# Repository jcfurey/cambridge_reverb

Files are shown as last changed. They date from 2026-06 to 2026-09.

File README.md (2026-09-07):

# Vox Cambridge Reverb (V1031/V1032) — Electronics Rebuild

Complete electronics rebuild of a Vox Cambridge Reverb solid-state guitar amplifier:
the original electronics are gutted and replaced with modern parts while preserving
the original functionality, the front/rear panel layout (no new holes), and the
chassis. Guitar-frequency and 10″ alnico-speaker optimized throughout.

> **Honesty up front:** the Part 1–10 design docs were **reconstructed** from a prior
> conversation (see `docs/PROVENANCE.md`); some values were gap-filled. The KiCad
> project, BOM, and ngspice sims are **generated and tool-verified** (ERC/DRC/SPICE
> all pass), but the board is **placed, not routed**, and a few stages are designed
> substitutes. Treat the signal chain and power section as *validated design intent*,
> and re-verify part numbers/values before ordering or building.

## Core design decisions

| Block | Replacement |
|---|---|
| Power amp | LM1875T (replaces germanium push-pull; eliminates driver transformer T2) |
| Preamp JFETs | MMBF5457 (SOT-23: direct on the SMD variant, on an adapter for THT) or J113 (2N5457 discontinued) — **availability watch**; pins 1 D / 2 S / 3 G (errata #18) |
| Reverb / tremolo | TL072 ×2 (no transformer T3): IC1 = tank driver + **active wet/dry summer**; IC2 = tremolo LFO + **output buffer** |
| Reverb pan | Accutronics 4FB2A1C (~1475 Ω input) — 8 Ω 4AB3C1B is **incompatible** |
| Tremolo modulation | Xvive VTL5C1 or DIY LED/LDR optocoupler, driven by a TL072 Wien LFO — **symmetric, dual-gang 250 k speed pot, 0.6–10.6 Hz** (errata #19: the recovered single-arm pot could not oscillate at tremolo rates); LED-limited LFO + **2N3904 emitter-follower LED driver, 15 dB depth** (errata #22: as drawn the vactrol LED ran at 7 mA DC — a fixed −20 dB pad with 1.7 dB of wobble) |
| Power | LM317T-regulated +17 V rail with **`C_adj`** and an RC-decoupled **`+17V_PRE`** rail for the JFET stages (errata #21: the regulator's noise sat 23 dB above the JFET floor); split `VBIAS_R`/`VBIAS_T`/`VBIAS_3` mid-rails; KBP410G bridge; `VREG_IN` RC pre-filter; **bypassed LM1875 bias divider** (errata #21: as drawn it fed rail ripple ×23 to the speaker — 0.4 Vrms of hum) |
| Tone | **Bass + Treble** (the panel's pots) on a passive James / Thomas-Vox network with a TL074 buffer + make-up (IC3), 470 pF chime cap as a bright cap, and a **MID CUT toggle** (−9.6 dB @ ~800 Hz, broad) in the line-reverse switch hole — errata #20 (the recovered 470 pF-only coupling passed no bass at all) |

## What's verified (all via real tools, in CI-able commands)
- **Schematic:** generated by `kicad/gen/gen_kicad.py` → 8 hierarchical sheets, **ERC 0 violations** (KiCad 8.0.9). 146 components + 28 test points.
- **PCB:** `kicad/gen/gen_pcb.py` places every footprint into the **Part 5 floor-plan zones** (datasheet-derived LM1875 / KBP bridge footprints, real can sizes, Part 4 wire pads, mounting holes; **0 DRC errors, 0 warnings before routing**), plus a **labelled bench test-point strip per zone** (28 `TP_*`: rails, JFET drains, mid-rail refs, every inter-stage node, PA output, a GND pin per zone), then `kicad/gen/route_board.py` **autoroutes headlessly** with Freerouting. **215 of 222 connections routed (incl. the 28 test points), 1 DRC error** (a starved thermal spoke), **0 hits on the two crosstalk clearance rules**, 86 vias, bottom layer kept as a near-solid GND pour (0.9 m of jumpers vs 5.6 m on top); the seven open links are listed in the notes. The board packs tighter since the Bass/Treble stack (errata #20) — the previous placement reached 167/168. See `kicad/PCB-NOTES.md`.
- **Mixed SMD/THT variant** (`kicad/smd/`, **155×90 mm** for the Part 7 safe-bet chassis): same schematic through a second footprint profile — 90 small parts on 0805/1206/1210/SMA/SOD-123/SOT-23, power parts / electrolytics / socketed op-amps / trim resistors / connectors stay THT. **210 of 223 connections routed, 4 DRC errors** (starved thermal spokes), rules clean, on the 155×90 board; the thirteen open links (four of them pour stitching — the price of the crosstalk rules on a 56 %-full board) are listed in the notes. JLCPCB-assembly BOM + position file in `production/smd/`.
- **BOM:** generated from the schematic by `kicad/gen/gen_bom.py` (1:1 with the netlist, no drift) → `bom/bom.csv` + `bom/bom-grouped.csv` (THT) and `bom/bom-smd*.csv` (variant).
- **Noise / hum / crosstalk / thermal** (`docs/06c-…`): `.noise` of the whole front end with the regulator's own noise (EIN 37 → 2.7 µV, SNR at 12 W 34 → 57 dB after errata #21), rail-ripple paths (hum 408 mV → 0.3 mV at the speaker), a vactrol-level tremolo model (depth 1.7 → 15 dB, errata #22), a geometric **crosstalk audit** of both routed boards feeding two routing clearance rules, and an electro-thermal LM1875 model (2.5 K/W sink: Tj 97 °C at 40 °C ambient, worst-case sine).
- **JLCPCB:** both projects carry JLC's 2-layer limits as DRC constraints (two footprints were under the annular-ring minimum and are fixed), the SMD board has fiducials, every SMD capacitor is a basic-library 1206, optional parts are DNP — 7 → 2 extended part types, assembly ≈ $17 for five boards (`kicad/gen/jlc_cost.py`).
- **SPICE:** `spice/run_all.sh` runs 12 ngspice block checks (preamp bias, reverb driver, MRB, tremolo LFO, power amp, **rail-aware** reverb summer, **rail-aware** tone stack, Class-A stage, front-end noise, hum paths, tremolo depth, LM1875 thermal) **plus 6 parameter sweeps** (JFET bias vs R_s across the datasheet Idss spread, Bass / Treble pots + mid-cut switch, LFO speed pot — recovered and fixed networks, Class-A bias, power-amp headroom vs mains ±10 %) and saves every result table to **`spice/results/`** (committed evidence).

## Honest engineering notes (from the audit/roast passes — see `docs/roast-2026-06-16.md`)
- 🔴 **Output power ≈ 12 W, not 18 W.** A single 33.5 V rail can't swing the 17 V peak that 18 W into 8 Ω needs; the LM1875 ceilings at ~12 W clean (~1.8 dB down). Fine for a 10″ combo.
- 🔴 **Fit a MAINS (primary) fuse** — the design's other fuse is only on the secondary. Required for safety.
- ⚠️ **Chassis fit:** the board is **190×115 mm** (matches the original 25-5274-2). Real (text-less) packing is **~40 %** there (THT parts) and **~54 %** for the SMD-profile parts on the Part 7 155×90 "safe-bet" (the THT parts would need 68 % of it) — the earlier 53 % / 90 % figures counted hidden text. Measure the real chassis before committing to a size (errata #9); the placer rebalances to any outline.

## Key constraints
- No new holes in original panels; all improvements internal only.
- MRB hardwired to 600 Hz (original spec); tremolo rate LED is PCB-mounted (diagnostic).
- Original 6-pin DIN footswitch connector and pedal retained.

## Repository layout

```
docs/         Parts 1–10, errata, PROVENANCE, audits (component-availability, roast)
kicad/        Generated KiCad project + gen/ scripts; symbols/ footprints/ gerbers/;
              SCHEMATIC-BUILD / PCB-NOTES / PCB-AUDIT
spice/        ngspice block sims + run_all.sh + models/ (LTspice power-amp kept for provenance)
bom/          bom.csv (generated), bom-grouped.csv, cross-check
datasheets/   sourcing pointers (SOURCES.md)   photos/  capture checklist
production/   fab-package checklist
```

## Tools
- **EDA / verification:** KiCad 8 (`kicad-cli` ERC/DRC). `kicad/gen/check.sh tht|smd` regenerates a profile and writes ERC/DRC reports to `kicad/reports/` (add `--no-regen` to verify a routed board); route with `python3 kicad/gen/route_board.py` (Freerouting 1.9.0 jar + Java + xvfb, see the script)
- **Datasheets:** `datasheets/` holds the manufacturer PDFs the footprints and pinouts were taken from, with a manifest (`SOURCES.md`: file, revision, checksum, which decision it backs)
- **Simulation:** ngspice (`spice/run_all.sh`); LTspice netlist kept for the power amp
- **PCB fab / sourcing:** JLCPCB · Mouser / Digikey

## Status
Reconstructed Parts 1–10 + errata, then multiple verify/audit/roast passes:
generated ERC-clean schematic, floor-plan-placed and **autorouted** PCB, generated
BOM, runnable ngspice suite, and circuit fixes (mains fuse, power-ceiling
correction, active effects-chain redesign, split bias, Bass/Treble tone stack + mid cut).
**Remaining:** hand-review of the autorouted copper (audio-sensitive nets, star
ground, the fat power loop), chassis measurement → final outline, Gerbers, and
bench-tuning the tremolo/MRB. See `CHANGELOG.md`.

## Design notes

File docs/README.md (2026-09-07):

# docs/

Reconstructed design documentation. **Read `PROVENANCE.md` first** — these were
rebuilt from recovered conversation fragments, not the original files.

- `PROVENANCE.md` — how these were reconstructed and what to re-verify
- `01-modernization-guide.md`
- `02-bom-schematics.md`
- `03-wiring-harness.md`
- `04-jlcpcb-fabrication.md`
- `05-thermal-placement.md`
- `06b-spice-simulations.md`
- `06c-noise-hum-crosstalk-thermal.md` — noise, hum, tremolo depth, crosstalk audit, LM1875 thermal model (2026-09-07)
- `07-chassis-measurement.md`
- `08-verified-bom.md`
- `09-transformers-magnetics.md`
- `10-kicad-project.md`
- `errata.md`

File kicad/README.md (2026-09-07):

# kicad/

KiCad project files.

## Present now
- `cambridge_reverb.kicad_pro` — project with reconciled design rules and **three
  net classes** from the consistency pass: Default 0.5 mm / Power 1.5 mm /
  HighCurrent 2.5 mm (errata #11–13). `+33V5`/`SPK_P`/`SPK_N`/`PA_OUT` are pre-assigned
  to HighCurrent by net-name pattern.
- `symbols/cambridge_reverb.kicad_sym` — custom symbols: `VTL5C1`,
  `Reverb_Tank_4FB2A1C`, `Footswitch_DIN6`.
- `footprints/cambridge_reverb.pretty/` — `VTL5C1`, `Inductor_MRB_1H_Toroid`
  (2-pad, 25 mm), **`TO-220-5_Vertical_P1.70mm_LM1875`** (TI NDH inline TO-220-5
  with 1.45 mm pads — fixes the annular-ring DRC error of the stock footprint,
  PCB-AUDIT §1), **`Bridge_KBP_P3.81mm`** (Diodes KBP410G, DS39310, pins
  + ~ ~ −), **`TestPoint_THT_D2.0mm_Label`** (bench test point, value printed on
  silk) and the **`WirePad_*`** wiring pads. `Wiring_Edge_Array_35` (35-pad edge connector) is also in the
  library but **currently unused** — `gen_pcb.py` places per-connector
  **`WirePad_1x0N_P2.54mm_D1.2mm` / `WirePad_1x0N_P5.08mm_D1.5mm`** pads (the Part 4
  signal / power wire-pad sizes) along the wiring edge instead; the 35-pad array
  is kept as a reference (roast R4).
- `sym-lib-table` / `fp-lib-table` — register the project libraries (`${KIPRJMOD}`).
- `netlist-notes.txt` — recovered per-sheet connections (power amp, reverb,
  tremolo, MRB).
- `SCHEMATIC-BUILD.md` — step-by-step to build the 8 hierarchical sheets.

## Generated schematic (now present)
- `cambridge_reverb.kicad_sch` (root) + 8 hierarchical sheets — `power_supply`,
  `preamp`, `tone_stack`, `reverb`, `tremolo`, `mrb`, `power_amp`, `switching`.
  They open in KiCad 7/8, **pass ERC with 0 violations** (KiCad 8.0.9), and
  netlist cleanly (138 components + 28 test points, 0 unconnected pins).
- `symbols/cr_primitives.kicad_sym` — self-contained primitive symbols used by
  the generated sheets.
- `gen/gen_kicad.py` — the generator (regenerate: `python3 kicad/gen/gen_kicad.py`).
- `SCHEMATIC-BUILD.md` — how the sheets are wired, what's verified, and the
  known simplifications to finish before a build.

## PCB (generated: zoned placement + headless autoroute)
- `cambridge_reverb.kicad_pcb` — generated by `gen/gen_pcb.py`: 113 footprints
  placed into the **Part 5 floor-plan zones** (Input/Preamp | Tone | Reverb/Trem |
  Power Amp | PSU, left→right), off-board connectors on the bottom wiring edge,
  LM1875/LM317 on the top edge with the 10 mm keep-out, 4× M3 mounting holes,
  190×115 mm outline, bottom GND pour — **0 DRC errors, 0 warnings before routing**.
- `gen/route_board.py` — **headless autoroute** via Freerouting (DSN → SES →
  import, GND pour refilled). Needs Java + the Freerouting jar (git-ignored; see
  the script docstring). It also injects the per-class *routing* clearances
  (HighCurrent 0.6 mm, TankDrive 1.2 mm) that `cambridge_reverb.kicad_dru` checks
  afterwards for tracks/vias. Routing status and numbers: `PCB-NOTES.md`.
- `gen/crosstalk_audit.py` — geometric **crosstalk screen** of a routed board:
  mutual capacitance of parallel runs between power/AC/tank-drive nets and the
  sensitive nodes, coupled level vs signal, loop gain (Part 6c §4).
- `gen/jlc_cost.py` — JLCPCB assembly **cost model** from the generated BOM (joints,
  basic vs extended part types) — Part 4.
- `gen/check.sh tht|smd [--no-regen]` — regenerate + ERC/DRC with the **JLCPCB
  fab limits** stored in both `.kicad_pro` files (hole-to-hole 0.5, hole-to-copper
  0.3, annular 0.18, mask dam 0.1 mm …) and the custom `.kicad_dru` rules.

## `smd/` — the mixed SMD/THT variant (same schematic, second footprint profile)
- `smd/cambridge_reverb_smd.kicad_pro/.kicad_sch` + the 8 sheets, `smd/cambridge_reverb_smd.kicad_pcb`
  (**155 × 90 mm**, the Part 7 safe-bet size): generated with `--profile smd` by the
  same three scripts. Small passives and semis are SMD (0805 R, 1206/1210 C,
  SMA/SOD-123 D, SOT-23 JFETs); power parts, all electrolytics, the socketed
  TL072s / TL074, the bench-trimmed JFET source resistors, connectors and test points stay
  THT. Lib tables point at the shared `../symbols` / `../footprints`.
  Details and routing status: `PCB-NOTES.md` (SMD variant section).

## Still to do in the KiCad GUI
- Review the autorouted result (it is an autorouter: expect to tidy the audio
  paths, star-ground, and the HighCurrent loop by hand), show reference
  designators on the silkscreen, and confirm the board size against the measured
  chassis (errata #9).
- Gerbers per Part 4 / `production/CHECKLIST.md`.
- `gerbers/` — exported Gerbers (git-ignored; regenerate per Part 4).

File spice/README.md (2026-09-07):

# spice/

ngspice simulations for the design blocks: **8 fixed-point block checks** and
**6 parameter sweeps**. `./run_all.sh` runs everything and writes each result
table to **`results/<name>.txt`** — those files are committed as the evidence for
the numbers below (re-run and diff after any value change). The original set was
LTspice (only the power-amp netlist was recovered verbatim; kept as
`power_amp_lm1875.cir` for provenance, it does not run under ngspice).

Requires ngspice (`apt install ngspice`; verified with ngspice-42).

## Files
| File | Block | What it checks |
|---|---|---|
| `dc_preamp_jfet.cir` | Preamp | JFET bias point + midband gain (recovered R_s = 2.2 k) |
| `ac_reverb_driver.cir` | Reverb driver | Non-inverting gain (11×) |
| `ac_mrb.cir` | MRB | Resonant-peak frequency |
| `tran_tremolo_lfo.cir` | Tremolo LFO | Oscillation + rate at the fast end of the **errata #19** network |
| `ac_power_amp_lm1875.cir` | Power amp | Gain + LF/HF −3 dB with `C_fb_hf` + a 10″ speaker model |
| `tran_reverb_mixer.cir` | Reverb summer | **Rail-aware**: mid-rail bias, unity sum, headroom / clipping |
| `ac_tonestack.cir` | Tone | **Rail-aware**: IC3 bias, noon response, MID CUT on/off (errata #20) |
| `tran_classa_output.cir` | Class-A stage | AB vs A: idle current and crossover THD |
| **`noise_frontend.cir`** | whole front end | `.noise` 20 Hz–20 kHz incl. the LM317's rail noise; EIN, SNR at 12 W, per supply fix (Part 6c) |
| **`ac_hum_psrr.cir`** | PSU → PA / preamp | Rail-ripple paths to the speaker (bias divider, LM317 → JFETs), before / after errata #21 |
| **`tran_tremolo_depth.cir`** | Tremolo | LFO → LED driver → behavioural VTL5C1 → audio: depth in dB, as drawn vs errata #22 |
| **`tran_thermal_lm1875.cir`** | Power amp | Electro-thermal RC ladder: Tj vs heatsink / ambient, heatsink saturation time |
| `models/opamp_noise.sub` | shared | Op-amp macromodel with an en source and noiseless internals, for `.noise` |
| **`sweep_preamp_bias.cir`** | Preamp | **Vd vs R_s for LO / TYP / HI JFET corners** (datasheet Idss 1–5 mA) |
| **`sweep_tonestack.cir`** | Tone | Bass / Treble pot travel + the mid-cut switch |
| **`sweep_lfo_speed.cir`** | Tremolo LFO | Rate and amplitude vs the speed pot (built network) |
| **`sweep_lfo_speed_recovered.cir`** | Tremolo LFO | The recovered single-arm network — evidence for errata #19 |
| **`sweep_classa_bias.cir`** | Class-A stage | Standing current, heat and THD vs the bias spreader |
| **`sweep_pa_headroom.cir`** | Power amp | Clean output ceiling vs the rail (mains −10 % … +10 %) |
| `models/opamp1p.sub` | shared | One-pole op-amp macromodel (small-signal, **no rails**) |
| `models/opamp_rail.sub` | shared | **Rail-aware** one-pole op-amp (output clamped to the supplies) |
| `models/jfet_2n5457.lib` | shared | 2N5457/MMBF5457 nominal model (Idss ≈ 3 mA, Vp = −1.8 V) |
| `run_all.sh` | — | Runs everything, saves `results/`, exit ≠ 0 if ngspice fails |

## Fixed-point results (`results/*.txt`, ngspice-42)
| Block | Measured | Documented | Verdict |
|---|---|---|---|
| Power amp midband gain | **27.21 dB** (23.0×) | 23× / 27.2 dB | ✅ |
| Power amp HF −3 dB | **6.83 kHz** | ~7.2 kHz (`C_fb_hf`) | ✅ |
| Power amp LF −3 dB | **17.2 Hz** | "7.2 Hz" (C_gain only) | ⚠️ input pole adds a second LF corner — fine for guitar |
| Reverb driver gain | **20.83 dB** (11.0×) | 11× | ✅ |
| MRB resonant peak | **577 Hz** | ~610 Hz (1 H ‖ 68 nF) | ✅ (pulled low by the output network) |
| Tremolo LFO, pot at min | **10.59 Hz**, 0.48 V amplitude | 10.6 Hz = 1/(2π·15 k·1 µF) | ✅ (errata #19 network) |
| Preamp drain Vd (R_s = 2.2 k, nominal JFET) | **12.1 V** | 8–9 V target | ⚠️ see the sweep below |
| Reverb summer bias / gain / clip | **8.50 V**, **0.0 dB**, clips 15.5 / 1.5 V | mid-rail, unity, ±7 V | ✅ |
| Tone stack, pots at noon / MID CUT on | **−0.21 dB** flat 100 Hz–10 kHz / **−9.6 dB @ 796 Hz**; all IC3 nodes 8.50 V | flat / ~−10 dB @ ~800 Hz, mid-rail | ✅ (errata #20) |
| Class-A stage AB → A | THD 1.05 % → 0.0025 %, idle 0.11 → 0.49 A | crossover removed | ✅ |
| Front-end noise, as drawn → errata #21 | EIN **37 µV → 2.7 µV** rms; SNR at 12 W **34 → 57 dB** | LM317 noise was 23 dB above the JFET floor | ✅ fixed |
| Hum at the speaker (0.25 Vrms rail ripple), as drawn → #21 | **408 mV → 0.3 mV** rms (−28 → −90 dB re 12 W) | unbypassed PA bias divider | ✅ fixed |
| Tremolo depth, as drawn → errata #22 | **1.7 dB → 15 dB**; insertion loss −19.5 → −0.8 dB | vactrol LED was 7 mA DC | ✅ fixed |
| LM1875 Tj, 2.5 K/W sink, worst sine, Ta 40 °C | **97 °C** (4 K/W: 111; 8 K/W: 149) | < 150 °C | ✅ Part 5 spec confirmed |

## Sweeps
### JFET bias vs R_s across the device spread (`sweep_preamp_bias`, errata #15)
Drain voltage (V) on the +17 V rail with R_d = 10 k. Corners: LO = Idss 1 mA / Vp −0.8 V,
TYP = 3 mA / −1.8 V, HI = 5 mA / −3.0 V (2N5457 & MMBF5457 limits, datasheets committed).

| R_s (Ω) | Vd LO | Vd TYP | Vd HI |
|---:|---:|---:|---:|
| 470 | 11.9 | 3.9 | 1.5 |
| 680 | 12.8 | 6.3 | 1.9 |
| **1000** | 13.6 | **8.5** | 2.9 |
| 1200 | 14.0 | 9.5 | 4.5 |
| 1800 | 14.7 | 11.3 | 7.5 |
| **2200** | 15.0 | 12.1 | **8.8** |
| 2700 | 15.3 | 12.8 | 10.0 |

Reading: the recovered **2.2 k is right for a high-Idss part**; a typical part wants
**~1.0 k**; a low-Idss part (1 mA) cannot reach 8–9 V with any R_s — it needs a
larger R_d or should be rejected. Hence "trim per device": measure Idss once
(drain to +17 V via 10 k, gate/source grounded) and pick R_s from the row above.
This is why `R_s1`, `R_s2`, `R_rec2` stay through-hole even on the SMD variant.

### Bass / Treble pots and the MID CUT (`sweep_tonestack`, errata #20)
Passive James network (250 k lin pots) + TL074 buffer / ×2 make-up, volume at max,
gain in dB re the Q2 drain signal. 0 = fully counter-clockwise (cut), 1 = clockwise (boost).

| Bass pot | 60 Hz | 100 Hz | 200 Hz | 400 Hz | 1 kHz |
|---:|---:|---:|---:|---:|---:|
| 0 (cut) | −11.3 | −7.5 | −3.2 | −1.0 | −0.3 |
| 0.5 | −0.3 | −0.3 | −0.2 | −0.2 | −0.2 |
| 1 (boost) | +5.2 | +4.9 | +3.6 | +1.6 | +0.1 |

| Treble pot | 1 kHz | 2 kHz | 3 kHz | 5 kHz | 10 kHz |
|---:|---:|---:|---:|---:|---:|
| 0 (cut) | +0.2 | −1.1 | −6.8 | −10.7 | −16.5 |
| 0.5 | −0.2 | −0.2 | −0.2 | −0.2 | −0.2 |
| 1 (boost) | −0.2 | +2.4 | +5.0 | +5.5 | +5.6 |

| MID CUT | 200 Hz | 400 Hz | 600 Hz | 800 Hz | 1 kHz | 1.5 kHz | 2 kHz | 4 kHz |
|---:|---:|---:|---:|---:|---:|---:|---:|---:|
| off | −0.2 | −0.2 | −0.2 | −0.2 | −0.2 | −0.2 | −0.2 | −0.2 |
| **on** | −0.9 | −3.2 | −7.1 | **−9.7** | −7.7 | −3.6 | −2.2 | −1.0 |

Noon is flat (the ×2 make-up cancels the network's centre loss); the controls
are asymmetric — more cut than boost — as the passive Vox networks were, and
the mid cut is a broad (Q ≈ 0.6) notch at the "honk" band, not a surgical one.

### Tremolo LFO vs the speed pot (`sweep_lfo_speed` — the built network)
Symmetric Wien, 15 k + one gang of a dual 250 k pot per arm, 1 µF, gain 3.13 + diode limiter.

| Pot (Ω) | f theory | f measured | Vpp |
|---:|---:|---:|----:|
| 0 | 10.61 Hz | **10.58 Hz** | 0.96 |
| 50 k | 2.45 Hz | 2.44 Hz | 0.96 |
| 100 k | 1.38 Hz | 1.38 Hz | 0.96 |
| 250 k | 0.60 Hz | **0.60 Hz** | 0.96 |

### …and the recovered network (`sweep_lfo_speed_recovered` — why it was changed)
Single-arm pot: series 10 k + 0–500 k, shunt 33 k, 100 nF.

| Pot (Ω) | Series R | f theory | Result |
|---:|---:|---:|---|
| 0 | 10 k | 87.6 Hz | oscillates, **79.6 Hz**, 1.6 Vpp |
| 20 k | 30 k | 50.6 Hz | oscillates, 50.2 Hz, 1.1 Vpp |
| 27 k | 37 k | 45.5 Hz | marginal, 0.4 Vpp |
| 35 k … 500 k | 45 k … 510 k | 41 … 12 Hz | **no oscillation** |

The Wien start condition is gain > 2 + R1/R2; with a fixed gain of 3.13 the series
arm must stay under ~37 k, so the recovered LFO ran only over ~5 % of the pot and
never below 45 Hz. Errata #19.

### Class-A bias (`sweep_classa_bias`) — the heat/distortion trade
Single +33.5 V rail, ~0.7 W into 8 Ω (0.38 A peak load).

| Bias per base (V) | Standing current | Standing heat | THD |
|--:|--:|--:|--:|
| 0.60 | 0.111 A | 3.7 W | 1.41 % |
| 0.66 | 0.119 A | 4.0 W | 0.40 % |
| 0.70 | 0.173 A | 5.8 W | 0.049 % |
| 0.72 | 0.276 A | 9.2 W | 0.0084 % |
| **0.74** | **0.488 A** | **16.3 W** | **0.0025 %** |
| 0.76 | 0.845 A | 28.3 W | 0.0022 % |

Crossover distortion is gone once the idle current exceeds the peak load current
(≈ 0.4 A); beyond that only the heat grows. 0.74 V ≙ the 0.5 A CCS in the Class-A
variant (`docs/classA-power-amp.md`).

### Power-amp headroom vs mains (`sweep_pa_headroom`, roast R2)
Rail-aware LM1875 model (vsat 3 V), gain 23, 8 Ω, driven into clipping.

| Rail | Output DC | Clean peak swing | Sine power into 8 Ω |
|--:|--:|--:|--:|
| 30.0 V (mains −10 %) | 15.0 V | 11.9 V | **8.9 W** |
| 33.5 V (nominal) | 16.75 V | 13.7 V | **11.7 W** |
| 37.0 V (mains +10 %) | 18.5 V | 15.4 V | **14.8 W** |

Confirms the ~12 W ceiling (not 18 W) and shows it is a mains-voltage lottery of
±3 W. The output DC tracks V+/2 exactly, which is what `TP_PA_OUT` should read.

## Scope caveat (roast R7)
`opamp1p.sub` is rail-less: gain/bandwidth of isolated blocks only. Large-signal
behaviour is covered only where `opamp_rail.sub` is used (reverb summer, headroom
sweep) and in the transistor-level Class-A stage. The LM1875 is a behavioural
model (Aol, GBW, saturation), not TI's — the headroom numbers are a model of the
ceiling, not a measurement. Component tolerances are covered only where swept.

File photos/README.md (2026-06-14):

# photos/
Chassis measurements, panel layout, and build-progress photos.

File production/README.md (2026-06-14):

# production/
JLCPCB fabrication packages (zipped Gerbers), assembly drawings, pick-and-place.

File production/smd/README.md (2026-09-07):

# JLCPCB assembly inputs — mixed SMD/THT variant (`kicad/smd/`)

Generated; do not hand-edit. Regenerate after any schematic/placement change:

```
python3 kicad/gen/gen_bom.py --profile smd --jlc
kicad-cli pcb export pos --side front --format csv --units mm --smd-only --exclude-dnp \
    -o production/smd/cambridge_reverb_smd-top-pos.csv kicad/smd/cambridge_reverb_smd.kicad_pcb
```

| File | What |
|---|---|
| `bom-jlcpcb.csv` | JLCPCB BOM format (Comment, Designator, Footprint, LCSC Part #) for the **91 placed SMD parts** (29 lines; the two "(opt)" MRB caps are DNP and excluded). The LCSC column is empty on purpose: pick "basic" parts in the JLC parts picker (0805 1 % resistors, 1206 X7R/C0G, S1M, MMBT3904) — only the MMBF5457 and the 3.09 k E96 resistor are unavoidably "extended" ($3/type). `kicad/gen/jlc_cost.py` prints the cost model. |
| `cambridge_reverb_smd-top-pos.csv` | kicad-cli position (CPL) file, top side, SMD only, mm, DNP excluded; includes the three fiducials `FID1–3` (1 mm copper / 2 mm mask) for the placement camera. JLC expects the header names `Designator,Mid X,Mid Y,Layer,Rotation`; rename the columns (Ref→Designator, PosX→Mid X, PosY→Mid Y, Side→Layer, Rot→Rotation) when uploading, or use the "KiCad" template in their uploader. Check SOT-23 / diode rotations in their preview — KiCad's 0° and JLC's 0° differ for some packages. |

The ~76 through-hole parts (power devices, electrolytics, socketed op-amps, the
trimmed JFET source resistors, connectors, test points, vactrol, toroid, fuse
clip) are hand-soldered afterwards; see `bom/bom-smd.csv` for the full list.

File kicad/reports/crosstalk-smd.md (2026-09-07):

### Crosstalk screen — `cambridge_reverb_smd.kicad_pcb`

| Aggressor | Victim | C_m (pF) | longest run (mm) | f | on victim (µV) | vs signal (dB) | loop gain (dB) |
|---|---|---:|---:|---:|---:|---:|---:|
| `TANK_IN` | `TANK_OUT` (tank return (recovery gate)) | 0.18 | 4.6 | 5000 Hz | 166.1 | -42 |  |
| `TANK_IN` | `WET` (reverb level wiper) | 0.21 | 6.5 | 5000 Hz | 966.5 | -50 |  |
| `TANK_IN` | `SUMJ` (summer virtual ground: coupled charge x R_fb -> BLEND (1 V)) | 0.06 | 4.0 | 5000 Hz | 555.2 | -65 |  |
| `PA_OUT` | `PA_INV` (PA -in (1k||22k)) | 0.43 | 7.7 | 5000 Hz | 131.8 | -70 | -97 |
| `PA_OUT` | `PA_BIAS` (PA +in) | 0.05 | 2.6 | 5000 Hz | 165.0 | -76 | -68 |
| `AC1` | `PA_IN` (PA input (22k||22k)) | 0.46 | 26.1 | 150 Hz | 115.5 | -79 |  |
| `TANK_IN` | `QRD` (recovery drain) | 0.02 | 1.7 | 5000 Hz | 20.7 | -83 |  |

Worst feedback loop: `PA_OUT` → `PA_BIAS`: loop gain **-68 dB** (forward 27 dB + coupling -95 dB); stable with margin if well below 0 dB.

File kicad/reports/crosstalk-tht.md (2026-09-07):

### Crosstalk screen — `cambridge_reverb.kicad_pcb`

| Aggressor | Victim | C_m (pF) | longest run (mm) | f | on victim (µV) | vs signal (dB) | loop gain (dB) |
|---|---|---:|---:|---:|---:|---:|---:|
| `TANK_IN` | `TANK_OUT` (tank return (recovery gate)) | 0.07 | 1.9 | 5000 Hz | 62.6 | -50 |  |
| `TANK_IN` | `SUMJ` (summer virtual ground: coupled charge x R_fb -> BLEND (1 V)) | 0.19 | 13.8 | 5000 Hz | 1800.3 | -55 |  |
| `TANK_IN` | `JB` (bass ladder) | 0.51 | 29.2 | 5000 Hz | 2409.9 | -62 |  |
| `TANK_IN` | `DRVP` (tank driver +in) | 0.07 | 5.5 | 5000 Hz | 615.5 | -64 |  |
| `PA_OUT` | `PA_BIAS` (PA +in) | 0.15 | 3.6 | 5000 Hz | 495.1 | -66 | -59 |
| `TANK_IN` | `JTA` (treble ladder) | 0.23 | 29.2 | 5000 Hz | 1079.0 | -69 |  |
| `PA_OUT` | `PA_INV` (PA -in (1k||22k)) | 0.24 | 7.3 | 5000 Hz | 74.6 | -75 | -102 |
| `TANK_IN` | `TONE_OUT` (volume wiper) | 0.03 | 1.3 | 5000 Hz | 147.4 | -77 |  |
| `TANK_IN` | `MID` (mid-cut node) | 0.04 | 1.3 | 5000 Hz | 37.0 | -92 |  |
| `+33V5` | `PA_BIAS` (PA +in) | 0.03 | 2.0 | 150 Hz | 0.1 | -142 |  |

Worst feedback loop: `PA_OUT` → `PA_BIAS`: loop gain **-59 dB** (forward 27 dB + coupling -86 dB); stable with margin if well below 0 dB.

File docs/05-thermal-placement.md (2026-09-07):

# Vox Cambridge Reverb — Part 5: Thermal, Placement & Assembly

> Reconstructed document — see `PROVENANCE.md`. Thermal conclusions, the floor
> plan, and the build timeline are recovered substantially verbatim; some
> numeric derivations are `[RECONSTRUCTED]`.

## Thermal — bottom line (recovered verbatim)

**LM1875 needs a heatsink rated ≤ 2.5 °C/W.** The original V1031 heatsink
bracket should work — it was designed for germanium transistors dissipating
comparable heat. Mount the LM1875 with a mica insulator, shoulder bushing, and
thermal grease.

**LM317 needs no heatsink** — it dissipates ~0.25 W powering the preamp. Bolt it
to the chassis if convenient, but thermally it's a non-issue.

`[RECONSTRUCTED]` **Corrected (roast R2):** the earlier "18 W into 8 Ω" premise is
unreachable on the 33.5 V single rail — the real output ceiling is **~12 W**. At
~12 W the LM1875's worst-case dissipation is *lower* than the old 15–20 W figure,
so with a ≤2.5 °C/W sink + mica the junction stays comfortably within limits (the
sink is over-spec'd, which is safe). Thermal shutdown backstops sustained drive.
Still verify against the LM1875 datasheet SOA/thermal curves for your duty cycle.

`[MODELLED 2026-09-07]` **Part 6c §5** puts numbers on it (`spice/tran_thermal_lm1875.cir`,
2 K/W junction-case + 1.6 K/W greased mica): worst-case continuous sine is **9.4 W** of
dissipation (at 7 W out, not at full power). Junction temperature with a **2.5 K/W** sink:
82 / 97 / 112 °C at 25 / 40 / 55 °C ambient — the spec above holds with margin. **4 K/W**
is still fine to 55 °C (126 °C); **6 K/W** passes a sine test only in a cool room (145 °C
at 55 °C); **8–10 K/W** clip-on sinks reach thermal shutdown on sustained notes. A 40 g
sink saturates in ~5 minutes (τ ≈ 145 s), so a set of loud songs equals the steady-state
sine column. Bolting the tab directly to a grounded sink (single supply: tab = GND) saves
~6 K. The LM317 now carries ~25 mA (IC3 + the tremolo LED driver): 0.4–0.5 W, +25 K bare
— still no heatsink, but chassis-mount it in a hot cabinet.

## Component placement floor plan (recovered verbatim)
```
+-------------------------------------------------------------+
|  190 mm                                                     |
|  +---------+----------+----------+----------+----------+     |
|  | INPUT / |  TONE    | REVERB / |  POWER   |  POWER   |  ^  |
|  | PREAMP  |  STACK   | TREMOLO  |  AMP     | SUPPLY   | 115 |
|  | Q1,Q2   | passives | TL072s   | (LM1875) | BR1,U1   | mm  |
|  |         |          | VTL1     |          | C_main   |  v  |
|  +---------+----------+----------+----------+----------+     |
|  o o o o o o o o o WIRING EDGE (all pads) o o o o o ...      |
+-------------------------------------------------------------+
```
Signal flows left → right. All off-board wiring exits one edge so the board can
flip up for service.

## Keep-out zones (recovered verbatim)
- 10 mm clearance around LM1875 and LM317 mounting area
- No signal traces within 15 mm of transformer wiring pads
- No traces under LFO timing components (noise sensitive)

## Suggested build timeline (recovered verbatim)

| Week | Task |
|---|---|
| 1 | Photograph and document original amp. Test transformer. Remove original PCB. |
| 2 | Create KiCad schematic (Part 2 reference). Run ERC. |
| 3 | PCB layout in KiCad (Parts 4 & 5). Run DRC. |
| 4 | Order PCBs from JLCPCB. Order components from Mouser. |
| 5 | (Wait for delivery — 7–14 days.) |
| 6 | Populate power supply first. Test DC rails. |
| 7 | Populate preamp and tone stack. Test with signal generator. |
| 8 | Populate reverb, tremolo, MRB. Test each effect. |
| 9 | Populate power amp. Test at low volume with series light bulb. |
| 10 | Install PCB in chassis. Wire control and rear panels. |
| 11 | Final testing, biasing, burn-in at full volume. |
| 12 | Button it up, play it, enjoy it. |

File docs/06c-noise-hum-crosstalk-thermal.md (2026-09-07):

# Vox Cambridge Reverb — Part 6c: Noise, Hum, Crosstalk and Thermal Models

> Added 2026-09-07. Everything here is reproducible: the netlists live in `../spice/`
> (`spice/run_all.sh` writes the tables to `spice/results/`), the board audit is
> `kicad/gen/crosstalk_audit.py`. Part 6b covers the functional block checks; this part
> asks the questions a bench would ask *after* the amp works: how quiet, how much hum,
> what talks to what on the board, and how hot.

## 1. Noise — `spice/noise_frontend.cir`

Full front end in one `.noise` run: single-coil pickup (6 kΩ + 2.5 H, 470 pF cable) →
JFET preamp → passive James tone stack + TL074 make-up → summer → output buffer →
LM1875 (×23). Op-amps are 18 nV/√Hz voltage-noise sources (`models/opamp_noise.sub`,
every internal resistor declared noiseless), JFETs carry channel + flicker noise, and the
**+17 V rail carries the LM317's own noise** — TI specifies 0.003 % of V_out rms over
10 Hz–10 kHz, i.e. **~510 µV rms**, ~5 µV/√Hz. That matters because a resistor-loaded
common-source JFET stage has essentially **0 dB PSRR**: v_drain/v_rail = r_ds/(r_ds+R_d) ≈ 0.98.

| Supply configuration | Q2 drain noise (rms, 20 Hz–20 kHz) | Input-referred (EIN) | Hiss at the speaker | SNR at 12 W |
|---|---:|---:|---:|---:|
| **As drawn** (no ADJ cap, JFET loads on the raw +17 V) | **10.3 mV** | **37 µV** | 193 mV rms | **34 dB** |
| + `C_adj` 10 µF on the LM317 ADJ pin (~10× less regulator noise) | 1.26 mV | 4.5 µV | 24 mV | 52 dB |
| + `R_pre` 100 Ω / `C_pre` 220 µF decoupled `+17V_PRE` rail for Q1/Q2/Q_rec | 0.75 mV | **2.7 µV** | 14 mV | **57 dB** |
| (reference: rail noise switched off) | 0.75 mV | 2.7 µV | 14 mV | 57 dB |

The regulator was the dominant noise source by **23 dB**; the last row shows the two
cheap parts bring the preamp to its own floor (2.7 µV rms ≈ 19 nV/√Hz input-referred —
the pickup's 6 kΩ alone is 10 nV/√Hz). Both fixes are in the schematic (errata #21).
Remaining floor by contributor at 1 kHz: JFET channel noise + R_d, then the tone stack's
68 k / 10 k network and the ×2 make-up (~4 dB of the total), then the 100 k summer.

## 2. Hum — `spice/ac_hum_psrr.cir`

1 V of 100/120 Hz ripple on +33V5 (real: ~0.25 Vrms at full drive across 4700 µF),
two paths to the speaker:

| Path | As drawn | Fixed |
|---|---:|---:|
| **(A)** LM1875 input bias divider `R_bias1/R_bias2` 22k/22k from +33V5 — no bypass, the divider feeds the + input directly | **+4.3 dB** (ripple → speaker, i.e. ×1.6) → **408 mV rms of hum, −28 dB re 12 W** | divider node bypassed (`C_bref` 100 µF) and fed to the + input through `R_bias3` 22 k: **−58 dB**, 0.3 mV |
| **(B)** +33V5 → 100 Ω/2000 µF → LM317 (65 dB) → +17 V → JFET drains (0 dB PSRR) → ×13 → ×23 | −57 dB, 0.36 mV | with `C_adj` (80 dB): −72 dB; with the `+17V_PRE` RC too: −95 dB |

Path A was the design's loudest defect: an idle amp humming at −28 dB below full power.
The textbook single-supply input network (bypassed divider + series resistor) is now on
the power-amp sheet; the LM1875's own 52 dB PSRR handles the supply pin. Total hum after
the fixes: **0.3 mV rms at the speaker, −90 dB re 12 W**.

## 3. Tremolo depth — `spice/tran_tremolo_depth.cir`

Errata #19 fixed the LFO; this model follows the modulation to the audio, with a
behavioural VTL5C1 (datasheet LDR-vs-LED-current curve: 20 k @ 1 mA, 600 Ω @ 10 mA,
200 Ω @ 40 mA, 50 MΩ dark; ~5 ms response) shunting the 10 k series resistor.

| | LFO swing | Vactrol LED current | LDR | Insertion loss | **Depth** |
|---|---:|---:|---:|---:|---:|
| As drawn (LED from the depth-pot wiper via 1 k to GND) | 0.50 V pk | 6.4–7.4 mA **DC** | 960–1200 Ω | **−19.5 dB** | **1.7 dB** |
| Redesign | 2.1 V pk | 0–4.7 mA | 1.9 k–50 MΩ | −0.8 dB | **15 dB** |

The LFO sits at the 8.5 V mid-rail, so wiring its LED to ground gave 7 mA of DC with a
±0.5 mA wiggle: the vactrol was a fixed −20 dB pad, not a tremolo. Redesign (errata #22):
the 1N4148 limiter pair becomes two antiparallel **red LEDs** across `R_lfo_fb1` (knee
~1.6 V → 2 V swing; one of them *is* the rate indicator, so `LED_rate`/`R_led_diag` go
away), and an NPN emitter follower (`Q_trem`, 2N3904/MMBT3904), AC-coupled from the depth
pot (`C_drv` 100 µF, base biased at ~0.9 V by 180 k/10 k, `R_e` 470 Ω) drives the vactrol
LED from +17 V through `R_c` 100 Ω: 0…6 mA at the LFO rate, 15 dB of depth at maximum,
0.8 dB insertion loss. The half-wave drive plus the LDR's 35 ms decay give a smooth,
slightly asymmetric pulse — the classic optical-tremolo feel.

## 4. Crosstalk on the routed boards — `kicad/gen/crosstalk_audit.py`

A geometric screen, not a field solver: every pair of parallel track runs (within 20°,
< 4 mm apart, ≥ 0.5 mm overlap) between an *aggressor* net (PA_OUT / SPK / ZOB 9.8 Vrms,
AC1/AC2 24 Vrms, VRAW, +33V5 ripple, TANK_IN 3 Vrms) and a *sensitive* net gets a mutual
capacitance (Howard-Johnson coupled-microstrip estimate over the 1.5 mm ground pour), and
the coupled voltage is `V_aggr · |Z_victim| · 2πf · C_m` against an assumed signal level.
Loop gain = forward gain (node → PA_OUT) + coupling.

Worst pairs on the routing *before* the clearance rules:

| Board | Aggressor → victim | C_m | Coupled vs signal | Loop gain |
|---|---|---:|---:|---:|
| THT | `TANK_IN` → `TANK_OUT` (11 mm parallel run) | 0.30 pF | **−37 dB** | — |
| THT | `TANK_IN` → `QRG` / `WET` | 0.13 / 0.32 pF | −44 / −46 dB | — |
| THT | `PA_OUT` → `PA_INV` | 0.42 pF | −70 dB | −97 dB |
| SMD | `PA_OUT` → `TANK_OUT` (0.25 mm apart!) | 0.09 pF | **−37 dB** | **−44 dB** |
| SMD | `TANK_IN` → `TONE_OUT` (14 mm) | 0.46 pF | −53 dB | — |
| both | AC1 / AC2 / +33V5 → anything | — | < −100 dB | — |

Nothing oscillates (worst loop −44 dB), but the reverb *drive* running beside the reverb
*return* at −37 dB adds an un-reverbed leak to the wet signal, and the power-amp output
0.25 mm from the recovery-JFET gate is not how a hand layout would look. Two rules now
carry this into every routing (`kicad/cambridge_reverb.kicad_dru`, and the same numbers
as per-class clearances in the DSN the router sees): **HighCurrent tracks/vias ≥ 0.6 mm
from signal copper**, **tank-drive tracks ≥ 1.2 mm from the return path** (1.0 / 2.0 mm
were tried first: the router then left 14–27 links open, because a class clearance also
binds the traces entering pads that sit 0.8 mm from a neighbour; the 155 × 90 SMD board
takes 0.4 / 0.8 mm). After re-routing: THT worst pair `TANK_IN` → `TANK_OUT` **−50 dB**
(was −37), `PA_OUT` → `PA_BIAS` −66 dB with loop gain −59 dB; SMD `TANK_IN` → `TANK_OUT`
−42 dB (the two nets share adjacent pads on the tank connector), `PA_OUT` → `TANK_OUT` no
longer in the table, worst loop −68 dB. Full tables: `kicad/reports/crosstalk-{tht,smd}.md`,
routing consequences in `kicad/PCB-NOTES.md`.

## 5. Thermal — `spice/tran_thermal_lm1875.cir`

Electro-thermal RC ladder: junction —2 K/W— case —1.6 K/W (greased mica) or 1.0 (bolted
to a grounded sink; the tab is at V− = GND on a single supply)— heatsink (m·0.9 J/K) —
Rth_SA— ambient. Dissipation on the 33.5 V rail into 8 Ω (class B + 2.3 W quiescent):
idle 2.3 W, **worst-case sine 9.4 W** (at 7 W out, V_pk = V_cc/π), 12 W clip point 8.8 W,
loud music ~4 W average.

Steady-state junction temperature, greased mica (Tj limit 150 °C, shutdown ~170 °C):

| Rth_SA (K/W) | idle, Ta 25/40/55 | **worst-case sine**, Ta 25/40/55 | music, Ta 25/40/55 |
|---:|---|---|---|
| 1.5 | 37 / 52 / 67 | 73 / 88 / 103 | 45 / 60 / 75 |
| **2.5** (Part 5 spec) | 39 / 54 / 69 | **82 / 97 / 112** | 49 / 64 / 79 |
| 4 | 42 / 57 / 72 | 96 / 111 / 126 | 55 / 70 / 85 |
| 6 | 47 / 62 / 77 | 115 / 130 / **145** | 63 / 78 / 93 |
| 8 | 52 / 67 / 82 | 134 / **149** / 164 | 71 / 86 / 101 |
| 10 | 56 / 71 / 86 | **153** / 168 / 183 | 79 / 94 / 109 |

So: the **≤ 2.5 K/W** sink Part 5 asks for keeps the junction under 115 °C even in a
55 °C combo cabinet with a continuous sine — comfortable. A 4 K/W sink is fine to 55 °C
ambient; 6 K/W survives a sine test only in a cool room; 8–10 K/W (a small clip-on) is a
music-only sink that *will* hit thermal shutdown on a long sustained note at high volume.
Bolting the tab straight to a grounded sink saves ~6 K at full dissipation. Time to
saturate: a 40 g sink at 4 K/W has τ ≈ 145 s — the heatsink reaches steady state in
about five minutes, and the transient run (60 s worst-case sine / 60 s music, from cold)
peaks at 113 °C, so a set of loud songs is equivalent to the steady-state sine column for
sizing purposes. The junction itself follows in under a second (τ_jc ≈ 0.7 s).

Other dissipators: **LM317** (32 V → 17 V) with the new IC3 and the redesigned LED driver
carries ~25 mA average, ≤ 32 mA at the tremolo peak → 0.4–0.5 W → +25 K on a bare TO-220
(Rth_JA ~50 K/W free-standing): no heatsink needed, as Part 5 says, but bolt it to the
chassis if the amp lives in a hot cabinet. **KBP410G bridge** at 12 W out: I_dc ≈ 0.64 A,
2 × 0.94 V → 1.2 W, +20–30 K on its leads: fine (rated 4 A). **Transformer**: 33.5 V ×
0.64 A ≈ 21 W DC into the amp at full sine drive → ~35 VA continuous for a capacitor-input
bridge; a **25 VA** unit (AnTek AS-0524) is adequate for music (average draw ≈ ¼ of peak)
and will sag a few volts on a sustained full-power sine — acceptable for a 12 W combo,
but do not size smaller. **MRB toroid** (1 H, 600 Hz at ~0.5 V): 0.13 mA of signal current
— core saturation is not a concern.

## 6. What changed in the design because of this part
- errata #21: `C_adj` 10 µF, `R_pre` 100 Ω + `C_pre` 220 µF (`+17V_PRE`), `C_bref` 100 µF +
  `R_bias3` 22 k.
- errata #22: tremolo LED limiter + `Q_trem` driver; `LED_rate` becomes one limiter LED.
- Routing: `.kicad_dru` clearance rules + DSN class clearances (crosstalk).
- Fab: JLCPCB design-rule limits in both projects, fiducials on the SMD board, wide
  TO-92 and 1.5 mm LM1875 pads for the annular-ring minimum, 1206-only SMD capacitors and
  E24 gyrator values for the basic-parts library (Part 4 update).

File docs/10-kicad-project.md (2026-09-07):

# Vox Cambridge Reverb — Part 10: KiCad Project Files

> Reconstructed document — see `PROVENANCE.md`. The original `.kicad_pro`,
> `.kicad_sch`, and custom libraries were generated as a downloadable zip that
> was not retained. This document records their documented structure so the
> project can be rebuilt; the netlist notes in `../kicad/` carry the recovered
> per-sheet connection detail.
>
> **Update (2026-06-14):** the project file, custom libraries, **and the eight
> hierarchical `.kicad_sch` sheets + root now exist** in `../kicad/`.
> `cambridge_reverb.kicad_pro` carries the corrected three net classes;
> `symbols/cambridge_reverb.kicad_sym` + `symbols/cr_primitives.kicad_sym` hold
> the symbols; `footprints/cambridge_reverb.pretty/` the footprints; and
> `gen/gen_kicad.py` generates the wired schematic. Verified with kicad-cli:
> the hierarchy netlists with **146 components + 28 test points and 0 unconnected
> pins** (94 at first generation; 102 after the VBIAS mid-rail + footswitch-pulldown
> additions; 138 with the errata #19 tremolo and #20 Bass/Treble/mid-cut tone stack; 146 after errata #21-#22). See
> `../kicad/SCHEMATIC-BUILD.md` for connectivity method, the verified results,
> and the known simplifications (op-amp single-supply biasing, TBD tone stack).

## Project structure (as documented)
- `.kicad_pro` — JLCPCB-compatible design rules; **three** net classes (Default
  signals, Power 1.5 mm rails, HighCurrent 2.5 mm speaker/PA — the third added in
  the consistency pass, errata #11); hierarchical sheet structure for 8 blocks.
- `.kicad_sch` — 8 hierarchical sheets following signal flow:
  Power Supply → Preamp → Tone Stack → Reverb → Tremolo → MRB → Power Amp → Switching.
- Custom symbol library: VTL5C1 optocoupler (4-pin), Accutronics reverb tank
  (4-pin), 6-pin DIN footswitch connector.
- Custom footprint library: VTL5C1 (4-pin inline), TO-220-5 wide-pad for the
  LM1875 (`TO-220-5_Vertical_P1.70mm_LM1875`), KBP bridge (`Bridge_KBP_P3.81mm`),
  labelled test point (`TestPoint_THT_D2.0mm_Label`), wire pads (`WirePad_*`),
  plus, for the mixed-SMD variant in `kicad/smd/`, stock 0805/1206/1210/SMA/SOD-123/SOT-23,
  MRB 1H toroid (2-pad, 25 mm
  spacing), 35-pad wiring edge array (3 mm pads, 1.5 mm drill, silkscreen-labeled).

## Rebuilding
Recreate the project in KiCad using Part 2 (schematic values), Part 4 (design
rules/Gerber export), and the netlist notes in `../kicad/netlist-notes.txt`
(recovered per-sheet connections for the power amp, reverb, tremolo, and MRB).

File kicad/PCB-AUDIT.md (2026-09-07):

# PCB layout audit

Audit of `cambridge_reverb.kicad_pcb` (and the `power_section_demo`), done with
KiCad 8.0.9 (`kicad-cli pcb drc`, `pcbnew` geometry queries). First pass
2026-06-15 on the auto-grid starter board; **re-audited 2026-09-06** after the
footprint fixes, the floor-plan placement and the Freerouting pass. Status and
DRC numbers live in `PCB-NOTES.md`; this file is the category-by-category
layout review.

## Verdict (2026-09-06)
Electrically faithful (netlist matches the ERC-clean schematic) and now
**structurally clean before routing: 0 DRC errors, 0 warnings** on the placed
board (was 9 real errors + ~155 silk warnings on the grid-placed board). The two
real footprint defects from the first audit are fixed with datasheet-derived
project footprints, the bulk parts carry their real can/body sizes, and
placement follows the Part 5 floor plan. What remains is engineering judgement
on the *autorouted* copper (see `PCB-NOTES.md`), not layout hygiene.

## 1. Footprints
All components carry a hand-solderable footprint; pad numbers match the symbol
pins — **re-verified against the datasheets 2026-09-06 after finding the JFET
symbol had Gate/Source on the wrong pin numbers (errata #18; both boards fixed)**.
The table is the THT profile; the mixed-SMD variant (`smd/`) swaps the small R /
C / D / JFET rows for 0805 / 1206 / 1210 / SMA / SOD-123 / SOT-23 and keeps the rest.

| Class | Footprint | Verdict |
|---|---|---|
| R (¼ W) | `R_Axial_DIN0207…P5.08mm_Vertical` | ✅ compact vertical |
| JFETs, Q_trem (TO-92) | `TO-92_Inline_Wide` (2.54 mm pitch, 1.5 mm pads / 0.8 mm holes) | ✅ 0.35 mm annular ring; the stock `TO-92_Inline` (1.05 mm pads) had 0.15 mm — under JLCPCB's 0.18 mm minimum (errata #23); the wide pitch also matches the SOT-23→TO-92 adapters |
| LM1875 (TO-220-5, 1.7 mm pitch) | project footprint, pads **1.5 × 2.6 mm** on 1.1 mm holes | ⚠️ 0.20 mm ring: meets JLC's 0.18 absolute minimum, not the 0.25 recommendation (impossible at this pitch without a 1.0 mm drill the 0.97 mm lead diagonal would not survive) |
| R (1 W: `R_27V`) | `R_Axial_DIN0414_L11.9mm…P15.24mm` | ✅ **sized by value** (`gen_kicad.footprint_for`) |
| R (5 W: `R_bleed`) | `R_Axial_Power_L20.0mm_W6.4mm_P25.40mm` | ✅ sized by value |
| `R_spk_rtn` 0 Ω | `R_Axial_DIN0414…` (1 W-size link) | ✅ carries the full speaker current — fat pads, not a ¼ W jumper |
| C (film/disc) | `C_Disc_D7.5…P5.00mm` | ✅ generic |
| CP ≤ 22 µF / 47 µF | `CP_Radial_D5.0mm_P2.00mm` / `D6.3mm_P2.50mm` | ✅ sized by value; tantalums `C_reg_in`/`C_reg_out1` on 2.5 mm spacing |
| CP 1000 µF / 2200 µF / 4700 µF | `CP_Radial_D12.5_P5.00` / `D16.0_P7.50` / `D18.0_P7.50` | ✅ **real can sizes** (Panasonic FC per BOM) — the old board had every can as D8 |
| D / LED | `D_DO-41…` / `LED_D3.0mm` | ✅ |
| JFET | `TO-92_Inline` (THT) / `SOT-23` (smd) | ✅ pads 1 D / 2 S / 3 G per onsemi 2N5457 + MMBF5457 (errata #18) |
| TL072 | `DIP-8_W7.62mm` | ✅ (socket in the real build) |
| LM317 | `TO-220-3_Vertical` | ✅ |
| **LM1875** | **`cambridge_reverb:TO-220-5_Vertical_P1.70mm_LM1875`** | ✅ **FIXED.** TI NDH0005D inline TO-220-5 (1.70 mm pitch, 0.89 × 0.38 mm leads). 1.1 mm drill (as stock) with **1.45 mm pads → 0.175 mm annular** (rule 0.15, JLCPCB 0.13); pad-local clearance 0.2 mm so the 0.25 mm pad gap passes next to the 0.3 mm HighCurrent clearance. Stock footprint gave 0.0875 mm → 5 DRC errors. |
| Fuse | `Fuseholder_Clip-5x20mm…` | ✅ |
| **Bridge** | **`cambridge_reverb:Bridge_KBP_P3.81mm`** | ✅ **FIXED.** Real KBP outline from Diodes DS39310 (KBP404G–KBP410G): 3.81 mm pitch, 1.2 mm drill / 2.0 mm pads, body 14.5 × 3.5 mm, pins **+ ~ ~ −**. Schematic bridge symbol renumbered to match. Was a `PinHeader_1x04` placeholder. |
| Pots ×5 / jacks / DIN / tank | **`WirePad_1x0N_P2.54mm_D1.2mm`** | ✅ Part 4 signal wire pads (2.0 mm / 1.2 mm drill) on the wiring edge; were 2.54 mm pin headers |
| Speaker / transformer | **`WirePad_1x0N_P5.08mm_D1.5mm`** | ✅ Part 4 power wire pads (3.0 mm / 1.5 mm drill) |
| Mounting | 4 × `MountingHole_3.2mm_M3` (NPTH, unique refs H1–H4) | ✅ new; 0.5 mm pour clearance |
| Test points ×26 | **`cambridge_reverb:TestPoint_THT_D2.0mm_Label`** | ✅ 2.0 mm pad / 1.0 mm drill; silk label = the footprint value (net alias) |

## 2. Placement — Part 5 floor plan, generated
`gen_pcb.py` now places into the five documented **zones, left → right**:

```
INPUT/PREAMP | TONE | REVERB/TREMOLO (+MRB) | POWER AMP | POWER SUPPLY
o o o  wiring edge: jacks · pots · tank/pots/DIN · speaker · transformer  o o o
```
- Zone widths are balanced automatically so every column packs to about the
  same height; inside a zone the parts keep their **sheet (signal-chain) order**,
  sorted tallest-first within a sheet so the rows ("shelves") pack tightly with a
  1.3 mm courtyard gap and 4 mm channels between zones.
- **Heat-sinking devices on the top edge**, tab outward, with the Part 5 **10 mm
  keep-out** below them: `IC_PA` (LM1875) above the power-amp zone, `U1` (LM317)
  above the PSU zone — both reachable by a chassis bracket.
- **All off-board wiring on the bottom edge** under its own zone (Part 5: board
  flips up for service); `T1` (transformer) pinned to the far right, so the
  nearest signal zone is a full PSU-zone width away (Part 5: "no signal traces
  within 15 mm of transformer pads").
- **Test-point strip** across the top of each zone: 26 labelled `TP_*` pads
  (footprint `TestPoint_THT_D2.0mm_Label`, value = net alias on silk), one GND
  per zone — the bring-up nodes of Parts 3/5. Table in `PCB-NOTES.md`.
- Reference/value text is hidden (silk clutter); showing refs is a GUI pass.
- Not encoded: "no traces under LFO timing components" — an autorouter cannot
  honour it; check the tremolo area by eye.

## 2b. The SMD variant's placement
Same generator, `--profile smd`: 155 × 90 mm, 6 mm margin, 0.4 mm part gap (0.6
before the errata #20 tone parts), 3 mm channels, pad row kept clear of the corner
holes; the three input-jack pad groups run down the left edge because the bottom
edge is ~9 mm short for 13 connector groups (PCB-NOTES). All four columns fit under
the wiring-edge limit; pre-route DRC 0 errors / 0 warnings beyond the stub warnings.

## 3. Board outline & chassis fit — figure corrected ⚠️
- Outline: **190 × 115 mm**, matching the original 25-5274-2 (errata #9).
- **The earlier density numbers were inflated.** The old `gen_pcb.py` summed
  `GetBoundingBox()` *including the hidden reference/value text boxes*, which
  roughly doubles a resistor's footprint. Text-less bounding boxes give:

| Board | Usable area | Parts area | Packing |
|---|---:|---:|---:|
| 190 × 115 mm (original) | 16 150 mm² | ~5 290 mm² | **~33 %** (was reported 48–53 %) |
| 155 × 90 mm (Part 7 "safe-bet") | 9 450 mm² | ~5 290 mm² | **~56 %** (was reported 82–90 %) |

  So the 155 × 90 board is **no longer "not buildable"** — 60 % (with the test
  points) is dense for THT, and the **mixed-SMD variant actually fits it** at 48 %
  (`smd/cambridge_reverb_smd.kicad_pcb`). Errata #9 still stands: **measure the
  chassis first**, then pick the profile / set `BW, BH` in `gen_pcb.py` and
  regenerate (the placer rebalances the columns).

## 4. Net classes & design rules
- Three classes: **Default 0.5 mm / Power 1.5 mm / HighCurrent 2.5 mm**, with
  0.2 / 0.3 / 0.3 mm clearances; patterns target `+33V5`, `SPK_P`, `SPK_N`,
  `PA_OUT` (HighCurrent) and `VREG_IN`, `+17V`, `GND` (Power). Verified to match
  real nets, and **verified to survive the DSN export** (`route_board.py`), so
  the autorouter uses these widths.
- Rules (from Part 4) are conservative and JLCPCB-safe; the one exception (the
  LM1875 annular ring, §1) is resolved.

## 5. Copper, GND pour, layers
- 2-layer. **Bottom = GND pour** connecting all GND pads; refilled after routing.
- Mounting holes keep 0.5 mm of pour clearance; no isolated-copper items.
- Star-ground / stitching (Part 3/4) remain hand decisions on top of the pour.

## 6. Routing
- Done headlessly with **Freerouting** (`gen/route_board.py`), both in a two-layer
  mode and a **top-only** mode (bottom declared a plane so signals stay on F.Cu,
  the Part 4 intent). Results, unrouted counts and the DRC after import are in
  **`PCB-NOTES.md`**.
- An autorouter does not know audio: expect to tidy by hand the input/JFET-gate
  runs, the LFO area, the speaker/`+33V5` loop and the ground return before fab.

## Prioritized actions for a fab-ready board
1. **Measure the chassis** and lock the outline (errata #9) — regenerate.
2. Review the routed copper (§6) and hand-fix what an autorouter gets wrong.
3. Show reference designators on silk; DRC to zero again.
4. Gerbers per `docs/04-jlcpcb-fabrication.md` + `production/CHECKLIST.md`.

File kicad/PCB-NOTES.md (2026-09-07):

# PCB — generated placement + headless autoroute

`cambridge_reverb.kicad_pcb` is built by two scripts (KiCad 8 `pcbnew` API):

1. **`gen/gen_pcb.py` — placement.** Every footprint from the schematic
   (`gen_kicad.py`'s component list) is placed into the **Part 5 floor plan**:
   columns left → right `INPUT/PREAMP (+TONE below it) | TREMOLO/MRB (+REVERB
   below it, next to its tank pads) | POWER AMP | POWER SUPPLY`, signal-chain
   order inside each zone (ICs and cans tallest-first, small parts in schematic
   order, short parts **stacked** beside tall ones so a can or DIP does not waste
   the row height under every resistor), column widths auto-balanced to equal
   height and repaired until no column overflows, a **labelled test-point strip**
   at the top of every zone (see *Test points*). `IC_PA` (LM1875) and `U1` (LM317)
   sit on the **top edge**, tab outward, with the Part 5 **10 mm keep-out**; all
   off-board wiring lands on **Part 4 wire pads along the bottom edge** (2.0 mm
   signal pads, 3.0 mm speaker/transformer pads), `T1` at the far right. 4 × M3
   mounting holes, 190 × 115 mm `Edge.Cuts`, bottom **GND pour**, **keepout rule
   areas** (2 mm edge frame + squares round the holes, tracks/vias only) so the
   router respects the fab's edge clearance, and two **locked escape stubs** off the
   LM1875's pins 4/5 (see below). Design rules in the `.kicad_pro` are **JLCPCB's
   2-layer limits** (Part 4) and `cambridge_reverb.kicad_dru` adds two crosstalk
   rules (below). **DRC before routing: 0 errors, 0 warnings** apart from the two
   dangling stubs.
2. **`gen/route_board.py` — routing.** Exports a Specctra DSN (the project's three
   net classes come through: 0.5 / 1.5 / 2.5 mm), injects Freerouting's
   `autoroute_settings` (bottom layer 6× trace cost so it is used only for short
   jumpers and the GND pour stays whole; via cost 80), runs **Freerouting 1.9.0**
   under `xvfb-run`, imports the SES and refills the pour.

Regenerate: `python3 kicad/gen/gen_pcb.py && python3 kicad/gen/route_board.py`
(needs Java + `kicad/gen/freerouting.jar` = freerouting-1.9.0.jar, git-ignored;
`apt install xvfb`). **Verify:** `kicad/gen/check.sh tht --no-regen` (or `smd`)
runs ERC + DRC and writes the reports to **`kicad/reports/`** — the committed
`*-erc.rpt` / `*-drc.json` files there are the evidence for every number in this
file. Without `--no-regen` the script regenerates first (which discards routing).

## Routing result — THT board (`kicad-cli 8.0.9 pcb drc`, this commit; `kicad/reports/tht-drc.json`)
| Item | Result |
|---|---:|
| Connections (ratsnest, incl. 28 test points, the dual-gang speed pot, the errata #20 tone stack and the #21/#22 parts) | 222 |
| **Routed** | **215 / 222** (`unconnected_items`: 7) |
| DRC violations (`--severity-all`, JLCPCB limits + `.kicad_dru` crosstalk rules) | **1 error** — `starved_thermal` on the GND pad of `C_rec_byp`; 0 warnings; **0 rule hits** |
| Track segments | 1 421 — **F.Cu 5 645 mm**, B.Cu 902 mm (short jumpers) |
| Vias | 86 |
| Router settings | Freerouting 1.9.0, `-mp 150`, B.Cu trace cost ×7, via cost 60, class clearances HighCurrent 0.6 mm / TankDrive 1.2 mm (`route_board.py --bottom-cost 7 --via-cost 60`) |

The seven open connections: two pieces of **`+33V5`** at the power amp (`C_byp2` ↔ a
bottom jumper at ≈ (113, 62), and a 40 mm top run ending at ≈ (137, 68) — the 2.5 mm
Power trace could not thread the 0.6 mm rule past the PA parts; join at full width),
`JWT` (`R_j4` → the treble-pot pad on the wiring edge), `LFO_OUT` (two trace ends in the
tremolo zone), `R_DRVO` and `TKDRV` (the tank-drive path `C_rev1` / `R_drv3`, held apart
by the 1.2 mm TankDrive rule; 3–10 mm links) and `TREM_S` (`VTL1` LDR → `C_dc_blk`).
Eight GUI touches; listed so nobody trusts the copper blindly.

Honest note: the previous placement (before errata #21/#22) routed to 208/212, DRC clean,
without the crosstalk rules. This placement carries eight more parts and the two
clearance rules; fourteen settings were tried (6–16 open): ×8 / 60 → 6 open but 3 starved
thermals, **×7 / 60 → 7 open + 1 thermal (committed)**, ×6 / 80 → 13, ×7 / 80 → 12,
×8 / 80 → 10, ×9 / 60 → 10; with a 1.0 / 2.0 mm rule set every run left 14; with only
the HighCurrent rule 10–13; with TankDrive at 0.8 mm 8–16. **Evaluate candidates in
place** (next to the `.kicad_pro` / `.kicad_dru`): `kicad-cli pcb drc` on a copy in
another directory silently runs without the net classes and the rules and under-counts
(that cost an hour here). Freerouting is deterministic for identical input but
sensitive to small placement changes — always re-check `kicad/reports/` after
regenerating.

## Mixed SMD / THT variant — `smd/cambridge_reverb_smd.kicad_pcb` (155 × 90 mm)
Same schematic, second footprint profile (`--profile smd` on all three scripts),
sized for the **Part 7 155 × 90 "safe-bet" chassis**. What moves to SMD and what
deliberately does not:

| SMD (90 parts) | Stays THT (and why) |
|---|---|
| 53 × R → **0805** (thin-film for the 1 M gate/input resistors); `R_reg2` → 1206 (85 mW) | LM1875, LM317, KBP bridge, 5 W / 1 W resistors, `R_zobel`, the 0 Ω speaker link — power |
| ≤ 100 nF → **1206** (C0G/NP0 in the signal path, 100 V X7R snubbers) | **all electrolytics** — a radial can standing up uses *less* board than an SMD can |
| 120 nF MRB, 1 µF coupling, `C_zobel` → **1210** (X7R 50/100 V; PPS film on a 2220 pad if you prefer) | TL072 × 2 in **DIP-8 sockets**, the tone TL074 in a **DIP-14 socket** (availability audit: swappable) |
| 1N4007 → **SMA** (S1M); 1N4148 → **SOD-123** (1N4148W) | `R_s1`, `R_s2`, `R_rec2` — bench-trimmed per JFET (errata #15), swap an axial not an 0805 |
| MMBF5457 → **SOT-23** fitted directly (1 D / 2 S / 3 G, errata #18) — no TO-92 adapter | LED, vactrol, toroid, fuse clip, wire pads, test points |

Placement rules for this profile: 6 mm margin (corner M3 holes stay), 0.4 mm part
gap (0.9 mm body-to-body once the courtyards are counted), 3 mm channels;
otherwise the same floor plan, test-point strips and escape stubs. The wiring edge
differs in one point: with the Bass/Treble pots and the MID CUT toggle (errata #20)
the 13 connector groups need ~146 mm and the 155 mm board has 137 mm between the
corner holes, so the **three input-jack pad groups run down the left edge**
(rotated, in the margin next to the preamp — the shortest input wiring); everything
else stays on the bottom edge, `T1` far right. Two more deliberate differences:
- **GND pour on both layers.** SMD ground pads have no through-hole to the bottom
  pour, so the top gets a pour too — connected *solid* to the SMD ground pads only
  (THT pads ground through the bottom pour, no top thermal spokes). The router is
  shown only the bottom plane (`route_board.py` drops the F.Cu plane from the DSN),
  so it drops a via from every SMD ground pad: real copper connectivity, and the
  top pour is extra ground copper on refill. (With both planes visible the router
  treated every SMD ground pad as "done" and 20 of them ended on pour islands.)
- **Net-class widths 2.0 / 1.0 mm** (HighCurrent / Power, 0.25 mm clearance) in
  `smd/cambridge_reverb_smd.kicad_pro`, vs 2.5 / 1.5 on the THT board. Part 4's
  widths were sized for the 190×115 board; at ~1.7 A peak and under 1 A RMS, 1 oz
  copper needs well under 1 mm, and 2.5 mm traces cannot pass between 0805/1206
  pads on a 155×90 board (errata #11 addendum). Parts area **~5 090 mm² → 54 % of the 155 × 90 usable area**
(the THT-profile parts would be 68 %). **Pre-route DRC: 0 errors, 0 warnings** beyond the two stub warnings.

**Routing result (this commit; `kicad/reports/smd-drc.json`)** — `route_board.py --in kicad/smd/cambridge_reverb_smd.kicad_pcb --bottom-cost 6 --via-cost 80` (class clearances HighCurrent 0.4 mm / TankDrive 0.8 mm, the board's `.kicad_dru` numbers):

| Item | Result |
|---|---:|
| Connections (incl. 28 test points, the dual-gang speed pot, tone stack, #21/#22 parts; SMD ground pads count via the top pour) | 223 |
| **Routed** | **210 / 223** |
| DRC (`--severity-all`, JLC limits + rules) | **4 errors** — `starved_thermal` on the GND pads of `IC3` pin 11, `C_s2`, `R_spk_rtn`, `C_rec_byp`; 0 warnings; **0 rule hits** |
| Track segments | 1 154 — F.Cu 3 740 mm, B.Cu 1 124 mm |
| Vias | 120 (most are SMD-ground-pad drops to the bottom pour) |

The thirteen open items: four GND pour fragments (`C_s1`, `C_bref`, `IC1` pin 4 and a
top-pour island — stitching vias), `+33V5` ×2 and `+17V` ×1 (short rail links at the power
amp / tremolo bias, 3–6 mm), `AC1` / `AC2` (the snubber caps `C102` / `C103` to the
transformer pads, 10 mm), `LFO_OUT` (IC2 pin 1 to its trace, 27 mm along the top),
`Q2D` and `Q2G` (two 2 mm gaps in the preamp) and `TKDRV` (tank drive, 14 mm). All are
GUI touches; with the four thermals that is seventeen — the price of the crosstalk rules
on a 56 %-full board.

Sweep on this placement (150 passes; every candidate DRC'd *in place* with the rules):
plain routing (no class clearances) ×7 / 100 → **9 open but 47 rule violations** (32
HighCurrent, 15 TankDrive); 0.4 / 0.8 mm: ×7 / 100 → 13 open + 3 clearance + 3 mask
errors, **×6 / 80 → 13 open, 4 thermals, rules clean (committed)**; 0.35 / 0.6 mm →
12–14 open with 12–14 rule hits; HighCurrent-only 0.4 → 13 open, 8–11 TankDrive hits;
0.6 / 1.2 mm → 13–27 open. The placement before errata #21/#22 routed to 7 open without
rules; the SMD board sits at the router's limit at 155 × 90 (56 % parts by area), so
expect to finish a dozen links by hand after any regeneration — or drop the two rules
in `smd/cambridge_reverb_smd.kicad_dru` and take the 9-open plain routing knowingly.

**Assembly path:** JLCPCB places the SMD side (all are basic-class part sizes),
you hand-solder the ~76 THT parts. `production/smd/bom-jlcpcb.csv` (Comment /
Designator / Footprint / LCSC — LCSC left for the parts picker, nothing invented)
and `production/smd/cambridge_reverb_smd-top-pos.csv` (kicad-cli position file)
are the two inputs. Regenerate:
`python3 kicad/gen/gen_kicad.py --profile smd && python3 kicad/gen/gen_pcb.py --profile smd && python3 kicad/gen/gen_bom.py --profile smd --jlc && python3 kicad/gen/route_board.py --in kicad/smd/cambridge_reverb_smd.kicad_pcb`.

## Test points (bench bring-up, Part 5 order)
26 labelled test points (`TP_*` in the schematic/BOM; footprint
`TestPoint_THT_D2.0mm_Label`: 2.0 mm pad / 1.0 mm drill — fit a header pin or a
bare 0.6 mm wire loop so a scope hook grabs it). They sit in a **strip across the
top of each zone**, the silkscreen prints the alias, and every zone has a **GND**
pin for the probe clip. Expected values are from Part 3's troubleshooting table,
Part 2's set-up notes and the ngspice suite (`spice/README.md`).

| Silk | Ref | Net | Zone | Expect (DC unless noted) | Source |
|---|-----|-----|---|---|---|
| `VRAW` | TP_VRAW | VRAW | PSU | ~33–35 V unloaded, bridge output *before* F1 (fuse check: VRAW ≠ +33V5 → F1 open) | Part 2 |
| `+33V5` | TP_33V5 | +33V5 | PSU | ~33.5 V | Part 3 |
| `VREG` | TP_VREG_IN | VREG_IN | PSU | ~31–33 V (LM317 input after the 100 Ω/1000 µF pre-filter) | Part 3 |
| `+17V` | TP_17V | +17V | PSU | 17.0–17.5 V (R_reg2 = 3.09 k; 16.9 V with 3.0 k) | Part 3, errata #10 |
| `GND` | TP_GND_PSU | GND | PSU | probe ground | — |
| `Q1D` | TP_Q1D | Q1D | Preamp | **8–9 V** target; ~12 V with the recovered Rs = 2.2 k → trim R_s1 (≈1–1.2 k) per device | errata #15, spice |
| `Q2D` | TP_Q2D | Q2D | Preamp | 8–9 V target (same trim, R_s2) | errata #15 |
| `PRE` | TP_PRE_OUT | PREAMP_OUT | Preamp | AC: amplified guitar signal (preamp gain ≈ 22 dB/stage in sim) | spice |
| `GND` | TP_GND_PRE | GND | Preamp | probe ground | — |
| `VB_3` | TP_VBIAS_3 | VBIAS_3 | Tone | ~8.5 V (mid-rail reference for IC3; every IC3 output sits here too) | spice (ac_tonestack) |
| `TMK` | TP_MK_OUT | MK_OUT | Tone | ~8.5 V DC + AC: the Bass/Treble network after the ×2 make-up, before the MID CUT — flat with the pots at noon; toggle SW_MID and 800 Hz drops ~10 dB at `TONE` but not here | spice (sweep_tonestack) |
| `TONE` | TP_TONE_OUT | TONE_OUT | Tone | 0 V DC (after C_tout); AC: volume-pot wiper, the internal FX-send tap (via R_fx_pad) | Part 1 §7, errata #20 |
| `VB_R` | TP_VBIAS_R | VBIAS_R | Reverb | ~8.5 V (mid-rail reference for IC1) | spice |
| `TK_IN` | TP_TANK_IN | TANK_IN | Reverb | AC: tank drive, ≈ 11× the driver input; no DC (after C_rev1) | spice |
| `TK_OUT` | TP_TANK_OUT | TANK_OUT | Reverb | AC: tank return, a few mV–tens of mV; silence → tank/cable | Part 9 |
| `QRD` | TP_QRD | QRD | Reverb | 8–9 V target (recovery JFET drain; trim R_rec2 like R_s1) | errata #15 |
| `BLEND` | TP_BLEND | BLEND | Reverb | ~8.5 V DC (summer output about VBIAS_R) + dry/wet mix AC, unity | spice (tran_reverb_mixer) |
| `GND` | TP_GND_REV | GND | Reverb | probe ground | — |
| `VB_T` | TP_VBIAS_T | VBIAS_T | Tremolo | ~8.5 V (mid-rail reference for IC2) | spice |
| `LFO` | TP_LFO | LFO_OUT | Tremolo | AC: the LFO — **10.6 Hz** with the speed pot at min, **0.60 Hz** at max, ~0.48 V amplitude (0.96 Vpp), sine-ish | spice (tran_tremolo_lfo, sweep_lfo_speed) |
| `TREM` | TP_TREM_OUT | TREM_OUT | Tremolo | AC: post-LDR signal, amplitude pumping at the LFO rate when tremolo is on | Part 1 §5 |
| `PA_IN` | TP_PA_IN | PA_IN | Tremolo | ~8.5 V DC (IC2-B buffer about VBIAS_T) + the full effects-chain signal | roast R3 |
| `GND` | TP_GND_TREM | GND | Tremolo | probe ground | — |
| `MRB` | TP_MRB_OUT | MRB_OUT | MRB | AC: mid-boosted signal, peak ~580–600 Hz | spice (ac_mrb) |
| `PA_B` | TP_PA_BIAS | PA_BIAS | Power amp | ~16.75 V (V+/2 from the 22 k/22 k divider) | Part 2 |
| `PA_OUT` | TP_PA_OUT | PA_OUT | Power amp | **~16–17 V** (LM1875 pin 4, V+/2) — wrong → IC bad or oscillating | Part 3 |
| `SPK` | TP_SPK | SPK_P | Power amp | ~0 V DC after C_out (any DC here → C_out); AC = speaker signal | errata #7 |
| `GND` | TP_GND_PA | GND | Power amp | probe ground | — |

Bring-up order (Part 5): rails (`VRAW`/`+33V5`/`VREG`/`+17V`) with the series
light bulb → `PA_B`/`PA_OUT`/`SPK` DC with no signal → JFET drains (`Q1D`,
`Q2D`, `QRD`) and trim → `VB_R`/`VB_T` → signal generator into IN1, follow
`PRE` → `TMK` → `TONE` → `BLEND` → `TREM` → `MRB` → `PA_IN` → `SPK`.

## Crosstalk screen and the two routing rules it produced (Part 6c §4)
`kicad/gen/crosstalk_audit.py` estimates the mutual capacitance of every parallel run
between an aggressor net (PA_OUT / SPK / ZOB at 9.8 Vrms, the 24 Vrms AC1/AC2, VRAW,
+33V5 ripple, TANK_IN at 3 Vrms) and a sensitive node, and turns it into "coupled level
vs signal" and a loop gain. On the first routing of the errata #20 boards the worst pairs
were `TANK_IN` → `TANK_OUT` (11 mm side by side, **−37 dB**, THT) and `PA_OUT` →
`TANK_OUT` (0.25 mm apart, −37 dB, loop gain −44 dB, SMD); nothing near oscillation,
but not a layout anyone would sign. So:

| Rule (`.kicad_dru`, tracks/vias only) | Clearance | Also given to the router as | Why |
|---|---:|---|---|
| `HighCurrent` (PA_OUT, SPK, +33V5, VRAW, AC1, AC2) ↔ `Default` copper | **0.6 mm** | class HighCurrent clearance 600 µm in the DSN | 9.8 Vrms / 24 Vrms aggressors beside 20 mV–1 V nodes; 1.0 mm was tried first and left 14 (THT) / 27 (SMD) links unroutable |
| `TankDrive` (R_DRVO, TKDRV, TANK_IN) ↔ TANK_OUT / QRG / WET / DRVP | **1.2 mm** | class TankDrive clearance 1200 µm | reverb drive leaking into the reverb return |

Pad geometry is exempt (the LM1875's 1.7 mm pin row, 0805 feedback parts, snubber
caps), which is why the numbers are carried as *rules* rather than net-class clearances.
On the SMD board the rules are 0.4 / 0.8 mm (`smd/cambridge_reverb_smd.kicad_dru`) —
more left the router short of links (see the SMD sweep above).

After re-routing (`kicad/reports/crosstalk-{tht,smd}.md`): THT worst pair `TANK_IN` →
`TANK_OUT` **−50 dB** (was −37), then `PA_OUT` → `PA_BIAS` −66 dB (loop −59 dB); SMD
`TANK_IN` → `TANK_OUT` −42 dB (was −37; the two nets share adjacent pads on the tank
connector, so a few mm of side-by-side copper is unavoidable), `PA_OUT` → `TANK_OUT`
gone from the table, worst loop −68 dB. A hand pass should still move the tank return
away from the drive at the connector — the audit will show whether it helped.

## What the autorouter does NOT know — review by hand before fab
- **Audio layout.** It routes by cost, not by ear: the JFET gate inputs
  (`GUITAR_IN`, `Q1G`/`Q2G`), the reverb recovery input (`TANK_OUT`) and the LFO
  timing nodes may run next to `+33V5`/`PA_OUT`. Move or reroute them; keep the
  tremolo `LFO_*` nets short (Part 5 keep-out: no traces under the LFO timing parts).
- **Grounding.** The bottom pour is one net; the Part 3 **star ground** (power-amp
  return, speaker return, preamp ground) is a hand decision — at minimum keep the
  `C_main`/`R_spk_rtn`/`C_out` returns together and away from the input jacks.
- **HighCurrent loop.** The 2.5 mm `+33V5` / `PA_OUT` / `SPK_P` traces are correct
  in width but the router may loop them around the power-amp column; tighten them.
- **Bottom-layer jumpers** cut the pour locally. Check every GND pad still has ≥ 2
  thermal spokes (the DRC `starved_thermal` check) after any edit.
- **Silkscreen:** reference designators are hidden (regenerate with
  `hide_text=False` in `gen_pcb.py` and tidy in the GUI).

## Why the LM1875 has pre-routed stubs
The TO-220-5 pins are on a **1.70 mm pitch**. With the 0.3 mm HighCurrent/Power
clearance, no trace wider than ~1.35 mm can enter pins 3, 4 or 5 past their
neighbours, so the 2.5 mm `PA_OUT` / `+33V5` traces are physically unroutable to
the pin — every autorouter run left exactly those two connections open. A hand
layout necks the trace down at the pin; `gen_pcb.py` does the same with two
**locked 0.9 mm stubs** (pin 4 straight down 3.5 mm, pin 5 fanned 4 mm right).
Locked tracks export as `(type fix)`, so the router keeps them and attaches the
full-width trace at their ends. 0.9 mm × 3.5 mm of 1 oz copper at ~1.7 A peak is
a non-issue thermally. Pin 3 (GND/V−) needs nothing: it is a through-hole pad in
the bottom pour.

## Freerouting notes (what actually worked)
- **v1.9.0** honours `-mp` (max passes) and always writes the `.ses` — unrouted
  connections stay as ratsnest. Needs an X display even in CLI mode → `xvfb-run`.
- **v2.1.0** in CLI mode ignores `-mp`, `router.max_passes` *and*
  `router.job_timeout`, and only writes output when nothing is unrouted; with one
  hard connection it rips up forever (>400 passes observed). Its multi-threaded
  router also crashed on this board. Not usable for a bounded run.
- **Route the board in place.** `pcbnew.LoadBoard` picks the net classes up from
  the `.kicad_pro` next to the board; a copy routed from another directory came
  back with every track at the 0.2 mm default (199 `track_width` + 201 `clearance`
  errors). `route_board.py` now refuses a board without its project file.
- The router only knows the board *outline*: KiCad's 0.5 mm copper-to-edge rule
  and the mounting holes' local clearance do not reach it, and on the SMD board it
  ran a trace 45 mm along the left edge and under H3. `gen_pcb.py` therefore adds
  **keepout rule areas** (tracks + vias, pours allowed): a 2 mm frame inside the
  edge and a 7.2 mm square round each M3 hole — they export as `(keepout …)`.
- The SES import can leave a few zero-length track segments (`track_dangling`
  warnings); `route_board.py` prunes them.
- The Specctra export refuses duplicate references (the mounting holes are H1–H4
  for that reason). KiCad exports the GND zone as a `(plane)`, so GND pads need no
  traces — but bottom-layer traces slice the pour, which is why the bottom layer
  is made expensive rather than free: a free two-layer run put 2.3–2.5 m of copper
  on the bottom and left 10–11 GND pads on islands.

## Chassis-fit reality check ⚠️ (corrected 2026-09-06)
The earlier 48–53 % / 82–90 % densities counted hidden text in the bounding
boxes. Text-less footprint areas:

| Board | Usable area | Parts area | Packing |
|---|---:|---:|---:|
| 190 × 115 mm (original 25-5274-2) | 16 150 mm² | ~6 450 mm² (THT parts) | **~40 %** |
| 155 × 90 mm (Part 7 "safe-bet") | 9 450 mm² | ~6 450 mm² (THT parts) / ~5 090 mm² (SMD profile) | **~68 %** / **~54 %** |

With the errata #19/#20 parts the THT board's columns use ~97 % of their height
at a 1.2 mm part gap (3.5 mm channels; the placer moves width between columns
until none overflows) — 190 × 115 is now the right size for the THT build, and
the 155 × 90 board only fits with the SMD profile. Errata #9 still applies —
**measure the chassis**, set `BW, BH` in `gen_pcb.py`, regenerate, re-route.

## Power-section routing demo — DRC clean
`power_section_demo.kicad_pcb` (also from `gen_pcb.py`) routes the +33V5 (2.5 mm)
and +17V (1.5 mm) rails by hand over a GND pour as a net-class width reference:
`kicad-cli pcb drc` → 0 violations, 2 ratsnest lines left on purpose (`VRAW`,
`VREG_IN` — the latter needs a via to cross the +17V trunk).

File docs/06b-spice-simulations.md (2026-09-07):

# Vox Cambridge Reverb — Part 6B: Guitar-Optimized SPICE Simulations

> Reconstructed document — see `PROVENANCE.md`. The LM1875 power-amp netlist is
> recovered substantially verbatim. The actual `.cir`/`.asc` source files live
> in `../spice/`. This supersedes the original Part 6.

## Guitar-optimization parameters (recovered verbatim from project)
- 100 pF presence rolloff cap at Q2 drain
- 1 nF feedback cap across LM1875 R_fb → 7.2 kHz bandwidth limit
- 470 pF treble cap for Vox chime character
- Guitar pickup model: 3 H / 6 kΩ / 100 pF, with 300 pF cable capacitance
- 10" speaker model: 105 Hz mechanical resonance + voice-coil inductance

## LM1875 power-amp simulation note
TI provides no official LTspice model for the LM1875, so it is modeled with
`UniversalOpamp2` with parameters matched to LM1875 specs (Aol ≈ 100k, GBW ≈
2.5 MHz, slew ≈ 18 V/µs, Rout ≈ 0.1 Ω), output clipped by the supply rails.
Supply: +33.5 V single rail, 8 Ω load. Closed-loop gain 23× (27 dB).

The full netlist is in `../spice/power_amp_lm1875.cir`. See that folder's README
for the list of the six circuit-block simulations.

## ngspice companion set + verified results (2026-06-14)
The original `.cir` is LTspice-flavored (`UniversalOpamp2`, `opamp.sub`). An
**ngspice-runnable** set was added so the design can be re-verified with an
open-source tool — `apt install ngspice`, then `cd ../spice && ./run_all.sh`.
Measured vs. documented:

| Block | Measured (ngspice-42) | Documented |
|---|---|---|
| Power-amp gain | 27.21 dB (23.0×) | 23× / 27.2 dB ✅ |
| Power-amp HF −3 dB | 6.83 kHz (with `C_fb_hf`) | ~7.2 kHz ✅ |
| Power-amp LF −3 dB | 17.2 Hz | "7.2 Hz" — see below ⚠️ |
| Reverb-driver gain | 20.83 dB (11.0×) | 11× ✅ |
| MRB peak | 577 Hz | ~610 Hz ✅ |
| Tremolo LFO | 10.6 Hz (pot 0) … 0.60 Hz (pot max), 1/(2πRC) with the errata #19 network | RC-set ✅ (swept) |
| Preamp drain | 12.1 V (Rs 2.2 k) | 8–9 V — see below ⚠️ |
| Tone stack (errata #20) | noon flat −0.2 dB; bass −7.5…+4.9 dB @ 100 Hz; treble −16.5…+5.6 dB @ 10 kHz; MID CUT −9.6 dB @ 796 Hz | James network + gyrator notch ✅ (swept) |

Two corrections fell out of running it: the power-amp LF corner is ~17 Hz (the
input pole adds to `C_gain`; fine for guitar), and the preamp wants Rs ≈ 1–1.2 kΩ
(not 2.2 kΩ) to hit the 8–9 V drain target. Both are in `errata.md` and
`../spice/README.md`.

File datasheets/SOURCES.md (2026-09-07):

# Datasheet sources — committed PDFs and what each one backs

The PDFs in this folder are the manufacturer documents the footprints, pinouts and
design numbers were taken from. They are **committed on purpose** (the previous
policy of not committing them was reversed 2026-09-07): a footprint or a pin
number is only as good as the drawing it came from, and errata #18 (JFET pins)
showed why the exact revision matters. Re-download from the source URL when
re-verifying before an order; the SHA-256 prefix identifies the revision used here.

| File | Part | Source | Revision | Used for | SHA-256 (16) |
|---|---|---|---|---|---|
| `LM1875_TI_SNAS524A.pdf` | LM1875T power amp | ti.com/lit/ds/symlink/lm1875.pdf | SNAS524A, May 2004 | TO-220-5 NDH0005D package drawing (1.70 mm pitch, 0.89×0.38 mm leads) → footprint `TO-220-5_Vertical_P1.70mm_LM1875`; pinout 1 IN+ 2 IN− 3 V− 4 OUT 5 V+ | `049a5385f4720ade` |
| `LM317_TI.pdf` | LM317T regulator | ti.com/lit/ds/symlink/lm317.pdf | SLVS044Z, rev. April 2025 | Vout = 1.25 (1 + R2/R1) (errata #10); TO-220 pinout ADJ/OUT/IN | `323ec64a58515090` |
| `TL072_TI.pdf` | TL072 dual op-amp | ti.com/lit/ds/symlink/tl072.pdf | SLOS080W, rev. July 2025 | DIP-8 pinout; supply range for the single-supply +17 V design; slew/GBW behind `opamp*.sub` | `40b14981bad45917` |
| `MMBF5457_onsemi_2023-01_Rev1.pdf` | MMBF5457 JFET (SOT-23) | onsemi.com/pdf/datasheet/mmbf5457-d.pdf | Rev. 1, January 2023 | **SOT-23 pinout 1 D / 2 S / 3 G** — the symbol renumbering of errata #18; SMD-variant footprint | `94751083a9322c4c` |
| `2N5457_onsemi_2010-02_Rev6.pdf` | 2N5457 JFET (TO-92, discontinued) | onsemi.com/pdf/datasheet/2n5457-d.pdf | Rev. 6, February 2010 | **TO-92 lead order 1 Drain / 2 Source / 3 Gate** (errata #18); Idss/Vp spread behind the errata #15 bias trim | `d547280c34509502` |
| `J111-J113_onsemi_2006-03_Rev2.pdf` | J111/J112/J113 JFET (TO-92 alternative) | onsemi.com/pdf/datasheet/j111-d.pdf | Rev. 2, March 2006 | The THT-alternative JFET (BOM): same D-S-G lead order; check Vgs(off) vs the 2N5457 when substituting | `8ceafd60592e75de` |
| `KBP404G-KBP410G_Diodes_DS39310.pdf` | KBP410G bridge rectifier | diodes.com/datasheet/download/KBP404G-KBP410G.pdf | DS39310 Rev. 3-2, February 2026 | **KBP outline** (3.81 mm pitch, 0.86×0.55 mm leads, 14.5×3.5 mm body) and the **+ ~ ~ −** pin order → `Bridge_KBP_P3.81mm`, bridge symbol renumbered | `c13e1a92de6bc9d3` |
| `KBP005G-KBP10G_Diodes_DS21203.pdf` | KBP005G–KBP10G (same KBP package, 1.5 A) | diodes.com/assets/Datasheets/ds21203.pdf | DS21203 Rev. 13-2, August 2025 | Cross-check that the KBP outline is identical across the family | `a714169960729a36` |
| `1N4001-1N4007_Vishay.pdf` | 1N4007 (D1, D2 output clamps) | vishay.com/docs/88503/1n4001.pdf | 29-Apr-2020 | DO-41 dimensions (THT board) | `56a77c6615c90c11` |
| `1N4148_Vishay.pdf` | 1N4148 (D_lfo1/2 LFO clamp) | vishay.com/docs/81857/1n4148.pdf | Rev. 1.6, 07-Nov-2024 | DO-35 dimensions (THT board) | `aefe85400a427ed8` |
| `1N4148W_BAV16W_Diodes_DS30086.pdf` | 1N4148W (SOD-123, SMD variant) | diodes.com/assets/Datasheets/ds30086.pdf | DS30086 Rev. 31-2, September 2024 | SOD-123 replacement for 1N4148 on the SMD board | `39c16a6888bdab22` |
| `VTL5C1_VTL5C2_PerkinElmer_Vactec.pdf` | VTL5C1 vactrol (Xvive remake) | logosfoundation.org/instrum_gwr/playerpiano/Optor_VTL5C1_87223.pdf (hosted copy of the PerkinElmer/Vactec catalog page) | catalog p. 43 (undated) | Package dimensions behind the `VTL5C1` footprint; on/off resistance, response time for the tremolo depth. Xvive publishes no PDF — their part is a drop-in remake | `e6cdace0ba7d05bb` |
| `AS-0524_AnTek.pdf` | AnTek AS-0524 toroid (optional T1) | antekinc.com/content/AS-0524.pdf | AnTek test sheet (undated) | Secondary voltage / VA and the open- and short-circuit test data (Part 9) | `76013dad454a445f` |

## Not committed (no PDF obtainable, or not a single document)

| Part | Why | Where the numbers came from |
|---|---|---|
| **S1M** (SMA rectifier, SMD variant) | Diodes' S1A–S1M sheet was not reachable from this session (404). Any S1M / SMA 1 kV 1 A part is a drop-in; the footprint is KiCad's stock `D_SMA`. | KiCad library footprint; generic JEDEC DO-214AC |
| **KBU4M** (alternative bridge, errata #3) | onsemi's KBU4A–KBU4M sheet was not reachable. KBU is a 5.08 mm-pitch package and needs a footprint swap. | not used on either board |
| **Accutronics / Belton 4FB2A1C** reverb pan | No manufacturer PDF; the distributor spec table is the reference. Input 1475 Ω (200 Ω DC), output 2250 Ω (200 Ω DC), decay 1.75–3.0 s, 2×2 springs, 42.5 × 11 × 3.3 cm, in/out grounded. | amplifiedparts.com/tech-articles/accutronics-products-and-specifications |
| TL072 SPICE model | not a datasheet; the ngspice macromodels are in `spice/models/` | — |

## Reverb-pan code reminder
The Accutronics/Belton 4-digit-plus code encodes the tank: confirm the part is
**4FB2A1C** (high-impedance input ~1475 Ω) and **not** 4AB3C1B (8 Ω input,
incompatible with the direct TL072 driver — see Part 9 / errata Issue 14).

## Verification reminder
Stock and part status drift (see Part 8). Re-check live availability at
Digikey/Mouser and confirm the JFET and bridge selections before ordering — and
if a datasheet revision changes, re-check the package drawing against the
footprint in `kicad/footprints/cambridge_reverb.pretty/`.

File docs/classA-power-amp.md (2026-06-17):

# Class-A power amp — "what it wanted to be" (exploration)

Running the power amp in **Class A** for an AC15-style voice. This note has the
real numbers (simulated) and the honest trade. **Status: explored, not yet built
into the main design** — it's a real architectural change with thermal
consequences (see the question at the end).

## Why it's worth it (the tone)
`spice/tran_classa_output.cir` (transistor-level, single +33.5 V rail, ~0.7 W into
8 Ω) compares the output stage at AB vs Class-A bias:

| Mode | Idle current | THD @ ~0.7 W | What you hear |
|---|---:|---:|---|
| Class **AB** (small idle) | ~0.11 A | **1.05 %** | crossover notch — the SS "stiffness" |
| Class **A** (idle ≥ peak load I) | ~0.49 A | **0.0025 %** | no crossover — smooth, even-harmonic compression |

That ~400× drop in distortion (the crossover region simply vanishes) is exactly
the smooth, compressed, "chimey" character people chase in an AC15. For a guitar
amp the magic is at **low-to-mid volume**, which is precisely where Class A lives.

## The catch (the heat) — Class A is a furnace
Class A draws its full idle current **continuously, signal or not**. On a single
33.5 V rail an idle of ~0.5 A is:

- **~16 W of continuous heat** at idle…
- …for a **Class-A output ceiling of only ~1 W** into 8 Ω (`P = I_A²·R/2`).
  Above ~1 W it slides into Class AB — so you get **pure Class A up to ~1 W,
  then AB up to the ~12 W ceiling** (roast R2). That sliding behaviour is actually
  *ideal* for guitar: Class-A sparkle where you play, full power on tap for loud.

**True 15 W of Class A is not happening in this chassis** — it would be 60 W+ of
continuous heat and need a much bigger rail, transformer, and heatsink. The
buildable, authentic move is **"Class A for the first watt, AB beyond."**

## Recommended implementation: Class-A-biased LM1875 (keep the chipamp)
Add a **constant-current sink** (~0.5 A) from the LM1875 output to ground. The
LM1875's upper (sourcing) transistor then conducts continuously (it always feeds
the CCS), so the stage runs **single-ended Class A up to ±I_A load current**, then
reverts to push-pull AB. Minimal change; keeps the existing supply, gain network,
and output cap.

- **CCS as an LM317 current source** (recognizable, robust): `I_A = 1.25 / R_set`,
  so `R_set ≈ 2.5 Ω (2 W)` for 0.5 A. The LM317 sinks 0.5 A at ~15 V ≈ **7.5 W**;
  the LM1875 idle adds ~**8.4 W** → heat **splits across two devices** (each on its
  own sink → far easier than 16 W in one package). A transistor/MOSFET CCS works
  too.
- **Heatsink:** the existing ≤2.5 °C/W bracket is *marginal* at this dissipation
  (Tj ≈ 130 °C worst-case in a warm room). Recommend **≤1.5 °C/W** per device, or
  accept it runs hot and lower `I_A` (less Class A, less heat). The original
  germanium amp ran warm too — this is in that spirit but warmer.
- **Supply/transformer:** the ~50 VA / ~1 A transformer can feed ~0.5 A of standing
  current plus program; more Class A (higher `I_A`) needs a beefier transformer.

## Knobs / variants
- **`I_A` sets the Class-A window vs heat:** 0.3 A ≈ 0.4 W Class A / ~10 W heat;
  0.5 A ≈ 1 W / ~16 W; 0.75 A ≈ 2.3 W / ~25 W (needs real cooling).
- **Discrete purist option:** a JLH-1969-style discrete Class-A amp is the classic
  "proper" route, but it's ~1.5 A standing (40 W+ heat) for ~10 W and needs a
  bigger supply — a different build, noted for completeness.
- **Switchable:** a panel/internal switch could disable the CCS (back to AB/cool)
  vs enable Class A — but "no new holes," so it'd be an internal jumper.

## Verification
`spice/tran_classa_output.cir` (in `run_all.sh`): AB THD ~1.05 % with ~0.11 A
idle; Class A THD ~0.0025 % with ~0.49 A idle. Heat budget computed above from the
0.49 A standing current.

## Built — variant alongside the AB amp ✅
`kicad/power_amp_classa.kicad_sch` (generated by `kicad/gen/gen_classa.py`) is a
**standalone, ERC-clean** Class-A version of the power-amp sheet: the identical
LM1875 stage **plus** `U_ccs` (LM317 as a constant-current sink, `R_set` = 2.5 Ω
2 W → `I = 1.25/2.5 = 0.5 A` from `PA_OUT` to GND). It's a **drop-in alternative**
to the main `power_amp` sheet — the main board stays Class AB; swap this in to go
Class A.

**Parts the Class-A variant ADDS** over the AB power amp:
| Ref | Part | Note |
|-----|---|---|
| `U_ccs` | **LM317T** (2nd) | wired as a current source; **needs a heatsink** (~7.5 W) |
| `R_set` | **2.5 Ω 2 W** | sets `I_A` = 1.25/R_set = 0.5 A (use 2.4 Ω E24 ≈ 0.52 A) |
| heatsink | **≤1.5 °C/W** on both the LM1875 and the LM317 | the ~16 W standing heat splits across the two devices (~8 W each) |

Regenerate: `python3 kicad/gen/gen_classa.py` (writes the `.kicad_sch` + a minimal
`.kicad_pro`). `kicad-cli sch erc` → **0 violations**.

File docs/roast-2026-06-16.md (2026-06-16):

# Roast pass — 2026-06-16

An adversarial review. Assume nothing the prior passes claimed is right until the
math or the file says so. Each finding below is **verified** (calculation or file
reference), with severity and a fix. Includes errors the *previous audit (mine)
introduced* — those get the harshest light.

Legend: 🔴 must-fix (safety / spec-breaking) · 🟠 real design defect · 🟡 hygiene/clarity.

---
## 🔴 R1 — No mains (primary) fuse. Safety gap.
The only fuse in the whole design is **F1, 1 A slow-blow, on the secondary DC rail**
(`VRAW → +33V5`, i.e. *after* the bridge). There is **no primary/mains fuse**.
A mains-powered amplifier must fuse the primary for fire protection (IEC 60065 /
UL); a secondary-rail fuse does not protect against a shorted transformer primary,
a failed bridge, or a mains fault.
- **Fix (done):** add a **mains primary fuse** in the IEC inlet / before the
  transformer primary. For the ~50 VA transformer: **T630 mA–T1 A, 250 V (5×20 mm)
  slow-blow at 120 V** (≈ T400 mA at 230 V). Added to the BOM and the Part 1
  safety + Part 3 wiring docs. It is panel/inlet-mounted (off-board), like the
  transformer.

## 🔴 R2 — "18 W into 8 Ω" is physically unreachable on a 33.5 V single supply.
Verified: 18 W into 8 Ω needs `Vpeak = √(2·18·8) = 17.0 V`, but a single 33.5 V
rail only offers **16.75 V** peak swing to the rail *at zero saturation*. With the
LM1875's real ~2–4 V saturation the ceiling is:

| Vsat | Vpeak | Pmax (8 Ω) |
|----:|----:|----:|
| 0 V | 16.75 V | 17.5 W (absolute) |
| 2 V | 14.75 V | 13.6 W |
| 3 V | 13.75 V | 11.8 W |
| 4 V | 12.75 V | 10.2 W |

So the rebuild makes **~12 W clean (1 % THD), ~14 W at clipping — never 18 W.**
Perceptually that's only ~1.8 dB down, but the number is propagated as fact into
the engineering:
- **Part 5 thermal** computes LM1875 dissipation "at 18 W into 8 Ω" — an operating
  point that can't occur (conservative, so the heatsink is over-spec'd = safe, but
  the premise is wrong).
- **`component-availability-audit.md` §3 (my error, last pass):** stated "at 18 W,
  peak output current 2.1 A" and "~18 W out ⇒ ~50 VA transformer." Both built on the
  unreachable 18 W. Real numbers: ~12 W out ⇒ peak ~1.7 A, ~0.5 A average ⇒ ~20 W
  draw ⇒ **~30 VA minimum** (the 50 VA AnTek is then comfortable headroom, not a
  tight match). LM1875 worst-case dissipation is *lower* than computed, so the
  ≤2.5 °C/W heatsink is over-spec'd (fine).
- **Fix (done):** corrected Part 5, Part 1 §3, and the availability audit; the
  original-amp spec table keeps 18 W as the *germanium amp's* (10 %-THD) figure
  with a note that the LM1875 rebuild ceilings at ~12 W. If the full 18 W is a
  hard requirement, it needs a different topology (bridged LM1875, or LM3886 /
  TDA7293 on a higher rail) — out of scope, flagged.

## 🟠 R3 — The reverb dry/wet mixer is broken as drawn.
Reverb blend (reverb sheet): `DRY = TONE_OUT —R_dry_tap(1M)→ —R_blend1(220k)→ BLEND`
and `WET —R_blend2(220k)→ BLEND`. The **1 MΩ series resistor in the dry path**
attenuates dry ~5× harder than wet (220 k) → the mix is effectively **all-wet**.
Worse, `BLEND` is an unbuffered high-Z node (~110 kΩ) driving straight into the
tremolo `R_trem1 (10 k)` + LDR → massive signal loss and a hum-prone node. This is
the concrete face of "**ERC-clean ≠ designed**": the inter-effect chain was wired
for connectivity, not for levels/impedance.
- **✅ RESOLVED (2026-06-16):** rebuilt as a real **active inverting summer** on the
  spare **IC1-B** half — dry always on, wet level via `POT_REV`, unity each
  (R_drymix = R_wetmix = R_mixfb = 100 k), output low-Z about `VBIAS_R`. The old
  passive `R_dry_tap`/`R_blend1`/`R_blend2` are gone. A second spare half, **IC2-B**,
  now buffers the post-MRB output into the power amp (was the unbuffered `R_painput`
  1 M). **Verified with a rail-aware model** (`spice/tran_reverb_mixer.cir`,
  `models/opamp_rail.sub`): output biases at **8.50 V** (mid-rail), **0.0 dB** unity
  sum, and clips cleanly at **15.5 V / 1.5 V** → **±7 V headroom** (~24 dB over a
  0.42 V program peak). ERC 0.

## 🟠 R4 — `Wiring_Edge_Array_35` footprint is orphaned.
Defined in `footprints/cambridge_reverb.pretty/`, advertised in `kicad/README.md`
and Part 10 as a deliverable — but **never placed on any board** (`gen_pcb.py`
uses individual pin-header connectors for the off-board wiring). Dead artifact /
overstated deliverable.
- **Fix (done):** README now marks it **unused/reference** (kept for a future
  single-edge wiring layout); it is no longer listed as if it's on the board.

## 🟡 R5 — F1 sits in the C_main inrush path.
F1 (1 A SB) is between the bridge and `C_main` (4700 µF), so it eats the full
turn-on charging surge of 4700 µF on every power-up → nuisance-blow risk and slow
degradation. **Recommend** moving the secondary fuse to the **AC secondary**
(before the bridge), and sizing for inrush. Documented; not auto-changed (it's a
topology choice). Note this is the *secondary* fuse — it does not substitute for
the mains fuse (R1).

## 🟡 R6 — Shared `VBIAS` can bleed tremolo into reverb.
One `R_vb1/R_vb2` (100 k/100 k) divider, bypassed by `C_vb` 10 µF, feeds **both**
IC1 (reverb) and IC2 (tremolo LFO) non-inverting refs. C_vb + 50 kΩ source = a
**0.3 Hz** corner, but the LFO band (1–16 Hz) is *above* it, so LFO current draw
modulates `VBIAS` → the reverb stage rides on a wobbling reference → audible
tremolo bleed into reverb when the LFO runs.
- **✅ RESOLVED (2026-06-16):** split into **two independent dividers** — `VBIAS_R`
  (reverb IC1) and `VBIAS_T` (tremolo IC2), each 100 k/100 k + **47 µF** bypass. The
  LFO now draws from `VBIAS_T` only; it cannot reach the reverb reference at all
  (different nets). ERC 0.

## 🟡 R7 — "Tool-verified" oversells the SPICE.
`models/opamp1p.sub` is a **rail-less** one-pole macromodel. So every single-supply
behaviour that actually matters — output headroom, clipping onset, whether the
reverb driver can swing enough, the real power-amp ceiling (R2!) — is **not
simulated**. "Verified with SPICE" means: small-signal gain/bandwidth of *isolated*
blocks with idealized models. The integrated chain and all large-signal behaviour
are unverified. The SPICE README now says this plainly.

## 🟡 R8 — CHANGELOG is incoherent.
A floating `## Audit pass (2026-06-14)` section sits above `## Unreleased`, which
itself holds dated `### …` subsections — **all stamped 2026-06-14** though the work
spans 06-14 → 06-16. Confusing order, wrong dates. **Fix (done):** consolidated
under `## Unreleased` in chronological order with correct dates.

---
## Scorecard
The project remains an excellent *documentation + tooling* artifact and an
ERC-clean schematic / placed board. But this pass shows the **electrical design is
not build-ready**: a safety-critical fuse is missing (R1), the headline power spec
is unachievable (R2), and the effect-chain mix is non-functional as drawn (R3).
"Reconstructed, verify before building" (PROVENANCE.md) is doing a lot of load-
bearing work — treat the signal chain and power section as *design intent*, not a
validated circuit.

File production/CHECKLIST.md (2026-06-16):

# Production / fab package checklist

What goes in a JLCPCB order package, and the gate checks before you click "order."
Order settings and the full pre-order DRC checklist live in
`../docs/04-jlcpcb-fabrication.md`; this is the packaging/handoff view.

## Fab package contents (per board revision)

```
production/
  vox_cambridge_revA/
    gerbers_revA.zip        # F.Cu B.Cu F.SilkS B.SilkS F.Mask B.Mask Edge.Cuts + .drl
    bom_revA.csv            # snapshot of ../bom/bom.csv at tape-out
    cpl_revA.csv            # pick-and-place (only if using JLCPCB assembly)
    assembly_revA.pdf       # placement / orientation drawing
    NOTES.md                # what changed vs previous rev, known issues
```

Gerbers/zip are regenerated artifacts — `.gitignore` leaves `production/` and
`kicad/gerbers/` untracked by default. Commit a tagged zip only when you want a
frozen, orderable revision in history (uncomment the lines in `.gitignore`).

## JLCPCB order recap (from Part 4)

- 2 layers, **1.6 mm**, **2 oz copper**, HASL(lead), green mask, white silk, tented vias
- Board outline = your measured size (190×115 or 155×90 — errata #9)
- Qty 5 (minimum); ~$2–7 + shipping, under ~$25 total
- "Confirm production file" = Yes; review the Gerber preview every layer

## Pre-order gate (must all pass)

- [ ] DRC clean (zero errors) with the three net classes from
      `../kicad/cambridge_reverb.kicad_pro` (Default / Power / HighCurrent)
- [ ] All zones filled; bottom-layer ground pour continuous, no islands
- [ ] Edge.Cuts is a single closed outline at the measured size
- [ ] Power path: +33V5 / SPK_P / SPK_N / PA_OUT on **HighCurrent (2.5 mm)** class
      (errata #11); VREG_IN / +17V / GND on Power (1.5 mm)
- [ ] LM1875 + LM317 oriented toward the heatsink-side board edge
- [ ] Polarity markers on electrolytics; pin-1 dots on ICs
- [ ] Wiring-edge pads all silkscreen-labeled; one edge only
- [ ] Gerber preview on JLCPCB matches the design on every layer

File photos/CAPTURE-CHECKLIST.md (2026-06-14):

# Photo & measurement capture checklist

Part 7 is emphatic: **measure first, design second.** Fill in the table below from
your specific chassis before finalizing the `Edge.Cuts` outline — every surviving
1960s stamped-steel chassis differs.

## Chassis / PCB measurement table

| Measurement | Value | Notes |
|---|---|---|
| Chassis internal length (mm) | | along the long axis |
| Chassis internal width (mm) | | |
| Usable PCB length = length − 15 mm (mm) | | per Part 7 clearance rule |
| Usable PCB width = width − 15 mm (mm) | | |
| Chosen Edge.Cuts size (mm) | | 190×115 if it fits; else 155×90 (errata #9) |
| Vertical clearance PCB→control panel (mm) | | gates main-cap mounting (Part 7) |
| Tallest component height (main filter cap) (mm) | | split to 2×2200µF if tight |
| Original mounting-hole positions | | match 25-5274-2; measure x/y of each |
| Heatsink-bracket location | | LM1875 mounts where germaniums were |

## Photos to take (before / during / after)

**Before teardown**
- [ ] Full chassis, top and bottom
- [ ] Front control panel (all knob positions/labels)
- [ ] Rear panel (jacks, fuse, power entry)
- [ ] Under-chassis overview before removing anything
- [ ] Close-up of original PCB 25-5274-2 (both sides)
- [ ] Transformer T1 wiring + any markings
- [ ] Heatsink bracket + original output devices
- [ ] Footswitch DIN wiring at the chassis

**During**
- [ ] Wire colors/routing as you remove the loom (label both ends)
- [ ] Pot and jack lug wiring before desoldering
- [ ] Reverb pan part-number sticker (confirm 4FB2A1C vs 4AB3C1B)
- [ ] MRB inductor + its DCR reading

**After / build progress**
- [ ] New PCB populated by stage (PSU → preamp → effects → power amp)
- [ ] DC-rail readings at each test point
- [ ] Final install in chassis

Keep filenames descriptive (`01-chassis-bottom.jpg`, `08-T1-secondary.jpg`).

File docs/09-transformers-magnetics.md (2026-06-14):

# Vox Cambridge Reverb — Part 9: Transformers & Magnetic Components

> Reconstructed document — see `PROVENANCE.md`. Summarized from the project
> design record; verify specifics before purchasing magnetics.

## Power transformer T1
Test the original first (see Part 8 reuse table): secondary should read ~48 VAC.
If healthy, reuse it — it saves the biggest headache. If dead, the **AnTek
AS-0524** toroidal is a candidate replacement (verify secondary voltage/current
against the 33.5 V main rail requirement before buying).

## Eliminated audio transformers
- **Driver transformer T2** — eliminated; the LM1875 needs no phase-splitter.
- **Reverb transformer T3** — eliminated; the TL072 drives the high-impedance
  pan directly.

## Reverb pan impedance matching
Use the **Accutronics 4FB2A1C** (~1475 Ω input impedance). The 8 Ω-input
**4AB3C1B is incompatible** with the direct TL072 driver — do not substitute it.

## MRB inductor
Reuse the original ~1H inductor if its DCR reads ~50–100 Ω and it's not open.
Substitution option: Fasel wah inductors (e.g. 2× ~0.5H in series to approximate 1H).
Default MRB tuning is 600 Hz (68 nF with 1 H).

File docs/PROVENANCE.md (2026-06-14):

# Provenance & reconstruction note

The original Part 1–10 deliverables and errata were generated as downloadable
files in a prior conversation ("Rebuilding Vox Cambridge Reverb solid state amp").
Those original files were not retained.

The documents in this folder were **reconstructed** from:
- Verbatim fragments recovered from that conversation's history (BOM tables,
  schematics, netlist notes, errata issues, SPICE netlist, JLCPCB settings, etc.),
- The project summary of design decisions and constraints.

**What this means for you, the builder:**
- Content recovered verbatim is reliable and matches what was originally produced.
- Where a section was only partially recovered, gaps were filled to keep the
  document coherent. These spots are flagged with `[RECONSTRUCTED]`.
- **Before committing to a board run or parts order, re-verify:** all part
  numbers and live stock status (Part 8), exact component values against the
  errata corrections, and any value you do not see corroborated in the SPICE
  netlist or KiCad netlist notes.
- The errata's three HIGH-severity items are folded into the relevant docs:
  (1) JFET is MMBF5457/J113, not through-hole 2N5457; (2) the 2200µF output
  coupling cap IS required for the LM1875 single-supply design; (3) MRB is
  hardwired 600Hz by default with no new panel holes.

Source conversation: https://claude.ai/chat/0fadd454-0a08-4d0d-b038-77c152ef5d69

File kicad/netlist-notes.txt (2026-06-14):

# Vox Cambridge Reverb — KiCad netlist notes
# Recovered substantially verbatim from the source conversation.
# Per-sheet component lists and connections. Verify against Part 2 / SPICE.

# ====================
# SHEET 7: POWER AMPLIFIER (LM1875 single supply)
# ====================
#   IC_PA    LM1875T/NOPB  Power amplifier
#   R_bias1  22K           Input bias divider (V+ to input)
#   R_bias2  22K           Input bias divider (input to GND)
#   R_fb     22K           Feedback resistor (output to inv input)
#   C_fb_hf  1nF           Feedback HF rolloff (across R_fb)
#   R_gain   1K            Gain-setting resistor
#   C_gain   22uF/25V      Gain LF rolloff cap
#   C_in     1uF/50V       Input coupling cap (film)
#   C_out    2200uF/35V    Output coupling cap
#   R_zobel  10R/1W        Zobel network resistor
#   C_zobel  100nF/100V    Zobel network cap (film)
#   C_byp1   100nF/50V     V+ bypass (MLCC, close to IC)
#   C_byp2   10uF/50V      V+ bypass (electrolytic)
#   D1       1N4007        Output clamp to V+
#   D2       1N4007        Output clamp to GND
#
# Connections:
#   PA_INPUT -> C_in(1uF) -> PA_BIAS
#   +33V5 -> R_bias1(22K) -> PA_BIAS
#   PA_BIAS -> R_bias2(22K) -> GND
#   PA_BIAS -> IC_PA pin1 (non-inv +)
#   IC_PA pin2 (inv -) = PA_INV
#   PA_INV -> R_fb(22K) -> PA_OUT
#   PA_INV -> C_fb_hf(1nF) -> PA_OUT  [parallel with R_fb, HF rolloff]
#   PA_INV -> R_gain(1K) -> C_gain(22uF) -> GND
#   IC_PA pin3 (V-) -> GND
#   IC_PA pin5 (V+) -> +33V5
#   C_byp1(100nF), C_byp2(10uF): IC_PA pin5 to GND [close to IC]
#   IC_PA pin4 (out) = PA_OUT
#   PA_OUT -> C_out(2200uF) -> SPK_POS
#   PA_OUT -> R_zobel(10R) -> C_zobel(100nF) -> GND
#   D1: PA_OUT(cathode) -> +33V5(anode)
#   D2: GND(cathode) -> PA_OUT(anode)
#   SPK_POS -> Speaker(+), Speaker(-) -> GND
#   Gain = 1 + R_fb/R_gain = 1 + 22K/1K = 23x (27.2 dB)

# ====================
# SHEET 4: REVERB (TL072 driver + JFET recovery)
# ====================
#   DRY_SIGNAL_TAP -> IC_REV pin3 (non-inv +)
#   IC_REV pin2 (inv -) -> R_drv2(10K) -> GND
#   IC_REV pin2 (inv -) -> R_drv1(100K) -> IC_REV pin1 (output)
#   IC_REV pin1 -> C_rev1(1uF) -> R_drv3(10R) -> TANK_INPUT
#   TANK_OUTPUT -> C_rev2(10nF) -> Q_rec(gate)
#   Q_rec(gate) -> R_rec_bias(1M) -> GND
#   Q_rec(drain) -> R_rec1(10K) -> +17V_REG
#   Q_rec(source) -> R_rec2(2K2) -> GND
#   C_rec_byp(10uF): across R_rec2
#   Q_rec(drain) -> C_rev4(100nF) -> POT_REV(CW)
#   POT_REV(CCW) -> GND
#   POT_REV(wiper) = WET -> BLEND_JUNCTION
#   DRY_SIGNAL (from volume pot wiper) -> BLEND_JUNCTION
#   BLEND_JUNCTION -> POWER_AMP_INPUT
#   Driver gain = 1 + 100K/10K = 11x

# ====================
# SHEET 5: TREMOLO (Wien bridge LFO + LED/LDR)
# ====================
#   IC2      TL072CP      LFO oscillator (half A) + spare half B
#   VTL1     Xvive VTL5C1 Optocoupler
#   R_lfo1   33K          Wien bridge fixed R
#   R_lfo_ser 100K        Wien bridge series R (limits max freq)
#   R_lfo_fb1 10K / R_lfo_fb2 4K7   Negative feedback divider
#   R_led    1K / R_led_diag 2K2    LED current limiters
#   R_trem1  10K          Signal series resistor
#   C_lfo1   100nF/50V / C_lfo2 100nF/50V   Wien timing (film)
#   C_dc_blk 10uF/25V     LFO DC blocking
#   C_trem_out 100nF/50V  Tremolo output coupling
#   D_lfo1, D_lfo2  1N4148  Amplitude clamp (back-to-back)
#   LED_diag 3mm red      On-board diagnostic LED
#   POT_SPD  500K lin / POT_DPT 100K lin
#   IC2 pin3 (non-inv +) = LFO_POS
#   IC2 pin2 (inv -) = LFO_NEG

# ====================
# SHEET 6: MRB (Mid Resonance Boost)
# ====================
#   MRB_IN -> C_mrb_in(100nF) -> L1(1H) -> C_mrb(68nF) -> C_mrb_out(100nF) -> MRB_OUT
#   Resonant peak at f = 1/(2*pi*sqrt(L*C))
#     L=1H, C=120nF -> ~460 Hz
#     L=1H, C=68nF  -> ~610 Hz  (default 600 Hz position)
#     L=1H, C=47nF  -> ~734 Hz

# ====================
# PCB LAYOUT GUIDELINES (recovered verbatim)
# ====================
# Board outline: 190mm x 115mm (or 155x90mm conservative per Part 7)
# Mounting holes: match original 25-5274-2 positions (measure your board)
# Placement zones L->R: [INPUT/PREAMP][TONE STACK][REVERB/TREM][POWER AMP][PSU]
# Wiring edge: one edge, all off-board connections
# Ground plane: continuous copper pour on bottom layer; star ground near C_main
# Keep-outs: 10mm around LM1875/LM317; 15mm from transformer pads; none under LFO timing
# Trace widths: power rails 2.5mm; 27V/17V rails 1.5mm; signal 0.5mm
# Vias: power 1.0mm drill; signal 0.5mm; ground stitching 0.8mm every 15mm

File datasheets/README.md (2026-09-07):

# datasheets/
Manufacturer datasheet PDFs for the parts whose footprints, pinouts or design
numbers were taken from them (LM1875, LM317, TL072, MMBF5457, 2N5457, J111–J113,
KBP410G + KBP family, 1N4007, 1N4148, 1N4148W, VTL5C1, AnTek AS-0524) — ~15 MB.
`SOURCES.md` is the manifest: source URL, revision, what each sheet backs, and a
SHA-256 prefix so the exact revision used here can be told apart from a newer one.

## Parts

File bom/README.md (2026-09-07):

# bom/

- `bom.csv` — **generated from the schematic** by `kicad/gen/gen_bom.py`
  (regenerate after any schematic change). Electrical rows are 1:1 with the KiCad
  netlist; off-board/mechanical items (sockets, heatsink, mica, standoffs, fuses)
  follow. Do not hand-edit — edit `gen_bom.py` (curated P/Ns + notes) or the
  generator (values/refs).
- `bom-grouped.csv` — consolidated by value+footprint, for ordering.
- `cross-check.md` — the original BOM-vs-docs cross-check notes.

**Re-verify live stock and pricing before ordering** (Part 8 carries the sourcing
notes and discontinued-part alternatives; see also
`../docs/component-availability-audit.md`).

## Build profiles
- `bom.csv` / `bom-grouped.csv` — the **THT** board (`kicad/cambridge_reverb.kicad_pcb`).
- `bom-smd.csv` / `bom-smd-grouped.csv` — the **mixed SMD/THT variant**
  (`kicad/smd/cambridge_reverb_smd.kicad_pcb`): same schematic, 90 small parts on
  0805/1206/1210/SMA/SOD-123/SOT-23 footprints (spec notes instead of the THT part
  numbers — pick JLCPCB "basic" parts or equivalents), everything else identical.
  `production/smd/bom-jlcpcb.csv` + the position file are the JLCPCB assembly
  inputs for the SMD side (LCSC column left for the parts picker).
  Regenerate: `python3 kicad/gen/gen_bom.py --profile smd --jlc`.

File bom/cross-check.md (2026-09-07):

# BOM cross-check (2026-06-14)

Cross-checked `bom.csv` against the recovered component values in
`../docs/02-bom-schematics.md` (Part 2), `../kicad/netlist-notes.txt`, and
`../spice/power_amp_lm1875.cir`. Summary of what was found and what changed.

## 1. Power-amp chain agrees across all four sources — confirmed
The LM1875 values are identical in Part 2, the SPICE netlist, the netlist notes,
and the BOM:

| Value | Part 2 | SPICE `.cir` | netlist-notes | bom.csv |
|---|:---:|:---:|:---:|:---:|
| R_bias1/2 22K | ✓ | ✓ | ✓ | ✓ |
| R_fb 22K | ✓ | ✓ | ✓ | ✓ |
| R_gain 1K | ✓ | ✓ | ✓ | ✓ |
| C_in 1µF | ✓ | ✓ | ✓ | ✓ |
| C_gain 22µF | ✓ | ✓ | ✓ | ✓ |
| C_out 2200µF | ✓ | ✓ | ✓ | ✓ |
| R_zobel 10R / C_zobel 100nF | ✓ | ✓ | ✓ | ✓ |
| Gain = 23× (27 dB) | ✓ | ✓ | ✓ | ✓ |

No action needed on the power amp.

## 2. BOM was missing most preamp / reverb / tremolo / MRB / panel parts — fixed
The previous `bom.csv` was effectively a **power-supply + power-amp + partial-
effects** list. Components that appear in Part 2 and/or `netlist-notes.txt` but
were absent from the BOM have now been **added** (each tagged with its source in
the `notes` column):

- **Preamp (×2 JFET stages):** `R_g1/2` 1M, `R_d1/2` 10K, `R_s1/2` 2K2,
  `C_s1/2` 10µF, `C_in_pre` 47nF.
- **Reverb:** `R_drv1` 100K, `R_drv2` 10K, `R_drv3` 10R, `C_rev1` 1µF,
  `C_rev2` 10nF, `C_rev4` 100nF, `R_rec_bias` 1M, `R_rec1` 10K, `R_rec2` 2K2,
  `C_rec_byp` 10µF, `POT_REV`.
- **Tremolo** *(recovered values — superseded 2026-09-07 by errata #19: the single-arm Wien LFO could not oscillate at tremolo rates; built design = dual-gang 250k speed pot, 15k floors in both arms, 1 µF timing caps; and by errata #22: LED limiter + `Q_trem` vactrol driver, 15 dB depth instead of a fixed −20 dB pad)*: `R_lfo1` 33K, `R_lfo_ser` 100K, `R_lfo_fb1` 10K, `R_lfo_fb2` 4K7,
  `R_led_diag` 2K2, `C_dc_blk` 10µF, `C_trem_out` 100nF, `POT_SPD` 500K,
  `POT_DPT` 100K.
- **Effects loop / panel:** `R_fx_pad` 10K, `POT_VOL`, `POT_TONE` *(superseded
  2026-09-07 by errata #20: the panel's Bass + Treble pots, `POT_BASS`/`POT_TREB`,
  plus the `SW_MID` toggle)*, `J_IN` (×3), `FS_DIN`.
- **Mechanical / safety:** `R_bleed` 10K/5W (filter-cap discharge, from the
  Part 1 safety note), `HS_LM1875`, `INS_MICA`, `SOCKET_IC` (×2), `STANDOFF`.

## 3. SPICE `.cir` was simplified vs the documented model — now addressed
The original (LTspice) power-amp netlist omitted things the docs describe. Rather
than only flag them, an **ngspice-runnable** companion set now exists and was
**executed to verify** the design (`../spice/`, run `./run_all.sh`). The recovered
LTspice `power_amp_lm1875.cir` is left verbatim for provenance; the new
`ac_power_amp_lm1875.cir` adds the missing pieces:

- **`C_fb_hf` (1 nF across R_fb)** — added; the sim now shows the HF −3 dB at
  **6.83 kHz** (≈ the documented 7.2 kHz), confirming the bandwidth limit. The
  original `.cir` had no HF element.
- **10″ speaker model** (Re + Le + 105 Hz mechanical resonance) replaces the plain
  8 Ω resistor.
- **Guitar pickup/cable model** (3 H / 6 kΩ / 100 pF + 300 pF) — still a documented
  rebuild item for a full source-to-speaker chain (noted in `../spice/README.md`).

The sims also surfaced two real findings (both folded into errata):
- **Power-amp LF −3 dB is ~17 Hz, not 7.2 Hz** — the input coupling/bias network
  adds a second LF pole the docs didn't count. Beneficial for guitar.
- **Preamp bias is cold with Rs = 2.2 kΩ** (Vd ≈ 12 V vs the 8–9 V target);
  **Rs ≈ 1–1.2 kΩ** lands it. See errata Issue 15. (BOM note added on R_s1/R_s2.)

## 4. Tone stack — designed (Bass / Treble + MID CUT; errata #20)
The original 25-5274-2 tone-network values were **not recovered**, but the panel
is known: **Bass and Treble** pots. The tone sheet now implements a **passive
James (Thomas-Vox) network** — the topology of the originals, asymmetric, more
cut than boost — driven by a TL074 buffer and followed by a ×2 make-up stage, with
both pots **250 k lin** in the original holes, plus a **switchable MID CUT**
(gyrator-resonated shunt, −9.6 dB @ ~800 Hz, Q ≈ 0.6) on an SPST toggle in the
line-reverse switch hole. Swept in `spice/sweep_tonestack.cir` (results in
`spice/results/`): bass −7.5 … +4.9 dB @ 100 Hz, treble −16.5 … +5.6 dB @
10 kHz, noon flat. The "chime" lives in the preamp (`C_pres` 100 pF) and in
`C_treble` 470 pF, now a bright cap across the volume pot; the earlier 470 pF-only
coupling (a 1.3 kHz high-pass — no bass at all) is replaced by `C_cpl_out` 1 µF.
**If you recover the original 25-5274-2 values**, drop them into the same James
ladder — the buffer / make-up / mid-cut stages do not care.

## 5. Value change applied from the consistency pass
`R_reg2` changed **3.0 kΩ → 3.09 kΩ (E96)** so the LM317 lands inside the stated
17.0–17.5 V window (16.88 V → 17.34 V). See errata Issue 10.

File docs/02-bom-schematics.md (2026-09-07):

# Vox Cambridge Reverb V1031/V1032 — Part 2: BOM & Circuit Schematics

> Reconstructed document — see `PROVENANCE.md`. The power-supply BOM table, the
> tremolo/effects-loop/power-amp ASCII schematics, the gain/bandwidth math, and
> the biasing procedure are recovered substantially verbatim. The preamp,
> tone-stack, and reverb BOM rows marked `[RECONSTRUCTED]` were not fully
> recovered — verify their values against the SPICE netlist and Part 8 before ordering.
>
> **For orderable, availability-checked part numbers, Part 8 is authoritative.**
> Where this part and Part 8 differ, Part 8 wins (e.g. JFET, bridge rectifier).

## Bill of materials

### Power supply

| Ref | Description | Value | Package | Mouser P/N | ~Price |
|-----|---|---|---|---|---|
| BR1 | Bridge rectifier | 4A 1000V | Through-hole | 821-KBU4M (see Part 8: KBP410G preferred) | $0.65 |
| C101–104 | Rectifier snubbing caps | 10nF 100V ceramic | Disc | 594-K104Z15Y5VF5TL2 | $0.10 ea |
| C_main | Main filter cap | 4700µF 50V low-ESR | Radial | 667-EEU-FC1H472 | $3.50 |
| C_filt1 | Secondary filter | 1000µF 50V low-ESR | Radial | 667-EEU-FC1H102 | $1.20 |
| C_filt2 | Secondary filter | 1000µF 50V low-ESR | Radial | 667-EEU-FC1H102 | $1.20 |
| U1 | Voltage regulator (17V rail) | LM317T | TO-220 | 926-LM317T/NOPB | $1.50 |
| R_reg1 | Regulator set resistor | 240Ω 1% 1/4W metal film | Axial | 603-MFR-25FBF52-240R | $0.10 |
| R_reg2 | Regulator set resistor | 3.0kΩ 1% 1/4W metal film | Axial | 603-MFR-25FBF52-3K | $0.10 |
| C_adj | LM317 ADJ-pin bypass (errata #21: ripple rejection 65 → 80 dB, output noise ÷ ~10) | 10µF/25V electrolytic | Radial | — | $0.15 |

> **Errata Issue 10:** 240 Ω + 3.0 kΩ gives Vout = 1.25 × (1 + 3000/240) =
> **16.88 V**, ~0.13 V below the 17.0–17.5 V band quoted in the setup/troubleshooting
> tables. For 17.0–17.5 V use **R_reg2 = 3.09 kΩ (E96)** (→ 17.34 V); the BOM uses
> this value. Alternatively accept ~16.9 V and read the band as 16.8–17.5 V.
| C_reg_in | Regulator input cap | 10µF 50V tantalum | Radial | 581-TAP106K050SCS | $0.80 |
| C_reg_out1 | Regulator output cap | 10µF 25V tantalum | Radial | 581-TAP106K025SCS | $0.60 |
| C_reg_out2 | Regulator output bypass | 100nF 50V MLCC | Disc/radial | 594-K104K15X7RF5TL2 | $0.10 |
| R_27V | LM317-input pre-filter / power-amp decoupling (net `VREG_IN`, ~32 V) | 100Ω 1W metal oxide | Axial | — | $0.20 |
| F1 | Secondary fuse | 1A 250V slow-blow | PCB mount | 576-0273001.H | $0.40 |
| F1_holder | Fuse holder | PCB mount 5×20mm | — | 534-3557 | $0.60 |

### Preamp (JFET) `[RECONSTRUCTED rows — verify vs SPICE/Part 8]`

| Ref | Description | Value | Notes |
|-----|---|---|---|
| Q1, Q2 | N-ch JFET | MMBF5457 (SOT-23 + adapter) or J113 | See Part 8. Bias targets 2N5457 specs |
| R_g | Gate bias to GND | 1MΩ | High-Z input |
| R_d | Drain load | ~10kΩ | Set Vd ≈ 8–9V |
| R_s | Source self-bias | ~2.2kΩ | With bypass cap |
| C_s | Source bypass | 10µF/25V | |
| C_in | Input coupling | ~47nF film | |
| C_pres | Presence rolloff at Q2 drain | 100pF | Guitar-frequency optimization |
| C_cpl_out | Q2 drain → tone coupling | 1µF film | errata #20: the recovered 470 pF-only coupling was a 1.3 kHz high-pass |
| C_treble | Vox "chime" cap — bright cap across the top of the volume pot | 470pF | |
| R_pre, C_pre | `+17V_PRE` rail decoupling for Q1/Q2/Q_rec | 100R, 220µF/25V | errata #21: the JFET stages have ~0 dB PSRR; 7 Hz corner keeps the LM317's noise and ripple out |

### Tone stack — Bass / Treble + MID CUT `[DESIGNED — errata #20]`

Passive James (Thomas-Vox) network with a TL074 buffer / make-up / gyrator /
output buffer (`IC3`, own mid-rail `VBIAS_3`). Swept in `spice/sweep_tonestack.cir`.

| Ref | Description | Value | Notes |
|-----|---|---|---|
| IC3 | Quad op-amp, DIP-14 socket | TL074CN | A buffer, B ×2 make-up, C gyrator, D output buffer |
| R_vb31, R_vb32, C_vb3, C_byp3 | VBIAS_3 divider + bypass | 100K, 100K, 47µF, 100nF | mid-rail for IC3 only (split bias) |
| R_inb | Buffer input bias | 1MΩ | to VBIAS_3 |
| R_j1, R_j2 | Bass ladder end resistors | 10K, 10K | |
| POT_BASS | **Bass** (reused panel pot) | 250K lin | pin 3 (cw) = boost end |
| C_j1, C_j2 | Bass ladder caps (across each pot half) | 22nF, 22nF | film |
| R_j3 | Bass wiper → sum | 68K | |
| C_j3, C_j4 | Treble ladder caps | 2.2nF, 2.2nF | C0G / film |
| POT_TREB | **Treble** (reused panel pot) | 250K lin | |
| R_j4 | Treble wiper → sum | 1K | |
| R_mk1, R_mk2 | Make-up gain 1 + 10K/10K = 2 | 10K, 10K | recovers the network's ~6 dB centre loss |
| R_mid | Series resistor ahead of the mid shunt | 10K | sets the cut depth with R_gL |
| SW_MID | **MID CUT** toggle, SPST, panel | — | in the original line-reverse switch hole |
| C_res | Resonating cap | 22nF | f₀ = 1/(2π√(L·C)) ≈ 790 Hz |
| R_gL, C_gg, R_gg | Gyrator (simulated inductor) | 4K7, 2.2nF, 180K | L = R_gL·R_gg·C_gg = 1.86 H (E24 values, errata #23) |
| C_tout | Output buffer → volume pot | 1µF film | |
| POT_VOL | Volume (reused) | 250K log | C_treble across pins 1–2 |
| R_fx_pad | Internal FX-send tap | 10K | |

Response (250 k lin pots, dB re noon): bass **−7.5 … +4.9 @ 100 Hz**, treble
**−16.5 … +5.6 @ 10 kHz**, noon flat within 0.3 dB, MID CUT **−9.6 dB @ 800 Hz,
Q ≈ 0.6** (−3 dB ≈ 400 Hz … 1.7 kHz), flat when off.

### Power amplifier (LM1875) — recovered verbatim

| Ref | Description | Value | Notes |
|-----|---|---|---|
| IC_PA | Power amplifier, TO-220 | LM1875T/NOPB | |
| R_bias1 | Input bias high | 22K 1% | V+ to the bias node `PA_BREF` |
| R_bias2 | Input bias low | 22K 1% | `PA_BREF` to GND |
| C_bref | Bias-node bypass | 100µF/25V | errata #21: without it the divider fed rail ripple ×23 to the speaker |
| R_bias3 | Bias node → + input | 22K 1% | errata #21; input impedance 22 k, 7 Hz corner with C_in_pa |
| R_fb | Feedback resistor | 22K 1% | |
| C_fb_hf | Feedback HF rolloff (across R_fb) | 1nF | 7.2 kHz bandwidth limit |
| R_gain | Gain-setting resistor | 1K 1% | |
| C_gain | Gain cap (LF rolloff) | 22µF/25V | |
| C_in | Input coupling (film) | 1µF/50V | |
| C_out | Output coupling | 2200µF/35V | **Required** for single-supply (Errata Issue 7) |
| R_zobel | Zobel network R | 10R 1W | |
| C_zobel | Zobel network C (film) | 100nF/100V | |
| C_byp1 | V+ bypass MLCC | 100nF/50V | |
| C_byp2 | V+ bypass electrolytic | 10µF/50V | |
| D1 | Output clamp to V+ | 1N4007 | |
| D2 | Output clamp to GND | 1N4007 | |

### MRB — recovered verbatim

| Ref | Description | Value | Notes |
|-----|---|---|---|
| L1 | MRB inductor | 1H toroid | Reuse original or 2× 0.5H wah (Fasel) |
| C_mrb2 | 600 Hz position (default) | 68nF/50V film | f = 1/(2π√(LC)) ≈ 610 Hz |
| C_mrb1 | 450 Hz position (optional) | 120nF/50V film | ≈ 460 Hz |
| C_mrb3 | 750 Hz position (optional) | 47nF/50V film | ≈ 734 Hz |
| C_mrb_in | Input coupling | 100nF/50V film | |
| C_mrb_out | Output coupling | 100nF/50V film | |

## ASCII schematics

### Power amplifier (LM1875, single supply) — recovered verbatim
```
# LM1875 pin assignments:
#   Pin 1: Non-inverting input (+)
#   Pin 2: Inverting input (-)
#   Pin 3: V- (GND for single-supply)
#   Pin 4: Output
#   Pin 5: V+ (+33.5V)
#
# Connections:
#   AUDIO_IN -> C_in(1uF) -> node_A
#   +33.5V   -> R_bias1(22K) -> node_A
#   node_A   -> R_bias2(22K) -> GND
#   node_A   -> IC_PA pin1 (+)
#   IC_PA pin2 (-) -> R_fb(22K)   -> IC_PA pin4 (output)
#   IC_PA pin2 (-) -> R_gain(1K)  -> C_gain(22uF) -> GND
#   IC_PA pin3 -> GND
#   IC_PA pin5 -> +33.5V
#   C_byp1, C_byp2: pin5 to GND (close to IC)
#   IC_PA pin4 -> C_out(2200uF) -> SPEAKER(+)
#   SPEAKER(-) -> GND (star ground point)
#   R_zobel(10R) + C_zobel(100nF) in series: pin4 to GND
#   D1: pin4(cathode) -> +33.5V(anode)   [clamp to V+]
#   D2: GND(cathode)  -> pin4(anode)      [clamp to GND]
#
# GAIN: Av = 1 + (R_fb / R_gain) = 1 + 22000/1000 = 23 (27.2 dB)
#   Adjustable: R_gain = 2.2K -> Av = 11;  R_gain = 470R -> Av = 48 (max rec.)
# BANDWIDTH:
#   Low -3dB:  f_L = 1/(2π × R_gain × C_gain) = 7.2 Hz
#   High -3dB: set by C_fb_hf(1nF) across R_fb -> ~7.2 kHz (guitar limit)
```

### Tremolo (Wien-bridge LFO + LED/LDR) — recovered verbatim

> **Superseded twice — kept for the record.** Errata #19 replaced the single-arm speed
> pot with a symmetric dual-gang network (the LFO below cannot oscillate at tremolo
> rates), and **errata #22** replaced the LED drive: as drawn the vactrol LED is returned
> to ground from a mid-rail LFO, so it carries ~7 mA DC and the "tremolo" is a fixed
> −20 dB pad with 1.7 dB of wobble. Built design (`kicad/tremolo.kicad_sch`, Part 6c §3):
> antiparallel red LEDs as the LFO limiter (`LED_rate` doubles as the rate indicator),
> `Q_trem` 2N3904 emitter follower AC-coupled from the depth pot (`C_drv` 100 µF,
> 180 k/10 k bias, `R_e` 470 Ω) driving the vactrol LED from +17 V via `R_c` 100 Ω —
> 15 dB depth, 0.8 dB insertion loss.
```
#   IC_TREM   TL072CP    LFO oscillator (uses half)
#   VTL1      VTL5C1     LED/LDR optocoupler
#   R_lfo1/2  33K 1%     Wien bridge R (fixed)
#   R_led     1K         LED current limiter
#   R_led2    1K         Panel/diagnostic LED limiter
#   R_trem1   10K 1%     Signal series resistor
#   C_lfo1/2  100nF/50V  Wien bridge timing C (film)
#   D_lfo1/2  1N4148     Amplitude clamp (back-to-back)
#   LED_rate  3mm red    Diagnostic rate indicator
#   POT_SPD   500K lin   Tremolo speed
#   POT_DPT   100K lin   Tremolo depth
#
#   Output: Pin1 -> POT_DPT(wiper) -> R_led(1K) -> VTL1(LED anode)
#           VTL1(LED cathode) -> GND
#           Pin1 -> R_led2(1K) -> LED_rate -> GND
#   Signal: Audio_in -> R_trem1(10K) -> Audio_out
#                              |
#                          VTL1(LDR)
#                              |
#                             GND
#   When LED bright -> LDR low -> signal shunted; LED dim -> signal passes.
#   LFO freq: f = 1/(2π R C), ~1 Hz (R=500k+33k) to ~10 Hz (R≈33k)
#   [2026-09-07, errata #19: with these values the LFO oscillates only for the bottom
#    ~5 % of the pot and then at 45-80 Hz (a single-arm pot breaks the Wien start
#    condition). Built design: DUAL-GANG 250k lin speed pot, 15k floor in EACH arm,
#    C_lfo1/2 = 1 uF -> 10.6 Hz (fast) .. 0.60 Hz (slow), swept in spice/sweep_lfo_speed.cir.]
```

### Effects loop (internal) — recovered verbatim
```
    FROM VOLUME POT WIPER
         |
         +---- FX SEND JACK (tip)   (switching: normals to return when no plug)
         |          |
         |      R_fx_pad (10kΩ)
         |          |
         +---- FX RETURN JACK (tip)
         |          |
         +---- TO POWER AMP INPUT
```

## Biasing & setup procedure — recovered verbatim

### Step 1: Power-supply verification (no signal)
1. Apply power through a 60 W incandescent bulb in series with AC mains (current limiter).
2. Main rail: 33–35 VDC.
3. LM317 input (`VREG_IN`, after the R_27V/C_filt1 pre-filter): ~31–33 VDC (this
   node is *not* a regulated 27 V — it tracks the main rail minus ~1 V).
4. Regulated 17 V rail: 17.0–17.5 VDC.
5. Confirm before proceeding to signal stages.

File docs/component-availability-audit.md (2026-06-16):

# Component availability, sockets, current-draw & noise audit

Audit of the active/critical parts for **sourceability**, **socketing**, **power
budget / current draw**, and **noise**. Stock/status reflect the project's
2026-era sourcing pass and **will drift — re-verify live before ordering**
(`docs/08-verified-bom.md` is the live-stock reference).

---
## 1. Availability — by tier

### Tier A — jellybean (multi-source, always in stock)
| Part | Role | Notes |
|---|---|---|
| **TL072** (IC1, IC2) | op-amps | TI/ST/onsemi + clones. DIP-8 ubiquitous. Drop-ins: TL072**C/I**, and pin-compatible TL082, and for lower noise NE5532/OPA2134 (see §4). |
| **LM317T** (U1) | 17 V regulator | TI/onsemi/ST/Diodes Inc. TO-220, ubiquitous. |
| **1N4007 / 1N4148** (D1/D2, D_lfo) | clamps | jellybean. |
| **KBP410G** (BR1) | bridge | Comchip/Diodes/multiple; or 4×1N4007. |
| Resistors (MF 1%), film/ceramic/electrolytic caps | passives | Yageo/Vishay/Panasonic/KEMET — multi-source. |

### Tier B — single-vendor but reliably stocked (guitar-amp niche)
| Part | Role | Risk / alternative |
|---|---|---|
| **LM1875T** (IC_PA) | power amp | TI, **active** but effectively single-source (no true second source). Stock fluctuates. Pin-similar fallbacks need a redesign: **LM1875 → TDA2030A** (close, ~14 W) or a discrete chip-amp; **not** drop-in for layout. Buy a spare. |
| **Accutronics/Belton 4FB2A1C** (REVPAN) | reverb pan | Belton (KOR); stocked by Amplified Parts / Antique Electronic Supply / Mod. Confirm the **4FB2A1C** code (high-Z in). Niche but dependable. |
| **AnTek AS-0524** (T1, if not reusing) | transformer | AnTek-direct, single source. **Reuse the original** if it tests good (Part 8/9). |
| **Fasel inductor** (L1, if not reusing) | MRB tank | Dunlop/specialty. **Reuse the original** ~1 H if DCR 50–100 Ω. |

### Tier C — **watch list** (volatile / specialty)
| Part | Role | Why it's a risk | Action |
|---|---|---|---|
| **MMBF5457 / J113** (Q1, Q2, Q_rec) | JFET preamp/recovery | Small-signal **JFETs are being discontinued industry-wide**; the TH 2N5457 is already gone (errata #4). MMBF5457 (SOT-23) and J113 (TO-92) are still active at onsemi but treat as **at-risk**. | Buy lifetime stock. Documented alternatives: J113/J112 (adjust Rs), **LSK170** (audio-grade, pricier, different Idss → re-bias), BF245, or 2N5457 if genuine NOS. The 3 JFETs share one type — qualify one substitute for all. |
| **VTL5C1** (VTL1) | tremolo vactrol | Original PerkinElmer is **EOL (RoHS Cd)**; Xvive clone is the only current source (Amplified Parts / Banzai / Xvive). Single-source. | Alternative already designed in: **DIY LED+LDR** vactrol (matched). Stock a couple of VTL5C1. |

**Bottom line:** the design is dominated by jellybeans. The **two real
single-points-of-failure are the JFETs (Tier C) and the LM1875 (Tier B)** — buy
spares of both. Everything else is either multi-source or reuse-from-original.

---
## 2. Sockets — **all DIP chips socketed**
- **IC1, IC2 (TL072, DIP-8): socket — REQUIRED.** Use **machined / turned-pin**
  (precision) sockets, not stamped dual-wipe: better contact reliability, lower
  contact resistance/noise, and they survive re-seating. The PCB DIP-8 footprint
  already accepts a socket (same pad pattern), so no layout change. BOM updated:
  `SOCKET_IC` ×2, machined-pin (e.g. Mill-Max 110-series / Digikey ED3008-5-ND).
- **LM1875 (IC_PA) and LM317 (U1) are TO-220 power devices — not socketed.**
  The LM1875 must bolt to the heatsink with a mica insulator for its thermal path;
  a socket would break that path and the mechanical mount. The LM317 is low-power
  but conventionally soldered. *If* field-swap is wanted, a TO-220 socket/clip can
  be used on the LM317 only (added as an optional BOM line); the LM1875 should stay
  soldered+bolted. So: **every DIP IC is socketed; the power devices are
  heatsink-mounted by design.**

---
## 3. Current draw & power budget
Estimated operating currents per rail (verify on the bench):

### +17 V regulated rail (preamp + effects)
| Load | Current |
|---|---:|
| Q1, Q2 preamp JFETs (Id) | ~1–2 mA |
| Q_rec recovery JFET | ~0.5 mA |
| IC1 TL072 (Iq) | ~1.4 mA |
| IC2 TL072 (Iq) | ~1.4 mA |
| VBIAS divider (100k+100k) | ~0.09 mA |
| VTL1 LED + LED_rate (avg, LFO-pulsed) | ~3–6 mA |
| **Total +17 V** | **~10–15 mA** |

- **LM317 dissipation:** (Vin − 17.3 V) × ~15 mA. From 27 V that's 0.15 W; even
  direct from 33.5 V it's ~0.24 W → **no heatsink** (matches Part 5).
- **LM317 minimum-load caveat:** the LM317 needs ≥ ~3.5–10 mA load to regulate.
  ~15 mA satisfies it — but if effects are depopulated during bring-up, add a
  small bleed (or the existing load suffices). Worth a bench check.

### `VREG_IN` (LM317 input) — RESOLVED: keep it as a pre-filter, not a "27 V rail"
- In this rebuild the only thing on this node is the **LM317 input** (the op-amps
  run off +17 V, the power amp off +33.5 V) — only ~15 mA. The original `R_27V`
  (47 Ω) drops just **0.7 V** at that current, so the node sits at ~32.8 V, **not
  27 V**: the "27 V rail / 26–28 V" naming was a leftover misnomer.
- **But the resistor is not useless — it's a feature.** `R_27V` + `C_filt1`
  (1000 µF) is an **RC pre-filter on the LM317 input**, and the series R
  **decouples the preamp supply from the power amp's transient current draw** on
  the +33.5 V rail (the LM317's PSRR alone falls off at higher frequency).
  Deleting it would *hurt* noise.
- **Done:** kept the element, **bumped 47 Ω → 100 Ω** (≈6 dB more 120 Hz ripple
  attenuation; only ~1.5 V drop at 15 mA, LM317 in-out diff 14.7 V ≪ 40 V max,
  dissipation 0.02 W), **right-sized 2 W → 1 W**, and **renamed the net `+27V` →
  `VREG_IN`** with the docs/troubleshooting voltage corrected to ~31–33 V. (If you
  ever want a true lower-voltage pre-reg point to cut LM317 dissipation, ~390–470 Ω
  gives ~27 V — but it isn't needed here.)

### +33.5 V main rail (power amp) — corrected (roast R2)
> Earlier this section used 18 W; that's unreachable on a 33.5 V single rail
> (needs 17.0 V peak, only 16.75 V available). The real ceiling is **~12 W clean**.
- LM1875 quiescent ~50 mA; at the real **~12 W into 8 Ω**, peak output current
  ≈ √(2·12/8) = **1.7 A**, average supply current at full sine ≈ peak/π ≈ **0.5 A**
  (guitar program is far lower on average — transient peaks).
- **LM1875 worst-case dissipation** (≈ Vcc²/(2π²·RL) for the single-supply output)
  is **lower than the earlier 15–20 W estimate** at this rail/power, so the
  **≤ 2.5 °C/W heatsink + mica is comfortable** (over-spec'd = safe); thermal
  shutdown still backstops it. C_out (2200 µF) and C_main (4700 µF) are fine.
- **Transformer:** ~12 W out + losses ⇒ ~20 W draw ⇒ **~30 VA minimum**; the
  AnTek AS-0524 (50 VA, 2×24 V @ 1.04 A) is **comfortable headroom** (1.04 A ≫
  0.5 A avg), not a tight match. Bridge KBP410G (4 A) is ample.

---
## 4. Noise
### Already done well (keep)
- **LM317-regulated +17 V preamp rail** — the single biggest hum/noise reduction
  over the original (Part 1).
- **Continuous bottom-layer ground plane** + **star ground** at C_main (Part 3/4).
- **Metal-film 1 % resistors** (low excess/current noise vs carbon).
- **Low-ESR filter caps + rectifier snubbers** (C101–104) — cut diode-switching
  hash and 120 Hz buzz.
- **Signal-left / power-right wire separation**, no signal traces near the
  transformer, none under the LFO timing parts (Part 3/5).
- **JFET preamp** (low-noise, high-Z for the pickup) and **shielded reverb-pan
  cable** (Part 3).

### Recommendations / watch
1. **LED_rate ripple injection (tremolo "tick").** The diagnostic LED draws
   LFO-pulsed current; if it shares the +17 V rail with the preamp it can inject
   LFO-rate ripple → audible ticking. Decouple the LED branch (small series R + the
   rail cap, or a local RC) or drive it from a less sensitive node. Cheap insurance.
2. **VBIAS divider impedance.** 100k+100k = 50k source feeding the op-amp +inputs;
   thermal noise ~28 nV/√Hz. It's bypassed by C_vb (10 µF, corner ~0.3 Hz) so it's
   AC-grounded — fine — but for the reverb driver consider **47k/47k + 47 µF** (or a
   buffer) to drop the source impedance a touch. Minor.
3. **Op-amp choice for the reverb recovery/mix.** TL072 (~18 nV/√Hz) is the
   period-correct, available default. If the reverb path is hissy, **NE5532**
   (~5 nV/√Hz) or **OPA2134** are pin-compatible drop-ins (sockets make this a
   tweak, not a rework) — at slightly higher Iq.
4. **High-Z input.** The 1 MΩ JFET gate is hum-prone; keep input wiring short and
   shielded, grounded at the jack (already noted in Part 3).
5. **Mains safety = mains quiet.** 3-wire ground bonded to chassis; the snubbers
   and a properly grounded transformer frame keep 50/60 Hz down.

---
## Action items
- **Sockets:** done in BOM (machined-pin DIP for IC1/IC2; power devices stay
  heatsink-mounted).
- **+27 V dropper → `VREG_IN` pre-filter (DONE):** kept the element (it's a noise
  feature), bumped 47 Ω→100 Ω / 2 W→1 W, renamed the net, corrected the docs &
  troubleshooting voltage (~32 V, not 27 V). Schematic/PCB regenerated.
- **Stock risk:** buy spare **JFETs** and a spare **LM1875**; qualify one JFET
  substitute for all three positions.
- **LED_rate decoupling:** add a local RC on the indicator branch.

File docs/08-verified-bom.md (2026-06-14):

# Vox Cambridge Reverb — Part 8: Verified In-Stock BOM

> Reconstructed document — see `PROVENANCE.md`. The availability table, the
> Digikey semiconductor rows, the JFET selection guidance, and the parts-to-reuse
> table are recovered substantially verbatim.
>
> **Stock status was accurate as of the original April 2026 search and WILL drift.
> Re-verify live stock and pricing at Digikey/Mouser before ordering.**

## Availability issues found (recovered verbatim)

| Part | Issue | Solution |
|---|---|---|
| 2N5457 (TO-92) | **Discontinued** in through-hole by onsemi | Use MMBF5457 (SOT-23 SMD) on adapter, or J113 through-hole |
| VTL5C1 vactrol | **Original Perkin-Elmer discontinued** (RoHS cadmium ban) | Use Xvive VTL5C1 clone, or DIY LED+LDR |
| TDA2030/TDA2050 | **Discontinued** by ST | Not in our design — we use LM1875 (still active at TI) |
| KBU4M bridge | Available but double-check | KBP410G is a common alternative, same specs |

## Verified semiconductors (recovered verbatim)

| Ref | Description | Digikey P/N | Alt | ~Price | Notes |
|-----|---|---|-----|---|---|
| Q1, Q2, Q_rec | N-ch JFET | MMBF5457CT-ND (SOT-23) | Mouser 863-MMBF5457 | ~$0.60 | Use SOT-23→TO-92 adapter |
| Q1, Q2, Q_rec (ALT) | N-ch JFET TH | J113-ND (TO-92) | Mouser 512-J113 | ~$0.75 | Higher Idss — adjust bias |
| IC_PA | Power amplifier | LM1875T/NOPB-ND | Mouser 926-LM1875T/NOPB | ~$4.50 | Active at TI |
| IC1, IC2 | Dual JFET op-amp | 296-1775-5-ND (TL072CP) | Mouser 595-TL072CP | ~$0.65 | DIP-8 |
| U1 | Voltage regulator | LM317T/NOPB-ND | Mouser 926-LM317T/NOPB | ~$1.50 | TO-220 |
| BR1 | Bridge rectifier | KBP410G-ND | Mouser 821-KBP410G | ~$0.55 | Or 4× 1N4007 |
| D1, D2 | Output clamp diodes | 1N4007-E3/54GICT-ND | Mouser 625-1N4007-E3 | ~$0.12 | |
| D_lfo1, D_lfo2 | Signal diodes | 1N4148FS-ND | Mouser 512-1N4148 | ~$0.05 | |
| LED_rate | 3mm red LED | 160-1127-ND | — | ~$0.15 | |

### JFET selection: MMBF5457 vs J113 (recovered verbatim)
**MMBF5457 on SOT-23 adapter (recommended for accuracy):** exact SMD equivalent
of the 2N5457 — same die, same specs. Adapter boards are pennies from JLCPCB.
Bias values in all documents target 2N5457 specs (Vp ≈ -1.8V, Idss ≈ 3mA) and
work directly. The through-hole 2N5457 has been discontinued and counterfeits
are common — avoid random eBay/Amazon listings.

## Parts to reuse from the original amp (recovered verbatim)

| Part | Condition check | Reuse if… |
|---|---|---|
| Power transformer T1 | Secondary ~48 VAC | Windings intact (no open/short) |
| Potentiometers (×6) | Rotate slowly, listen for scratch | Smooth, no crackle with signal |
| Input jacks (×3) | Tip contact spring tension | Grip the plug firmly |
| Footswitch + DIN cable | Press each button, check continuity | All 3 buttons work, cable intact |
| Speaker (10" Gold Bulldog) | Push cone gently | Moves freely, no rub/tear/burn |
| Reverb pan | Tap springs for "boing" | Springs + transducers OK |
| MRB inductor | DCR ~50–100Ω | Not open circuit |
| Chassis pan + hardware | Visual | No cracks, severe rust |
| Power switch | Click, continuity | Reliable, no intermittent |

**Estimated Digikey order:** ~$45–60 (excluding pots/optocoupler/specialty parts).
**Total project cost, all sources:** ~$80–120.

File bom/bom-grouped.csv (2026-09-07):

qty | value | footprint | refs
1 | KBP410G | Bridge_KBP_P3.81mm | BR1
2 | 1000uF/50V | CP_Radial_D12.5mm_P5.00mm | C_filt1 C_filt2
1 | 2200uF/35V | CP_Radial_D16.0mm_P7.50mm | C_out
1 | 4700uF/50V | CP_Radial_D18.0mm_P7.50mm | C_main
2 | 10uF | CP_Radial_D5.0mm_P2.00mm | C_dc_blk C_rec_byp
3 | 10uF/25V | CP_Radial_D5.0mm_P2.00mm | C_adj C_s1 C_s2
1 | 10uF/50V | CP_Radial_D5.0mm_P2.00mm | C_byp2
1 | 1uF | CP_Radial_D5.0mm_P2.00mm | C_rev1
1 | 22uF/25V | CP_Radial_D5.0mm_P2.00mm | C_gain
1 | 10uF/25V | CP_Radial_D5.0mm_P2.50mm | C_reg_out1
1 | 10uF/50V | CP_Radial_D5.0mm_P2.50mm | C_reg_in
2 | 100uF/25V | CP_Radial_D6.3mm_P2.50mm | C_bref C_drv
1 | 220uF/25V | CP_Radial_D6.3mm_P2.50mm | C_pre
3 | 47uF/25V | CP_Radial_D6.3mm_P2.50mm | C_vb3 C_vbr C_vbt
9 | 100nF | C_Disc_D7.5mm_W2.5mm_P5.00mm | C_byp1 C_byp3 C_cpl12 C_drvin C_mrb_in C_mrb_out C_reg_out2 C_rev4 C_zobel
1 | 100pF | C_Disc_D7.5mm_W2.5mm_P5.00mm | C_pres
1 | 10nF | C_Disc_D7.5mm_W2.5mm_P5.00mm | C_rev2
4 | 10nF/100V | C_Disc_D7.5mm_W2.5mm_P5.00mm | C101 C102 C103 C104
1 | 120nF (opt) | C_Disc_D7.5mm_W2.5mm_P5.00mm | C_mrb_450
1 | 1nF | C_Disc_D7.5mm_W2.5mm_P5.00mm | C_fb_hf
8 | 1uF | C_Disc_D7.5mm_W2.5mm_P5.00mm | C_cpl_out C_drymix C_in_pa C_lfo1 C_lfo2 C_obuf_in C_tout C_wetmix
3 | 2.2nF | C_Disc_D7.5mm_W2.5mm_P5.00mm | C_gg C_j3 C_j4
3 | 22nF | C_Disc_D7.5mm_W2.5mm_P5.00mm | C_j1 C_j2 C_res
1 | 470pF | C_Disc_D7.5mm_W2.5mm_P5.00mm | C_treble
1 | 47nF | C_Disc_D7.5mm_W2.5mm_P5.00mm | C_in_pre
1 | 47nF (opt) | C_Disc_D7.5mm_W2.5mm_P5.00mm | C_mrb_750
1 | 68nF | C_Disc_D7.5mm_W2.5mm_P5.00mm | C_mrb_600
1 | TL074CN | DIP-14_W7.62mm | IC3
2 | TL072CP | DIP-8_W7.62mm | IC1 IC2
2 | 1N4007 | D_DO-41_SOD81_P10.16mm_Horizontal | D1 D2
1 | 1A SB | Fuseholder_Clip-5x20mm_Eaton_1A5601-01_Inline_P20.80x6.76mm_D1.70mm_Horizontal | F1
1 | 1H toroid | Inductor_MRB_1H_Toroid | L1
2 | 3mm red | LED_D3.0mm | LED_lim LED_rate
2 | 100R | R_Axial_DIN0207_L6.3mm_D2.5mm_P5.08mm_Vertical | R_c R_pre
14 | 100k | R_Axial_DIN0207_L6.3mm_D2.5mm_P5.08mm_Vertical | R_drv1 R_drymix R_fs_mrb R_fs_rev R_fs_trem R_mixfb R_obuf_b R_vb31 R_vb32 R_vbr1 R_vbr2 R_vbt1 R_vbt2 R_wetmix
2 | 10R | R_Axial_DIN0207_L6.3mm_D2.5mm_P5.08mm_Vertical | R_drv3 R_zobel
14 | 10k | R_Axial_DIN0207_L6.3mm_D2.5mm_P5.08mm_Vertical | R_b2 R_d1 R_d2 R_drv2 R_fx_pad R_j1 R_j2 R_lfo_fb1 R_mid R_mk1 R_mk2 R_mrb_ser R_rec1 R_trem1
2 | 15k | R_Axial_DIN0207_L6.3mm_D2.5mm_P5.08mm_Vertical | R_lfo_ser R_lfo_sh
2 | 180k | R_Axial_DIN0207_L6.3mm_D2.5mm_P5.08mm_Vertical | R_b1 R_gg
4 | 1M | R_Axial_DIN0207_L6.3mm_D2.5mm_P5.08mm_Vertical | R_g1 R_g2 R_inb R_rec_bias
2 | 1k | R_Axial_DIN0207_L6.3mm_D2.5mm_P5.08mm_Vertical | R_gain R_j4
3 | 2.2k | R_Axial_DIN0207_L6.3mm_D2.5mm_P5.08mm_Vertical | R_rec2 R_s1 R_s2
1 | 220k | R_Axial_DIN0207_L6.3mm_D2.5mm_P5.08mm_Vertical | R_drvbias
4 | 22k | R_Axial_DIN0207_L6.3mm_D2.5mm_P5.08mm_Vertical | R_bias1 R_bias2 R_bias3 R_fb
1 | 240R | R_Axial_DIN0207_L6.3mm_D2.5mm_P5.08mm_Vertical | R_reg1
1 | 3.09k | R_Axial_DIN0207_L6.3mm_D2.5mm_P5.08mm_Vertical | R_reg2
2 | 4.7k | R_Axial_DIN0207_L6.3mm_D2.5mm_P5.08mm_Vertical | R_gL R_lfo_fb2
1 | 470R | R_Axial_DIN0207_L6.3mm_D2.5mm_P5.08mm_Vertical | R_e
1 | 68k | R_Axial_DIN0207_L6.3mm_D2.5mm_P5.08mm_Vertical | R_j3
1 | 0R | R_Axial_DIN0414_L11.9mm_D4.5mm_P15.24mm_Horizontal | R_spk_rtn
1 | 100R/1W | R_Axial_DIN0414_L11.9mm_D4.5mm_P15.24mm_Horizontal | R_27V
1 | 10k/5W | R_Axial_Power_L20.0mm_W6.4mm_P25.40mm | R_bleed
1 | LM317T | TO-220-3_Vertical | U1
1 | LM1875T | TO-220-5_Vertical_P1.70mm_LM1875 | IC_PA
1 | 2N3904 | TO-92_Inline_Wide | Q_trem
3 | MMBF5457 | TO-92_Inline_Wide | Q1 Q2 Q_rec
28 | test point (label = net) | TestPoint_THT_D2.0mm_Label | TP_17V TP_33V5 TP_BLEND TP_GND_PA TP_GND_PRE TP_GND_PSU TP_GND_REV TP_GND_TREM TP_LFO TP_MK_OUT TP_MRB_OUT TP_PA_BIAS TP_PA_IN TP_PA_OUT TP_PRE_OUT TP_Q1D TP_Q2D TP_QRD TP_SPK TP_TANK_IN TP_TANK_OUT TP_TONE_OUT TP_TREM_OUT TP_VBIAS_3 TP_VBIAS_R TP_VBIAS_T TP_VRAW TP_VREG_IN
1 | VTL5C1 | VTL5C1 | VTL1
1 | IN3 / FX return | WirePad_1x02_P2.54mm_D1.2mm | J_IN3
1 | Input 1 | WirePad_1x02_P2.54mm_D1.2mm | J_IN1
1 | Input 2 | WirePad_1x02_P2.54mm_D1.2mm | J_IN2
1 | MID CUT | WirePad_1x02_P2.54mm_D1.2mm | SW_MID
1 | 10in Bulldog | WirePad_1x02_P5.08mm_D1.5mm | LS1
1 | 100k lin | WirePad_1x03_P2.54mm_D1.2mm | POT_DPT
2 | 250k lin | WirePad_1x03_P2.54mm_D1.2mm | POT_BASS POT_TREB
2 | 250k lin dual | WirePad_1x03_P2.54mm_D1.2mm | POT_SPD_A POT_SPD_B
1 | 250k log | WirePad_1x03_P2.54mm_D1.2mm | POT_VOL
1 | reuse | WirePad_1x03_P2.54mm_D1.2mm | POT_REV
1 | reuse / AnTek AS-0524 | WirePad_1x03_P5.08mm_D1.5mm | T1
1 | 4FB2A1C | WirePad_1x04_P2.54mm_D1.2mm | REV1
1 | DIN-6 | WirePad_1x06_P2.54mm_D1.2mm | FS1

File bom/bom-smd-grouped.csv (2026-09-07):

qty | value | footprint | refs
1 | KBP410G | Bridge_KBP_P3.81mm | BR1
2 | 1000uF/50V | CP_Radial_D12.5mm_P5.00mm | C_filt1 C_filt2
1 | 2200uF/35V | CP_Radial_D16.0mm_P7.50mm | C_out
1 | 4700uF/50V | CP_Radial_D18.0mm_P7.50mm | C_main
2 | 10uF | CP_Radial_D5.0mm_P2.00mm | C_dc_blk C_rec_byp
3 | 10uF/25V | CP_Radial_D5.0mm_P2.00mm | C_adj C_s1 C_s2
1 | 10uF/50V | CP_Radial_D5.0mm_P2.00mm | C_byp2
1 | 1uF | CP_Radial_D5.0mm_P2.00mm | C_rev1
1 | 22uF/25V | CP_Radial_D5.0mm_P2.00mm | C_gain
1 | 10uF/25V | CP_Radial_D5.0mm_P2.50mm | C_reg_out1
1 | 10uF/50V | CP_Radial_D5.0mm_P2.50mm | C_reg_in
2 | 100uF/25V | CP_Radial_D6.3mm_P2.50mm | C_bref C_drv
1 | 220uF/25V | CP_Radial_D6.3mm_P2.50mm | C_pre
3 | 47uF/25V | CP_Radial_D6.3mm_P2.50mm | C_vb3 C_vbr C_vbt
9 | 100nF | C_1206_3216Metric | C_byp1 C_byp3 C_cpl12 C_drvin C_mrb_in C_mrb_out C_reg_out2 C_rev4 C_zobel
1 | 100pF | C_1206_3216Metric | C_pres
1 | 10nF | C_1206_3216Metric | C_rev2
4 | 10nF/100V | C_1206_3216Metric | C101 C102 C103 C104
1 | 120nF (opt) | C_1206_3216Metric | C_mrb_450
1 | 1nF | C_1206_3216Metric | C_fb_hf
8 | 1uF | C_1206_3216Metric | C_cpl_out C_drymix C_in_pa C_lfo1 C_lfo2 C_obuf_in C_tout C_wetmix
3 | 2.2nF | C_1206_3216Metric | C_gg C_j3 C_j4
3 | 22nF | C_1206_3216Metric | C_j1 C_j2 C_res
1 | 470pF | C_1206_3216Metric | C_treble
1 | 47nF | C_1206_3216Metric | C_in_pre
1 | 47nF (opt) | C_1206_3216Metric | C_mrb_750
1 | 68nF | C_1206_3216Metric | C_mrb_600
1 | TL074CN | DIP-14_W7.62mm | IC3
2 | TL072CP | DIP-8_W7.62mm | IC1 IC2
2 | 1N4007 | D_SMA | D1 D2
1 | 1A SB | Fuseholder_Clip-5x20mm_Eaton_1A5601-01_Inline_P20.80x6.76mm_D1.70mm_Horizontal | F1
1 | 1H toroid | Inductor_MRB_1H_Toroid | L1
2 | 3mm red | LED_D3.0mm | LED_lim LED_rate
2 | 100R | R_0805_2012Metric | R_c R_pre
14 | 100k | R_0805_2012Metric | R_drv1 R_drymix R_fs_mrb R_fs_rev R_fs_trem R_mixfb R_obuf_b R_vb31 R_vb32 R_vbr1 R_vbr2 R_vbt1 R_vbt2 R_wetmix
1 | 10R | R_0805_2012Metric | R_drv3
14 | 10k | R_0805_2012Metric | R_b2 R_d1 R_d2 R_drv2 R_fx_pad R_j1 R_j2 R_lfo_fb1 R_mid R_mk1 R_mk2 R_mrb_ser R_rec1 R_trem1
2 | 15k | R_0805_2012Metric | R_lfo_ser R_lfo_sh
2 | 180k | R_0805_2012Metric | R_b1 R_gg
4 | 1M | R_0805_2012Metric | R_g1 R_g2 R_inb R_rec_bias
2 | 1k | R_0805_2012Metric | R_gain R_j4
1 | 220k | R_0805_2012Metric | R_drvbias
4 | 22k | R_0805_2012Metric | R_bias1 R_bias2 R_bias3 R_fb
1 | 240R | R_0805_2012Metric | R_reg1
2 | 4.7k | R_0805_2012Metric | R_gL R_lfo_fb2
1 | 470R | R_0805_2012Metric | R_e
1 | 68k | R_0805_2012Metric | R_j3
1 | 3.09k | R_1206_3216Metric | R_reg2
1 | 10R | R_Axial_DIN0207_L6.3mm_D2.5mm_P5.08mm_Vertical | R_zobel
3 | 2.2k | R_Axial_DIN0207_L6.3mm_D2.5mm_P5.08mm_Vertical | R_rec2 R_s1 R_s2
1 | 0R | R_Axial_DIN0414_L11.9mm_D4.5mm_P15.24mm_Horizontal | R_spk_rtn
1 | 100R/1W | R_Axial_DIN0414_L11.9mm_D4.5mm_P15.24mm_Horizontal | R_27V
1 | 10k/5W | R_Axial_Power_L20.0mm_W6.4mm_P25.40mm | R_bleed
3 | MMBF5457 | SOT-23 | Q1 Q2 Q_rec
1 | 2N3904 | SOT-23_MMBT3904_as_EBC | Q_trem
1 | LM317T | TO-220-3_Vertical | U1
1 | LM1875T | TO-220-5_Vertical_P1.70mm_LM1875 | IC_PA
28 | test point (label = net) | TestPoint_THT_D2.0mm_Label | TP_17V TP_33V5 TP_BLEND TP_GND_PA TP_GND_PRE TP_GND_PSU TP_GND_REV TP_GND_TREM TP_LFO TP_MK_OUT TP_MRB_OUT TP_PA_BIAS TP_PA_IN TP_PA_OUT TP_PRE_OUT TP_Q1D TP_Q2D TP_QRD TP_SPK TP_TANK_IN TP_TANK_OUT TP_TONE_OUT TP_TREM_OUT TP_VBIAS_3 TP_VBIAS_R TP_VBIAS_T TP_VRAW TP_VREG_IN
1 | VTL5C1 | VTL5C1 | VTL1
1 | IN3 / FX return | WirePad_1x02_P2.54mm_D1.2mm | J_IN3
1 | Input 1 | WirePad_1x02_P2.54mm_D1.2mm | J_IN1
1 | Input 2 | WirePad_1x02_P2.54mm_D1.2mm | J_IN2
1 | MID CUT | WirePad_1x02_P2.54mm_D1.2mm | SW_MID
1 | 10in Bulldog | WirePad_1x02_P5.08mm_D1.5mm | LS1
1 | 100k lin | WirePad_1x03_P2.54mm_D1.2mm | POT_DPT
2 | 250k lin | WirePad_1x03_P2.54mm_D1.2mm | POT_BASS POT_TREB
2 | 250k lin dual | WirePad_1x03_P2.54mm_D1.2mm | POT_SPD_A POT_SPD_B
1 | 250k log | WirePad_1x03_P2.54mm_D1.2mm | POT_VOL
1 | reuse | WirePad_1x03_P2.54mm_D1.2mm | POT_REV
1 | reuse / AnTek AS-0524 | WirePad_1x03_P5.08mm_D1.5mm | T1
1 | 4FB2A1C | WirePad_1x04_P2.54mm_D1.2mm | REV1
1 | DIN-6 | WirePad_1x06_P2.54mm_D1.2mm | FS1

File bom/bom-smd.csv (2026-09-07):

# GENERATED from the schematic by kicad/gen/gen_bom.py -- do not hand-edit.
# Electrical rows are 1:1 with the KiCad netlist; mechanical/off-board items follow.
ref | description | value | footprint | digikey_pn | mouser_pn | qty | notes
C_mrb_450 | Capacitor (film/ceramic) | 120nF (opt) | C_1206_3216Metric |  |  | 1 | 1206 50 V; C0G/NP0 in the signal path (X7R ok for supply bypass); snubbers 100 V X7R
C_mrb_600 | Capacitor (film/ceramic) | 68nF | C_1206_3216Metric |  |  | 1 | 1206 50 V; C0G/NP0 in the signal path (X7R ok for supply bypass); snubbers 100 V X7R
C_mrb_750 | Capacitor (film/ceramic) | 47nF (opt) | C_1206_3216Metric |  |  | 1 | 1206 50 V; C0G/NP0 in the signal path (X7R ok for supply bypass); snubbers 100 V X7R
C_mrb_in | Capacitor (film/ceramic) | 100nF | C_1206_3216Metric |  |  | 1 | 1206 50 V; C0G/NP0 in the signal path (X7R ok for supply bypass); snubbers 100 V X7R
C_mrb_out | Capacitor (film/ceramic) | 100nF | C_1206_3216Metric |  |  | 1 | 1206 50 V; C0G/NP0 in the signal path (X7R ok for supply bypass); snubbers 100 V X7R
L1 | MRB tank inductor (reused/off-board) | 1H toroid | Inductor_MRB_1H_Toroid |  |  | 1 | reuse original ~1H, or 2x 0.5H Fasel
R_fs_mrb | Resistor | 100k | R_0805_2012Metric |  |  | 1 | 0805 1% (thin-film for the 1M gate / input resistors; thick-film elsewhere); JLCPCB basic
R_mrb_ser | Resistor | 10k | R_0805_2012Metric |  |  | 1 | 0805 1% (thin-film for the 1M gate / input resistors; thick-film elsewhere); JLCPCB basic
TP_MRB_OUT | Test point (header pin or wire loop) | MRB | TestPoint_THT_D2.0mm_Label |  |  | 1 | bench test point: fit a header pin or a bare 0.6 mm wire loop; silk shows the net
C_bref | LM1875 bias-divider bypass (kills the rail-ripple path into the + input) | 100uF/25V | CP_Radial_D6.3mm_P2.50mm |  |  | 1 | 100 uF/25 V bypass on the LM1875 bias divider; without it the divider injected rail ripple x23 into the speaker (spice/ac_hum_psrr.cir)
C_byp1 | Capacitor (film/ceramic) | 100nF | C_1206_3216Metric |  |  | 1 | 1206 50 V; C0G/NP0 in the signal path (X7R ok for supply bypass); snubbers 100 V X7R
C_byp2 | Capacitor (electrolytic) | 10uF/50V | CP_Radial_D5.0mm_P2.00mm |  |  | 1
C_fb_hf | Capacitor (film/ceramic) | 1nF | C_1206_3216Metric |  |  | 1 | 1206 50 V; C0G/NP0 in the signal path (X7R ok for supply bypass); snubbers 100 V X7R
C_gain | Capacitor (electrolytic) | 22uF/25V | CP_Radial_D5.0mm_P2.00mm |  |  | 1
C_in_pa | Capacitor (film/ceramic) | 1uF | C_1206_3216Metric |  |  | 1 | 1206 50 V; C0G/NP0 in the signal path (X7R ok for supply bypass); snubbers 100 V X7R
C_out | Capacitor (electrolytic) | 2200uF/35V | CP_Radial_D16.0mm_P7.50mm |  |  | 1 | REQUIRED for single-supply (errata #7)
C_zobel | Capacitor (film/ceramic) | 100nF | C_1206_3216Metric |  |  | 1 | 1206 50 V; C0G/NP0 in the signal path (X7R ok for supply bypass); snubbers 100 V X7R
D1 | Diode | 1N4007 | D_SMA |  |  | 1 | S1M (1 kV 1 A SMA) replaces 1N4007; was: output clamp
D2 | Diode | 1N4007 | D_SMA |  |  | 1 | S1M (1 kV 1 A SMA) replaces 1N4007; was: output clamp
IC_PA | Power amplifier | LM1875T | TO-220-5_Vertical_P1.70mm_LM1875 | LM1875T/NOPB-ND | 926-LM1875T/NOPB | 1 | Single-source (TI) - buy a spare. Heatsink <=2.5 C/W + mica; NOT socketed
R_bias1 | Resistor | 22k | R_0805_2012Metric |  |  | 1 | 0805 1% (thin-film for the 1M gate / input resistors; thick-film elsewhere); JLCPCB basic
R_bias2 | Resistor | 22k | R_0805_2012Metric |  |  | 1 | 0805 1% (thin-film for the 1M gate / input resistors; thick-film elsewhere); JLCPCB basic
R_bias3 | LM1875 + input bias feed (from the bypassed divider) | 22k | R_0805_2012Metric |  |  | 1 | 0805 1% (thin-film for the 1M gate / input resistors; thick-film elsewhere); JLCPCB basic
R_fb | Resistor | 22k | R_0805_2012Metric |  |  | 1 | 0805 1% (thin-film for the 1M gate / input resistors; thick-film elsewhere); JLCPCB basic
R_gain | Resistor | 1k | R_0805_2012Metric |  |  | 1 | 0805 1% (thin-film for the 1M gate / input resistors; thick-film elsewhere); JLCPCB basic
R_zobel | Resistor | 10R | R_Axial_DIN0207_L6.3mm_D2.5mm_P5.08mm_Vertical |  |  | 1
TP_GND_PA | Test point (header pin or wire loop) | GND | TestPoint_THT_D2.0mm_Label |  |  | 1 | bench test point: fit a header pin or a bare 0.6 mm wire loop; silk shows the net
TP_PA_BIAS | Test point (header pin or wire loop) | PA_B | TestPoint_THT_D2.0mm_Label |  |  | 1 | bench test point: fit a header pin or a bare 0.6 mm wire loop; silk shows the net
TP_PA_OUT | Test point (header pin or wire loop) | PA_OUT | TestPoint_THT_D2.0mm_Label |  |  | 1 | bench test point: fit a header pin or a bare 0.6 mm wire loop; silk shows the net
TP_SPK | Test point (header pin or wire loop) | SPK | TestPoint_THT_D2.0mm_Label |  |  | 1 | bench test point: fit a header pin or a bare 0.6 mm wire loop; silk shows the net
BR1 | Bridge rectifier | KBP410G | Bridge_KBP_P3.81mm | KBP410G-ND | 821-KBP410G | 1 | Or 4x 1N4007
C101 | Capacitor (film/ceramic) | 10nF/100V | C_1206_3216Metric |  |  | 1 | 1206 50 V; C0G/NP0 in the signal path (X7R ok for supply bypass); snubbers 100 V X7R; was: bridge snubber
C102 | Capacitor (film/ceramic) | 10nF/100V | C_1206_3216Metric |  |  | 1 | 1206 50 V; C0G/NP0 in the signal path (X7R ok for supply bypass); snubbers 100 V X7R; was: bridge snubber
C103 | Capacitor (film/ceramic) | 10nF/100V | C_1206_3216Metric |  |  | 1 | 1206 50 V; C0G/NP0 in the signal path (X7R ok for supply bypass); snubbers 100 V X7R; was: bridge snubber
C104 | Capacitor (film/ceramic) | 10nF/100V | C_1206_3216Metric |  |  | 1 | 1206 50 V; C0G/NP0 in the signal path (X7R ok for supply bypass); snubbers 100 V X7R; was: bridge snubber
C_adj | LM317 ADJ bypass: +15 dB ripple rejection, ~10x less rail noise | 10uF/25V | CP_Radial_D5.0mm_P2.00mm |  |  | 1 | 10 uF/25 V on the LM317 ADJ pin (TI: 65 -> 80 dB ripple rejection; output noise falls ~10x) -- spice/noise_frontend.cir
C_filt1 | Capacitor (electrolytic) | 1000uF/50V | CP_Radial_D12.5mm_P5.00mm |  | 667-EEU-FC1H102 | 1 | low-ESR pre-filter bulk
C_filt2 | Capacitor (electrolytic) | 1000uF/50V | CP_Radial_D12.5mm_P5.00mm |  | 667-EEU-FC1H102 | 1 | low-ESR pre-filter bulk
C_main | Capacitor (electrolytic) | 4700uF/50V | CP_Radial_D18.0mm_P7.50mm |  | 667-EEU-FC1H472 | 1 | low-ESR; or 2x2200uF if PCB-mounted (errata #16)
C_pre | Preamp rail decoupling (with R_pre) | 220uF/25V | CP_Radial_D6.3mm_P2.50mm |  |  | 1 | 220 uF/25 V; with R_pre 100R a 7 Hz corner on the preamp/recovery JFET rail -- the resistor-loaded JFET stages have ~0 dB PSRR
C_reg_in | Capacitor (electrolytic) | 10uF/50V | CP_Radial_D5.0mm_P2.50mm |  | 581-TAP106K050SCS | 1 | tantalum
C_reg_out1 | Capacitor (electrolytic) | 10uF/25V | CP_Radial_D5.0mm_P2.50mm |  | 581-TAP106K025SCS | 1 | tantalum
C_reg_out2 | Capacitor (film/ceramic) | 100nF | C_1206_3216Metric |  |  | 1 | 1206 50 V; C0G/NP0 in the signal path (X7R ok for supply bypass); snubbers 100 V X7R
C_vbr | Capacitor (electrolytic) | 47uF/25V | CP_Radial_D6.3mm_P2.50mm |  |  | 1
C_vbt | Capacitor (electrolytic) | 47uF/25V | CP_Radial_D6.3mm_P2.50mm |  |  | 1
F1 | Fuse | 1A SB | Fuseholder_Clip-5x20mm_Eaton_1A5601-01_Inline_P20.80x6.76mm_D1.70mm_Horizontal |  | 576-0273001.H | 1 | secondary fuse; prefer AC-secondary placement (roast R5)
R_27V | Resistor | 100R/1W | R_Axial_DIN0414_L11.9mm_D4.5mm_P15.24mm_Horizontal |  |  | 1 | LM317-input RC pre-filter w/ C_filt1 (VREG_IN ~32V, roast R2)
R_bleed | Resistor | 10k/5W | R_Axial_Power_L20.0mm_W6.4mm_P25.40mm |  |  | 1
R_pre | Preamp rail decoupling (with C_pre) | 100R | R_0805_2012Metric |  |  | 1 | 0805 1% (thin-film for the 1M gate / input resistors; thick-film elsewhere); JLCPCB basic
R_reg1 | Resistor | 240R | R_0805_2012Metric |  |  | 1 | 0805 1% (thin-film for the 1M gate / input resistors; thick-film elsewhere); JLCPCB basic
R_reg2 | Resistor | 3.09k | R_1206_3216Metric |  |  | 1 | 1206 1% 0.25 W (dissipates ~85 mW); was: 3.09k E96 -> 17.34V (errata #10)
R_vbr1 | Resistor | 100k | R_0805_2012Metric |  |  | 1 | 0805 1% (thin-film for the 1M gate / input resistors; thick-film elsewhere); JLCPCB basic
R_vbr2 | Resistor | 100k | R_0805_2012Metric |  |  | 1 | 0805 1% (thin-film for the 1M gate / input resistors; thick-film elsewhere); JLCPCB basic
R_vbt1 | Resistor | 100k | R_0805_2012Metric |  |  | 1 | 0805 1% (thin-film for the 1M gate / input resistors; thick-film elsewhere); JLCPCB basic
R_vbt2 | Resistor | 100k | R_0805_2012Metric |  |  | 1 | 0805 1% (thin-film for the 1M gate / input resistors; thick-film elsewhere); JLCPCB basic
T1 | Power transformer (reused/off-board) | reuse / AnTek AS-0524 | WirePad_1x03_P5.08mm_D1.5mm |  |  | 1 | reuse original (test ~48VAC) or AnTek AS-0524 50VA
TP_17V | Test point (header pin or wire loop) | +17V | TestPoint_THT_D2.0mm_Label |  |  | 1 | bench test point: fit a header pin or a bare 0.6 mm wire loop; silk shows the net
TP_33V5 | Test point (header pin or wire loop) | +33V5 | TestPoint_THT_D2.0mm_Label |  |  | 1 | bench test point: fit a header pin or a bare 0.6 mm wire loop; silk shows the net
TP_GND_PSU | Test point (header pin or wire loop) | GND | TestPoint_THT_D2.0mm_Label |  |  | 1 | bench test point: fit a header pin or a bare 0.6 mm wire loop; silk shows the net
TP_VRAW | Test point (header pin or wire loop) | VRAW | TestPoint_THT_D2.0mm_Label |  |  | 1 | bench test point: fit a header pin or a bare 0.6 mm wire loop; silk shows the net
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

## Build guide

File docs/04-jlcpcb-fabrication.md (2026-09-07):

# Vox Cambridge Reverb — Part 4: JLCPCB Fabrication Guide

> Reconstructed document — see `PROVENANCE.md`. Order specs, design rules, net
> classes, Gerber/drill export steps, silkscreen layout, and the pre-order
> checklist are recovered substantially verbatim.
>
> Note: the board outline below shows 190×115 mm (matching the original
> 25-5274-2 footprint). Part 7 recommends 155×90 mm as a conservative default
> pending chassis measurement. Use whichever your measured chassis supports;
> set the Edge.Cuts outline accordingly.

## JLCPCB order specifications — recovered verbatim

| Parameter | Setting | Notes |
|---|---|---|
| Layers | 2 | Top copper + bottom copper (ground plane) |
| Dimensions | 190 × 115 mm | Matches original 25-5274-2 board footprint |
| PCB Qty | 5 | Minimum order |
| PCB Thickness | 1.6 mm | Matches original board thickness |
| Copper Weight | 2 oz *(1 oz is enough — see the 2026-09-07 rules note below)* | Handles power-amp traces better |
| Surface Finish | HASL (with lead) | Best for hand-soldering through-hole; cheapest |
| Solder Mask | Green | Fastest processing |
| Silkscreen | White | Standard |
| Via Covering | Tented | Protects vias from solder bridges |
| Confirm Production File | Yes | Always review the Gerber preview |
| Remove Order Number | Specify location | "JLCJLCJLC" text on silkscreen, or pay $1 to remove |

Estimated cost: ~$2–7 for 5 boards + ~$5–15 shipping. Under $25 total.

> **2026-09-07:** 190 × 115 mm is above the $2 "100 × 100 mm" tier, so the bare board is
> area-priced (a live quote is the only reliable number); choose **1 oz** copper and
> **lead-free HASL** unless you have a reason not to — both are the no-surcharge defaults.

## SMT assembly of the mixed SMD/THT board (`kicad/smd/`) — cost model, added 2026-09-07

JLCPCB's economic assembly is priced per **solder joint** and per **part type**, not per
board area: setup $8 + stencil $1.50 + $0.0016 per joint, plus **$3 per order for every
"extended" (non-basic-library) part type**. `kicad/gen/jlc_cost.py` reads the generated
assembly BOM and shows which knob moves the number:

| | Before | After (errata #23) |
|---|---:|---:|
| SMD parts placed / assembly lines | 90 / 31 | 91 / 29 |
| Extended part types (× $3) | 7 ($21) | 2 ($6: MMBF5457 SOT-23, 3.09 k E96) |
| Joints per board | 183 | ~187 |
| Assembly for 5 boards (estimate) | ~$32 | **~$17** |

What changed: every SMD capacitor is **1206** (the 1210 line — 1 µF X7R 50 V and the
Zobel 100 nF — was an extended part for no electrical gain; 1206 1 µF/50 V X7R is a
basic part), the two optional MRB caps (`C_mrb_450`, `C_mrb_750`, marked "(opt)") are
**DNP** — on the board, excluded from the assembly BOM and the position file — and the
mid-cut gyrator uses **2.2 nF / 180 k** (E24, same 1.86 H) instead of 1.8 nF / 220 k.
Three **fiducials** (1 mm copper, 2 mm mask; `FID1–3`, an asymmetric set) sit in the
margins for the placement camera. Rotation of SOT-23 and SMA parts in JLC's preview must
still be checked by eye (KiCad's 0° and JLC's 0° differ for some packages).

## KiCad design rules for JLCPCB — recovered, re-checked 2026-09-07

The "JLCPCB min" column is from jlcpcb.com/capabilities (2-layer, 1 oz, checked
2026-09-07); the "Value" column is what both `.kicad_pro` files now enforce in DRC, so
`kicad/gen/check.sh` catches a fab violation before the Gerbers do. Where our own margin
was already stricter than JLC it stays.

| Rule | Value (DRC) | JLCPCB min | Notes |
|---|---|---|---|
| Min track width | 0.25 mm (10 mil) | 0.10 mm (1 oz) / 0.16 mm (2 oz) | Comfort; audio doesn't need tighter |
| Min clearance | 0.20 mm (8 mil) | 0.10 mm | Safe, avoids extra fees |
| Min via drill / diameter | 0.3 / 0.6 mm | 0.3 / 0.45 mm (0.15 mm holes or < 0.45 mm vias cost extra) | No surcharge; classes use 0.4/0.8, 0.8/1.4, 1.0/1.6 |
| Min through-hole drill | 0.3 mm | 0.15 mm | Smallest used: 0.75 mm (TO-92) |
| **Min annular ring (PTH + via)** | **0.18 mm** | **0.18 mm absolute, 0.25 mm recommended** | Errata #23: stock TO-92 (0.15) and the LM1875 footprint (0.175) failed this — fixed (0.35 / 0.20) |
| **Hole-to-hole (different nets)** | **0.5 mm** | 0.45 mm (PTH), 0.2 mm (vias) | was 0.25 |
| **Hole-to-copper** | **0.3 mm** | 0.254 mm | was 0.25 |
| Pad-to-pad (SMD, different nets) | 0.20 mm (class clearance) | 0.15 mm | |
| Board edge clearance | 0.5 mm | 0.2 mm | plus a 2 mm routing keepout frame (`gen_pcb.py`) |
| **Solder-mask dam** | **0.10 mm** | 0.10 mm (green) | |
| Min silkscreen width / text height | 0.15 mm / 1.0 mm | 0.15 mm / 1.0 mm | |
| Copper weight | **1 oz** | — | 2 oz was in the recovered order spec; 1 oz is enough (Part 6c: 2.5 mm / 2.0 mm traces at 1.7 A peak) and cheaper |

### Net classes — recovered verbatim

| Net class | Track width | Clearance | Via drill | Use for |
|---|---|---|---|---|
| Default | 0.30 mm | 0.20 mm | 0.3 mm | All signal traces |
| Power | 1.50 mm | 0.30 mm | 0.5 mm | +33.5V, VREG_IN, +17V, GND power rails |

- **Power class:** +33V5, VREG_IN, +17V, GND (HighCurrent class: SPK_P, SPK_N, PA_OUT)
- **Default class:** everything else

## Wiring pads — recovered verbatim

| Pad | Size | Drill | Silkscreen label |
|-----|---|---|---|
| Signal pads (inputs, pots) | 2.0 mm | 1.2 mm | IN1, VOL_H, VOL_W, … |
| Power pads (transformer, speaker) | 3.0 mm | 1.5 mm | T1_A, T1_CT, T1_B, SPK+, SPK- |
| Ground pad | 3.0 mm | 1.5 mm | GND (star ground) |
| Footswitch pads | 2.0 mm | 1.2 mm | FS_REV, FS_TREM, FS_MRB, FS_GND |

## Ground plane design — recovered verbatim
1. Pour covers the entire bottom layer except pad clearances.
2. Connect to the star ground via multiple vias near C_main.
3. Ground-stitching vias every 15 mm along the perimeter.
4. Do NOT split the ground plane — keep it continuous.
5. Route all signal traces on the TOP layer only.
6. Bottom layer is ground plane only.
7. Use thermal-relief pads (4 spokes) for through-hole ground connections.

In KiCad: Edit → Fill Zones → B.Cu → Net GND; clearance 0.3 mm, min width
0.25 mm, thermal relief gap 0.5 mm, spoke width 0.5 mm.

## Gerber export from KiCad (8/9) — recovered verbatim
1. Run DRC (Inspect → Design Rules Check). Fix all errors.
2. Refill zones (Edit → Fill All Zones, shortcut B).
3. File → Fabrication Outputs → Gerbers (.gbr).
4. Output folder: `JLCPCB`.
5. Layers: F.Cu, B.Cu, F.SilkS, B.SilkS, F.Mask, B.Mask, Edge.Cuts.
6. General options: plot reference designators; check zone fills before plotting.
7. Gerber options: Protel filename extensions; subtract soldermask from silkscreen; coordinate format 4.6 mm.
8. Plot.
9. Generate Drill Files: Excellon; alternate drill mode for oval holes; map = Gerber; origin absolute; mm; decimal zeros. Generate drill + map.
10. Zip the output folder (.gbr + .drl).

Alternative: install the "Fabrication Toolkit" plugin (repo
`https://raw.githubusercontent.com/Bouni/bouni-kicad-repository/main/repository.json`)
to generate JLCPCB-ready zipped Gerbers in one click.

## Pre-order checklist — recovered verbatim
- [ ] DRC passes with zero errors
- [ ] All zones filled
- [ ] Board outline is a closed shape on Edge.Cuts
- [ ] All mounting holes present and correctly sized
- [ ] No copper within 0.5 mm of board edge
- [ ] Correct pad sizes and drills on all footprints
- [ ] Ground plane covers entire bottom layer, no isolated islands
- [ ] All test points and wiring pads labeled on silkscreen
- [ ] Power trace widths 1.5 mm+ (rails), 2.5 mm+ (speaker/power amp)
- [ ] Polarity markers on electrolytics; pin-1 dots on ICs
- [ ] LM1875/LM317 oriented toward the board edge nearest the heatsink
- [ ] Gerber preview on JLCPCB matches your design (every layer)

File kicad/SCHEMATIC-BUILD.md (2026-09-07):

# KiCad schematic — generated hierarchical sheets

## Status: the wired sheets exist and pass ERC
The eight hierarchical `.kicad_sch` sheets and the root are **generated and
committed**, open in KiCad 7/8, and pass a real Electrical Rules Check:

```
kicad-cli sch erc      ->  0 violations            (KiCad 8.0.9)
kicad-cli sch export netlist ->  174 components (146 + 28 test points) · 83 nets · 0 unconnected pins
GND spans 65 nodes · split mid-rails VBIAS_R / VBIAS_T / VBIAS_3 · all inter-sheet signals resolve
```

Files: `cambridge_reverb.kicad_sch` (root) + `power_supply / preamp /
tone_stack / reverb / tremolo / mrb / power_amp / switching .kicad_sch`.
Generator: `gen/gen_kicad.py` (regenerate with `python3 kicad/gen/gen_kicad.py`).

## How they're built
- **Self-contained symbols.** `symbols/cr_primitives.kicad_sym` defines the
  primitives (R, C, CP, L, D, LED, JFET, dual op-amp, LM1875, LM317, bridge,
  pot, jack, speaker, transformer, fuse, PWR_FLAG) with known pin geometry, so
  the project has no dependency on the system libraries. The curated parts
  (`VTL5C1`, `Reverb_Tank_4FB2A1C`, `Footswitch_DIN6`) come from
  `symbols/cambridge_reverb.kicad_sym`.
- **Label-based connectivity.** Each pin gets a short wire stub to a net label —
  `global_label` for rails and cross-sheet signals (`+33V5`, `+17V`, `VREG_IN`,
  `GND`, `SPK_P/N`, `GUITAR_IN`, `PREAMP_OUT`, `TONE_OUT`, `DRY`, `WET`,
  `BLEND`, `TREM_OUT`, `MRB_OUT`, `PA_IN`, `FX_RET`, `FS_*`), `label` for
  intra-sheet nets. This yields a correct netlist without fragile point-to-point
  routing.
- **Descriptive references.** Designators match the BOM/docs/SPICE (`R_fb`,
  `C_out`, `IC_PA`, `Q_rec`, …) for traceability. KiCad's auto-annotator will
  flag these as "not numerically annotated" (they have no trailing number) — that
  is expected and **non-blocking**; the netlist is correct and pin-complete. If
  you want standard refdes for board layout, run Tools → Annotate (it will
  renumber; keep a copy if you want to preserve the doc names).

## Verified
- `kicad-cli 8.0.9 sch erc`: **0 violations** (errors + warnings). Getting there
  required snapping all pins/wires to the 1.27 mm connection grid and giving the
  footswitch lines a real second endpoint (below).
- `kicad-cli` custom symbol library + footprints parse/plot; the hierarchy
  netlists with **0 unconnected pins** and no duplicate references.
- PDF/SVG render of all sheets is correct (title blocks, values, labels).
- ERC does not check reference *annotation* (that's a separate tool), so the
  descriptive non-numeric refs do not produce ERC violations; `export netlist`
  prints an "annotation" notice but exports all 174 components correctly.

## Design additions beyond the recovered notes (clearly marked)
- **Mid-rail `VBIAS`.** Single-supply TL072 stages need their inputs biased to
  ~Vcc/2; the recovered notes omit this. A `VBIAS` divider (R_vb1/R_vb2 + C_vb on
  the Power Supply sheet) feeds the reverb driver and the tremolo LFO; the
  op-amp `+in`/gain-return nets reference `VBIAS` instead of GND. Flagged in the
  sheet notes as a design addition — verify values for your rail.
- **Footswitch control taps.** `FS_REV/FS_TREM/FS_MRB` leave the DIN connector
  and land on their effect sheet through a 100 k control pulldown (R_fs_*). The
  exact pedal switching topology follows the original footswitch; these nets are
  represented as defined control lines so they aren't single-ended.

## Effects chain — redesigned 2026-06-16 (roast R3/R6 resolved)
- **Active wet/dry summer** on the spare **IC1-B** half (inverting summer about
  `VBIAS_R`: dry always on, wet via `POT_REV`, unity each). Output `BLEND` is
  low-Z. Replaces the old broken passive `R_dry_tap`/`R_blend*` mixer.
- **Output buffer** on the spare **IC2-B** half drives `PA_IN` from the post-MRB
  node (replaces the unbuffered `R_painput` 1 M).
- **Split bias:** `VBIAS_R` (reverb) and `VBIAS_T` (tremolo) are independent
  100 k/100 k + 47 µF dividers — no shared reference, so no LFO→reverb bleed.
- **Verified rail-aware** (`spice/tran_reverb_mixer.cir`): mid-rail bias 8.50 V,
  unity sum, ±7 V headroom before clipping. ERC 0.

## Still to finish before a build
- **Tone stack** is *designed* (errata #20): the panel's Bass + Treble pots on a
  passive James network with a TL074 buffer / make-up (`IC3`), a switchable
  gyrator MID CUT (`SW_MID`, line-reverse hole) and the 470 pF chime cap as a
  bright cap — verified in `spice/ac_tonestack.cir` + `sweep_tonestack.cir`. The
  original 25-5274-2 values were never recovered (cross-check §4); if they turn
  up they drop into the same ladder.
- The tremolo's passive LDR shunt + MRB sit *between* the two buffered nodes
  (BLEND→ … →PA_IN); levels there are reasonable but bench-tune the tremolo depth
  and MRB blend.
- **Inter-effect routing order** (reverb→tremolo→MRB→power amp) is a documented
  assumption where the recovered notes are silent; see the note on the root sheet.
- **PCB:** `cambridge_reverb.kicad_pcb` is generated (floor-plan placement,
  `gen/gen_pcb.py`) and autorouted (`gen/route_board.py`) — status, DRC and the
  remaining hand-review in `PCB-NOTES.md`. After annotation you can *Update PCB
  from schematic* or keep the generated board. Fab per `docs/04-jlcpcb-fabrication.md`.

## Per-sheet contents
Values come from Part 2 + `netlist-notes.txt`; see those and `errata.md` for the
authoritative numbers (e.g. preamp `R_s ≈ 1–1.2 k`, `R_reg2 = 3.09 k`).
Power Supply · Preamp · Tone Stack · Reverb · Tremolo · MRB · Power Amp ·
Switching/I-O — one hierarchical sheet each, in signal-flow order.

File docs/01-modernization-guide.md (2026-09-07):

# Vox Cambridge Reverb V1031/V1032 — Part 1: Modernized Rebuild Guide

> Reconstructed document — see `PROVENANCE.md`. Design philosophy and the
> power-amp section are recovered substantially verbatim; some surrounding prose
> is `[RECONSTRUCTED]` to keep the guide coherent.

## Original amp summary

| Parameter | Original spec |
|---|---|
| Model | V1031 (1966), V1032 (1967, adds E-Tuner) |
| Power | 18 W RMS into 8 Ω |
| Topology | Single-channel, 3 inputs, OTL output |
| Output devices | Matched germanium PNP pair (NTE-121MP equivalent) |
| Driver | 2N2219 silicon NPN in TO-3, through driver transformer (T2) |
| Preamp | Discrete bipolar transistors on PCB 25-5274-2 |
| Power supply | 33.5 VDC main, taps at 27 V and 17 V; full-wave rectifier, center-tapped transformer |
| Effects | Reverb (2-spring pan), Tremolo, MRB (~600 Hz mid boost) |
| Speaker | 10" Oxford "Gold Bulldog" alnico |
| Footswitch | 3-button: Reverb, Tremolo, MRB |

## Modernization philosophy

The goal is to preserve the original signal-path topology and tonal character
while replacing every component with modern, reliable, higher-performance parts.
All improvements are internal only — the original front and rear panels are
preserved exactly, with no new holes drilled.

Key improvements over the original:
- LM317-regulated 17 V preamp rail (the single biggest noise reduction over the original)
- Continuous bottom-layer ground plane (the original board had none)
- Elimination of the germanium output stage and both audio transformers (driver T2, reverb T3)
- Internal effects-loop provision (via IN3 jack repurposing)
- On-board tremolo rate LED (diagnostic, not panel-mounted)

## Section 1: Power supply — modernized

KBP410G bridge rectifier feeding the 33.5 V main rail; an **RC pre-filter**
(`R_27V` 100 Ω + `C_filt1` 1000 µF, net `VREG_IN`) feeds the LM317 input; the
17 V preamp rail is regulated by an LM317T. Rectifier snubbing caps across the
diodes. The LM317 on the 17 V rail is the most impactful single change for noise,
and the `VREG_IN` pre-filter compounds it — it both attenuates main-rail ripple
before the regulator and **decouples the preamp supply from the power amp's
transient current draw** on the +33.5 V rail. (Note: under the modern light
preamp load (~15 mA) `VREG_IN` sits at ~32 V — it is a pre-filter, **not** the
original 27 V tap. Full values in Part 2.)

## Section 2: Preamp — modernized

JFET common-source stages replace the original discrete bipolar preamp. JFETs
clip softly (tube-like), present very high input impedance for guitar pickups,
and self-bias easily. The Vox voicing comes from the tone stack: the panel's
**Bass and Treble** pots drive a **passive James network** (the Thomas-Vox
topology — asymmetric, more cut than boost, slightly bright at noon) buffered
by a TL074 (`IC3`), with the 470 pF "chime" cap as a bright cap across the
volume pot. New in this design: a **MID CUT toggle** (−9.6 dB, ~800 Hz, broad)
in the original line-reverse switch hole, for honky-sounding pickups — off, the
chain is flat. Errata #20 has the values and the SPICE sweeps.

**JFET device:** the through-hole 2N5457 is **discontinued** (see Part 8). Use
the **MMBF5457** (SOT-23, exact same die) on a SOT-23→TO-92 adapter, or the
through-hole **J113** with adjusted bias. The bias values throughout these
documents target 2N5457 specs (Vp ≈ -1.8 V, Idss ≈ 3 mA) and work directly with
the MMBF5457.

## Section 3: Power amplifier — modernized

### Original circuit
Driver transistor Q7 (2N2219 silicon NPN) → driver transformer T2 (phase
splitter) → 2× germanium PNP output transistors in push-pull OTL configuration.

### Modernized design
**Eliminate the driver transformer entirely.** The selected design uses a
monolithic power amplifier IC.

**LM1875 implementation (the design used throughout this document set):**
```
Pin 1 (Non-inv input) ← from preamp/reverb blend through 1µF coupling cap
  Input biased to V+/2 through resistor divider (2× 22kΩ)
Pin 2 (Inv input) ← feedback network
  R_feedback = 22kΩ (from output to pin 2)
  R_ground = 1kΩ (from pin 2 to ground through 22µF cap)
  Gain = 1 + 22k/1k = ~23x (adjustable)
Pin 3: V- (ground in single-supply)
Pin 4: Output → 2200µF/35V coupling cap → speaker
Pin 5: V+ (connect to +33.5V main rail)

Zobel: 10Ω + 100nF across output to ground
Bypass: 100nF + 10µF on each supply pin to ground
```
The IC includes thermal shutdown, short-circuit protection, and SOA limiting.
Mount it on the existing heatsink bracket under the chassis where the germanium
transistors were.

> **Power ceiling (roast R2):** on a single **33.5 V** rail the LM1875 can only
> swing ~16.75 V peak to the rail, so the maximum into 8 Ω is **~12 W clean
> (~14 W at clipping), an absolute ceiling of 17.5 W — it will not reach the
> original 18 W** (that needs 17.0 V peak). This is ~1.8 dB down, still plenty for
> a 10″ combo. If full 18 W is required it needs a different topology (bridged
> LM1875, or LM3886/TDA7293 on a higher rail). Thermal/transformer sizing below is
> based on the real ~12 W, not 18 W.

> **Note on alternatives:** A discrete TIP41C/TIP42C complementary output stage
> was mentioned during design as a reference alternative for "vintage" breakup,
> but it is **not** carried through the rest of the document set (no BOM, SPICE,
> or wiring). All Parts 2–10 are built around the LM1875. Treat the discrete
> output as a separate development effort not covered here. (Errata Issue 5.)

## Section 4: Reverb — modernized

A TL072 op-amp drives the reverb pan directly; the original reverb transformer
T3 is eliminated. A JFET recovery amp provides the high input impedance for the
return. The pan must be the high-impedance **Accutronics 4FB2A1C (~1475 Ω input)**
— the 8 Ω-input 4AB3C1B is incompatible with the direct TL072 driver. (Detail
in Part 2 / Part 9.)

## Section 5: Tremolo — modernized

A Wien-bridge LFO (TL072 half) drives an LED/LDR optocoupler (**Xvive VTL5C1**
or DIY LED+LDR; original Perkin-Elmer vactrols are discontinued under RoHS
cadmium restrictions). The LFO output also drives an on-board diagnostic rate
LED. Speed and depth pots use the original panel positions — the speed pot is a
**dual-gang 250 k linear** in the original hole (errata #19: a single-arm Wien pot cannot
span tremolo rates); the LFO runs 0.6–10.6 Hz (`spice/sweep_lfo_speed.cir`).

## Section 6: MRB (Mid Resonance Boost)

A parallel LC tank using the original-style inductor. Default is **hardwired at
600 Hz** (original spec); the line-reverse switch hole is **now used by the tone
stack's MID CUT toggle** (errata #20), so a multi-frequency MRB selector would have
to be internal-only — no new panel holes. (Errata Issue 8.)

## Section 7: Added features (internal only)

- **Effects loop:** internal-only provision via IN3 jack repurposing; switching
  jacks normal the dry path when nothing is inserted.
- **Tremolo rate LED:** on-board diagnostic, not panel-mounted.
- Headphone output described in early drafts was **removed** (would require a
  new panel hole). (Errata Issues 1–2.)

## Safety

- **Fit a MAINS (primary) fuse (roast R1).** The design's only fuse (F1) is on the
  secondary DC rail, which does **not** protect against a primary/transformer/
  bridge fault. Add a primary-side fuse in the IEC inlet — **T800 mA 250 V slow-blow
  at 120 V (≈ T400 mA at 230 V)** for the ~50 VA transformer. This is a fire-safety
  requirement, not optional.
- **Always discharge filter capacitors** before working on the circuit (10 kΩ/5 W resistor across each cap).
- **Never work on the amp with power applied** unless experienced with live-chassis work and using one hand only.
- **Install a proper 3-wire grounded power cord** if the original was 2-prong; bond the safety ground to the chassis.
- A ground-lift, if used for hum, must keep the chassis grounded through a 100 nF/400 V safety capacitor.

## Appendix: schematic resources
- Original V1031 schematic: schematicheaven.net (free PDF)
- GeoFEX repair-board documentation: geofex.com
- Vox Showroom: voxshowroom.com (under-the-hood photos)
- Reverb.com schematic package: high-resolution factory scans

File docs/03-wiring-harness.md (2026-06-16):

# Vox Cambridge Reverb — Part 3: Wiring Harness & Troubleshooting

> Reconstructed document — see `PROVENANCE.md`. The troubleshooting tables, wire
> routing, and grounding rules are recovered substantially verbatim.

## Wire routing path — recovered verbatim
```
    CONTROL PANEL (above)
         |
    +----+----------------------------+
    |   wires run through gap          |
    |   between panel and chassis      |
    +----------------------------------+
    |          PCB (in chassis)        |
    |      WIRING PADS                 |
    +----------------------------------+
    |   wires to heatsink/xfmr         |
    |   run below chassis pan          |
    +----------------------------------+
         |
    HEATSINK + TRANSFORMER (below)

All signal wires (shielded) route along the LEFT side of the chassis.
All power wires (heavy gauge) route along the RIGHT side.
Physical separation minimizes magnetic coupling between supply currents
and sensitive audio signals.
```

## Footswitch (6-pin DIN)
The original 6-pin DIN footswitch connector and pedal are retained. Footswitch
pads on the PCB: FS_REV, FS_TREM, FS_MRB, FS_GND.

## Troubleshooting — no sound at all (recovered verbatim)

| Check | Expected | If wrong |
|---|---|---|
| AC at T1 primary | 120 VAC | Check power cord, fuse, power switch |
| AC at T1 secondary | ~48 VAC (or ~24 VAC) | Transformer is dead — replace |
| DC at C_main (+) | 33–35 VDC | Check bridge rectifier, fuse F1 |
| DC at 17V rail | 17.0–17.5 V | Check LM317, R_reg1, R_reg2 |
| DC at LM317 input (VREG_IN) | ~31–33 V | Check R_27V (100Ω) + C_filt1 pre-filter |
| DC at LM1875 pin 5 | ~33.5 V | Check wiring to V+ rail |
| DC at LM1875 pin 4 | ~16–17 V (V+/2) | IC may be bad or oscillating |
| Signal at Q1 gate | Guitar signal present | Check input jack, C1, R1 |
| Signal at Q1 drain | Amplified signal | Check JFET biasing (Vd = 8–9V) |

## Troubleshooting — hum or buzz (recovered verbatim)

| Symptom | Likely cause | Fix |
|---|---|-----|
| 60 Hz hum (steady) | Ground loop or missing ground | Check star ground, all ground returns |
| 120 Hz buzz (harsh) | Rectifier noise or failed filter cap | Check snubbing caps C101–104, test C_main |
| Hum varies with volume | Preamp picking up noise | Shield input wiring, check preamp ground |
| Hum only with reverb on | Reverb pan cable unshielded | Use shielded cable for pan connections |
| Buzz with tremolo on | LFO coupling into audio path | Separate LFO wiring from signal wiring |

## Troubleshooting — oscillation (recovered verbatim)

| Symptom | Likely cause | Fix |
|---|---|-----|
| High-frequency squeal | LM1875 oscillating | Check Zobel network, add 50pF cap across input |
| Low-frequency motorboating | Power supply feedback | Check all bypass caps, verify star ground |

## Star grounding
Single star-ground point located near C_main, connected to chassis. All ground
returns land at the star. The continuous bottom-layer ground plane ties to the
star via multiple vias near C_main (see Part 4).

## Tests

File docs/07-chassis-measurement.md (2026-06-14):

# Vox Cambridge Reverb — Part 7: Chassis Measurement & PCB Sizing

> Reconstructed document — see `PROVENANCE.md`. The "safe approach" summary is
> recovered substantially verbatim.

## The safe approach (recovered verbatim)
1. **Measure first, design second.** Don't assume any dimensions.
2. **Subtract 15 mm from each dimension** for guaranteed clearance.
3. **155 × 90 mm is the "safe bet"** if you can't measure yet — it will fit.
4. **Check vertical clearance** for the tallest component (main filter cap).
5. **Use nylon standoffs** for clean, insulated mounting.
6. **All wiring on one edge** so the board can flip up for service.
7. **Photograph everything** before, during, and after.

## Why no published dimension
No published dimensions exist for this chassis — every surviving amp differs
slightly from 1960s stamped-steel manufacturing. Measure your specific chassis
and fill in a measurement table before finalizing the Edge.Cuts outline.

## The main-filter-cap gotcha
The original ~5000µF cap was mounted vertically on the chassis pan, not the PCB.
If you want it on the PCB, measure clearance to the control panel above. If
tight, split into 2× 2200µF side by side or use a horizontal-mount cap.

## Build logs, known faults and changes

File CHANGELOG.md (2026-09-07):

# Changelog

All notable design work on this project. Parts correspond to the structured
deliverables produced during the design phase.

### Noise, hum, crosstalk and thermal models; JLCPCB rules and cost (2026-09-07)
- **New models (Part 6c, `spice/`):** `.noise` of the whole front end with the
  regulator's own noise; rail-ripple paths to the speaker; a vactrol-level tremolo
  depth model; an electro-thermal LM1875 ladder; and `kicad/gen/crosstalk_audit.py`,
  a geometric crosstalk screen of the routed boards. Three design defects fell out:
- 🔴 **Errata #21 — hum and hiss.** The LM1875's input bias divider had no bypass
  (+4 dB ripple → speaker: **0.4 Vrms of 100 Hz at idle**), and the LM317's 0.5 mV of
  noise reached the 0 dB-PSRR JFET stages (**23 dB above** their own floor, SNR 34 dB
  at 12 W). Fixed: `C_bref` 100 µF + `R_bias3` 22 k on the power amp; `C_adj` 10 µF
  on the LM317; `R_pre` 100 Ω + `C_pre` 220 µF `+17V_PRE` rail for Q1/Q2/Q_rec.
  Hum 408 mV → 0.3 mV, EIN 37 → 2.7 µV, SNR 34 → 57 dB.
- 🔴 **Errata #22 — the tremolo had 1.7 dB of depth.** The vactrol LED was returned to
  ground from a mid-rail LFO: 7 mA DC, a permanent −20 dB pad. Fixed: LED limiter
  (2 V LFO swing; `LED_rate` is one limiter LED and now blinks) + `Q_trem` 2N3904 /
  MMBT3904 emitter follower, AC-coupled from the depth pot → **15 dB depth**, 0.8 dB
  insertion loss. `D_lfo1/2`, `R_led`, `R_led_diag` removed.
- **Crosstalk → routing rules.** Reverb drive ran 11 mm beside the reverb return
  (−37 dB) and PA_OUT 0.25 mm from the recovery gate (SMD). `cambridge_reverb.kicad_dru`
  now enforces HighCurrent 0.6 mm / TankDrive 1.2 mm from signal copper (tracks and
  vias; 1.0 / 2.0 mm left 14–27 links unroutable), and `route_board.py` hands the
  router the same numbers as class clearances;
  keepout rule areas keep it 2 mm off the edge and away from the mounting holes.
- **Thermal.** Part 5's ≤ 2.5 K/W heatsink confirmed with numbers (Tj 97 °C at 40 °C
  ambient under a worst-case continuous sine; 4 K/W still fine; 8–10 K/W clip-ons reach
  shutdown); a 40 g sink saturates in ~5 min. LM317 0.4–0.5 W bare, bridge 1.2 W,
  25 VA transformer adequate for music.
- ⚠️ **Errata #23 — JLCPCB.** Both `.kicad_pro` files now carry JLC's 2-layer limits as
  DRC constraints; the stock TO-92 (0.15 mm ring) and LM1875 (0.175 mm) footprints were
  under the 0.18 mm minimum → `TO-92_Inline_Wide` (also the adapter pitch) and 1.5 mm
  LM1875 pads. Assembly cost: all SMD caps 1206 (basic library), "(opt)" MRB caps DNP,
  gyrator on E24 values (2.2 nF / 180 k, same 1.86 H): 7 → 2 extended part types,
  ≈ $32 → $17 for five assembled boards (`kicad/gen/jlc_cost.py`); three fiducials.
- **Placer:** short parts now **stack** beside tall ones in a shelf (a DIP or can no
  longer wastes 20 mm under every resistor next to it) and the overflow repair moves
  width only where the donor still fits — both boards took the eight new parts with room
  to spare (THT tone column at 74 % height).
- **Boards regenerated and re-routed with the new rules:** THT **215/222 routed, 1
  starved thermal, 0 rule hits** (×7 / via 60); SMD **210/223, 4 starved thermals, 0
  rule hits** (×6 / via 80 with 0.4 / 0.8 mm class clearances — a plain routing gets 9
  open but breaks the rules 47 times). Fourteen settings per board; the open links are
  listed in `kicad/PCB-NOTES.md`. Lesson recorded there: DRC a candidate *in place* —
  a copy in another directory is checked without the net classes and the `.kicad_dru`.
  Post-routing crosstalk: THT worst pair −50 dB (was −37), SMD −42 dB
  (`kicad/reports/crosstalk-*.md`).

### Bass / Treble tone stack + switchable MID CUT (2026-09-07)
- 🔴 **Errata #20 — tone.** Two findings: the recovered coupling from Q2's drain
  to the volume pot was the **470 pF chime cap alone** (a 1.3 kHz high-pass — no
  bass reached the rest of the amp), and the designed "Tone" substitute was a
  single treble-cut pot while the Cambridge Reverb's panel has **Bass and Treble**.
  **Built design:** `C_cpl_out` 1 µF full-band coupling; a **passive James
  (Thomas-Vox) Bass/Treble network** — the originals' topology, asymmetric, more
  cut than boost, kept on purpose over a hi-fi active Baxandall so the amp keeps
  its character — driven by a TL074 (`IC3`: input buffer, ×2 make-up, gyrator,
  output buffer, own mid-rail `VBIAS_3`), both pots 250 k lin in the original
  holes; `C_treble` 470 pF becomes a bright cap across the volume pot.
- **New: MID CUT toggle** for honky pickups — `R_mid` 10 k + a switched
  series-resonant gyrator shunt (1.86 H simulated + 22 nF): **−9.6 dB at ~800 Hz,
  Q ≈ 0.6**, flat when off, no DC across the switch (no pop). `SW_MID` sits in the
  **original line-reverse switch hole** — still no new panel holes.
- **SPICE:** `ac_tonestack.cir` rewritten rail-aware (every IC3 node 8.50 V, noon
  −0.21 dB flat, mid cut −9.65 dB @ 796 Hz); `sweep_tonestack.cir` sweeps both
  pots and the switch (bass −7.5 … +4.9 dB @ 100 Hz, treble −16.5 … +5.6 dB @
  10 kHz). Results in `spice/results/`.
- **Generator / placer:** `OPAMP14` (TL074 DIP-14) and `SW_SPST` symbols;
  `VB_3` / `TMK` test points (28 in total); the tone zone grew by 22 parts, so
  the THT profile packs at a 1.2 mm gap / 3.5 mm channels (SMD 0.4 mm) and the
  placer now **repairs column overflow** by moving width from the slackest
  column. Small parts (axials, discs, chips) keep their **schematic order** on
  the shelves instead of tallest-first, so netlist neighbours stay board
  neighbours in the dense tone zone; the tone/preamp column gets a width weight.
  On the 155 × 90 SMD board the 13 wiring-edge groups no longer fit in one row,
  so the three input-jack pad groups run down the **left edge** next to the
  preamp. **Keepout rule areas** (2 mm edge frame + squares round the M3 holes)
  are exported to the router, which otherwise happily ran 45 mm of trace along
  the board edge and under a hole. `route_board.py` refuses a board without its
  `.kicad_pro` (a copy routed without the project's net classes came back with
  0.2 mm tracks and 400 DRC errors) and prunes the zero-length segments the SES
  import leaves.
- **BOM:** `IC3` TL074CN + DIP-14 socket, `POT_BASS` / `POT_TREB` (reused panel
  pots), `SW_MID`; 138 components + 28 test points; 90 SMD parts on the variant.
- **Boards regenerated and re-routed** (a dozen router settings each): **THT
  208/212 routed, DRC clean** (was 167/168 + 3 starved thermals on the previous
  placement); **SMD 207/213 routed, 4 starved thermals** (was 162/169 clean).
  The four / six open links are listed in `kicad/PCB-NOTES.md`. The counts move
  with every placement change; `kicad/reports/` holds the evidence.

### SPICE parameter sweeps, committed results, tremolo LFO fix (2026-09-07)
- **Six ngspice sweeps** added next to the fixed-point checks, and `run_all.sh`
  now writes every result table to **`spice/results/`** (committed evidence):
  JFET drain voltage vs `R_s` across the datasheet Idss/Vp spread (the recovered
  2.2 k suits a *high*-Idss part; a typical one wants ~1.0 k; a 1 mA part cannot
  reach 8–9 V — errata #15 quantified), tone-pot travel, LFO rate vs speed pot,
  Class-A bias vs standing heat / THD, power-amp clean power vs mains ±10 %
  (8.9 / 11.7 / 14.8 W).
- 🔴 **Errata #19 — the tremolo LFO did not work as recovered.** Sweeping the
  recovered single-arm Wien network showed it oscillates only for the bottom ~5 %
  of the speed pot, at 45–80 Hz, and not at all elsewhere. **Fixed:** symmetric
  network with a **dual-gang 250 k speed pot** (one gang per arm, same panel
  hole), 15 k floors, 1 µF timing caps → **10.6 Hz … 0.60 Hz** at constant
  amplitude (`sweep_lfo_speed.cir`; the pre-fix network is kept as
  `sweep_lfo_speed_recovered.cir`). `POT_SPD_A`/`POT_SPD_B` are the two gangs of
  one new part; the original speed pot is no longer reused.
- Both boards regenerated and re-routed for the new tremolo parts (six router
  settings each): **THT 167/168 routed, 3 starved-thermal errors** (was 166/166
  clean on the previous placement); **SMD 162/169 routed, DRC clean** (was 165/167
  + 1 error). The open links are listed in `kicad/PCB-NOTES.md`; the counts move
  with every placement change — `kicad/reports/` holds the evidence.

### Mixed SMD/THT variant + JFET pin-number fix (2026-09-06)
- 🔴 **Errata #18 — JFET pins.** The generated JFET symbol had 2 = Gate / 3 = Source;
  the onsemi 2N5457 (TO-92) and MMBF5457 (SOT-23) datasheets both number the leads
  **1 D / 2 S / 3 G**, so the THT board would have swapped gate and source on Q1,
  Q2 and Q_rec. Symbol renumbered, both boards regenerated. Caught while adding
  the SOT-23 footprint.
- **Build profiles.** `gen_kicad.py`, `gen_pcb.py` and `gen_bom.py` take
  `--profile tht|smd`: one schematic source, two footprint maps and board
  parameter sets. `tht` is unchanged (`kicad/`, 190×115). **`smd` writes a
  self-contained project to `kicad/smd/`** (`cambridge_reverb_smd.*`, lib tables
  pointing one level up) sized **155×90 mm** — the Part 7 safe-bet chassis.
- **What goes SMD (70 parts):** 0805 resistors (1206 for `R_reg2`), 1206 caps
  ≤ 100 nF (C0G in the signal path), 1210 for the 120 nF / 1 µF / `C_zobel`,
  SMA + SOD-123 diodes, SOT-23 JFETs fitted directly. **Deliberately THT:** power
  parts, all electrolytics (a standing can uses less board than an SMD can — the
  area check showed converting them *loses* 380 mm²), DIP-8 sockets for the
  TL072s, the three bench-trimmed source resistors, LED, connectors, test points.
  Parts area 4 560 mm² → 48 % of the 155×90 usable area (THT 60 %).
- **THT board re-routed** after the pin fix (and a column-balance fix: the
  power-amp width weight was starving the effects column): **166/166 connections,
  0 DRC violations, 66 vias** — fully routed for the first time.
- **SMD-profile placement:** 6 mm margin, 0.6 mm part gap, 3 mm channels, pad row
  kept clear of the corner holes; pre-route DRC 0 errors. Routed with a **GND pour on both layers** (top
  pour solid to the SMD ground pads only; the router is shown just the bottom plane
  so it drops a via per SMD ground pad — with both planes visible it left 20 ground
  pads on islands) and **2.0 / 1.0 mm HighCurrent / Power classes** for this board
  (errata #11 addendum; the THT 2.5 / 1.5 mm traces starved the router to 9–11 open
  links). **Committed SMD board: 165/167 routed, 1 DRC error (starved thermal),
  109 vias**; the two open items are documented as GUI touches.
- `bom/bom-smd*.csv` with spec notes (no invented part numbers) and
  `production/smd/bom-jlcpcb.csv` + position file for JLCPCB assembly of the SMD side.
- **Datasheets committed** (`datasheets/`, 13 PDFs, ~15 MB) with a manifest
  (`SOURCES.md`: source URL, revision, SHA-256 prefix, and which footprint / pin
  number / design value each sheet backs). Reverses the earlier "not committed"
  policy — errata #18 is exactly the kind of error only the drawing catches.
- **Verification tooling in the repo:** `kicad/gen/check.sh tht|smd [--no-regen]`
  regenerates a profile and writes ERC/DRC reports to `kicad/reports/`; the
  committed reports are the evidence for the numbers in `PCB-NOTES.md`.

### Footprint fixes, floor-plan placement, headless autoroute (2026-09-06)
- **PCB-AUDIT §1 defects fixed with datasheet-derived project footprints:**
  `TO-220-5_Vertical_P1.70mm_LM1875` (TI NDH0005D inline TO-220-5; 1.1 mm drill,
  **1.45 mm pads → 0.175 mm annular**, was 0.0875 → the 5 `annular_width` DRC
  errors are gone) and `Bridge_KBP_P3.81mm` (Diodes DS39310 KBP404G–KBP410G:
  3.81 mm pitch, 1.2 mm drill, pins **+ ~ ~ −**; replaces the `PinHeader_1x04`
  placeholder). The schematic bridge symbol is renumbered to the KBP physical
  order (1=+ 2=~ 3=~ 4=−). One footprint cannot also take a KBU (5.08 mm pitch) —
  errata #3 updated with the swap procedure.
- **Value-aware footprint sizing** (`gen_kicad.footprint_for`): 4700 µF → D18 P7.5,
  2200 µF → D16 P7.5, 1000 µF → D12.5 P5, 47 µF → D6.3, ≤22 µF → D5 (tantalums on
  2.5 mm); 5 W `R_bleed` → 20 mm power axial, 1 W `R_27V` → DIN0414; the 0 Ω
  speaker-return link `R_spk_rtn` gets 1 W-size pads (it carries the speaker
  current). The old board had every can as D8 and every resistor as ¼ W.
- **`gen_pcb.py` now places to the Part 5 floor plan**: five zones left→right
  (Input/Preamp | Tone | Reverb/Trem+MRB | Power Amp | PSU), widths auto-balanced
  so the columns pack to equal height, signal-chain order inside each zone;
  LM1875/LM317 on the top edge with the 10 mm keep-out; every off-board connector
  on the bottom wiring edge under its zone, `T1` far right; 4 × M3 mounting holes.
  **DRC before routing: 0 errors, 0 warnings** (was 9 errors + ~155 silk warnings).
- **Chassis-fit figure corrected:** the earlier 48–53 % / 82–90 % packing densities
  summed bounding boxes *including hidden text*. Text-less: **~33 % on 190×115,
  ~56 % on 155×90** — the "safe-bet" board is dense but no longer "not buildable"
  (errata #9 still says measure first). Old `unconnected` counts (131) were also
  from the 102-part board; the board is 113 parts / 145 connections now.
- **Bench test points (26).** One-pin `TP_*` symbols on each sheet (in the netlist
  and BOM — one order line), project footprint `TestPoint_THT_D2.0mm_Label`
  (2.0 mm pad / 1.0 mm drill for a header pin or wire loop) whose *value* prints
  the net alias on the silkscreen. `gen_pcb.py` lays them in a strip across the
  top of every zone with a GND pin per zone for the probe clip. Coverage follows
  the Part 5 bring-up order: `VRAW`/`+33V5`/`VREG`/`+17V`, JFET drains `Q1D`/`Q2D`/
  `QRD` (the errata #15 trim), `VB_R`/`VB_T`, `PRE`/`TONE`/`BLEND`/`TREM`/`MRB`/
  `PA_IN`, `TK_IN`/`TK_OUT`, `LFO`, `PA_B`/`PA_OUT`/`SPK`. Expected values are
  tabulated in `kicad/PCB-NOTES.md`.
- `datasheets/SOURCES.md` records the package drawings used; Part 10 / kicad README
  list the new footprints.
- **Wiring edge per Part 4:** the off-board connectors are now project *wire pad*
  footprints (`WirePad_1x0N_P2.54mm_D1.2mm`: 2.0 mm pads / 1.2 mm drill for jacks,
  pots, tank, DIN; `WirePad_1x0N_P5.08mm_D1.5mm`: 3.0 mm pads / 1.5 mm drill for
  the speaker and transformer) instead of 2.54 mm pin headers.
- **Net classes:** `VRAW`, `AC1`, `AC2` (bridge/transformer, full supply current)
  moved from Default 0.5 mm to **HighCurrent** (errata #11 updated).
- **Headless autoroute** — `kicad/gen/route_board.py`: pcbnew DSN export → Freerouting
  → SES import → pour refill. Findings: Freerouting **2.1.0** ignores every pass /
  timeout limit in CLI mode and only writes output at 0 unrouted (and its
  multi-threaded router crashed), so the script drives **1.9.0** under `xvfb-run`
  (honours `-mp`, always writes the SES). The script injects Freerouting's
  `autoroute_settings` into the DSN to make the bottom layer 6× more expensive
  than the top, because a free two-layer run put ~2.4 m of copper on the bottom
  and sliced the GND pour into islands (10–11 GND pads unconnected). The
  LM1875's 1.70 mm pin pitch cannot take a 1.5/2.5 mm trace past its neighbours,
  so `gen_pcb.py` pre-routes two **locked 0.9 mm escape stubs** (pins 4/5) that
  export as fixed wires. Placement was tuned for
  routability along the way (Tone stacked under Preamp, reverb block at the bottom
  of its column next to the tank pads, VBIAS dividers and footswitch pull-downs
  next to their loads, serpentine shelf rows so wrapped rows stay adjacent, a
  wider power-amp column). Before the test points the flow reached 144/145
  routed with 0 DRC violations (one `PA_OUT` link blocked by `R_bias1`).
  **Committed board (with the 26 test points): 161/166 connections routed, 0 DRC
  violations (`--severity-all`), 54 vias**; the five open links are listed in
  `PCB-NOTES.md` as a GUI finish.

### Class-A power-amp variant (2026-06-16)
- Explored running the power amp in **Class A** (AC15-style). Sim
  (`spice/tran_classa_output.cir`): Class A drops crossover THD from ~1.05% to
  ~0.0025% -- the cost is ~16W continuous heat for ~1W of pure Class A (slides to
  AB beyond), documented in `docs/classA-power-amp.md`.
- Built it as a **variant alongside the AB amp** (user choice): standalone
  ERC-clean `kicad/power_amp_classa.kicad_sch` (gen_classa.py) = the LM1875 stage
  + an LM317 constant-current sink (R_set 2.5R -> 0.5A from output to GND) =>
  single-ended Class A up to ~1W. Main board stays Class AB. Adds a 2nd LM317 +
  R_set + bigger heatsinks; ERC 0.

## Design deliverables

- **Part 1 — Modernization Guide:** all circuit sections, safety.
- **Part 2 — Full BOM:** Mouser/Digikey part numbers, ASCII schematics.
- **Part 3 — Wiring harness:** color codes, star grounding, footswitch DIN pinout, troubleshooting tables.
- **Part 4 — JLCPCB fabrication guide:** KiCad design rules, Gerber export, silkscreen layout.
- **Part 5 — Thermal & placement:** thermal calcs, component placement floor plan, assembly drawings (LM1875 requires ≤2.5 °C/W heatsink; original bracket suitable).
- **Part 6B — SPICE simulations:** guitar-optimized LTspice sims for all six circuit blocks (supersedes original Part 6).
- **Part 7 — Chassis measurement:** measurement procedure and PCB sizing strategy.
- **Part 8 — Verified BOM:** in-stock status, alternatives for discontinued parts.
- **Part 9 — Transformers & magnetics:** T1 testing, AnTek AS-0524 toroidal T1 option, reverb pan impedance matching, MRB inductor substitution (Fasel wah inductors).
- **Part 10 — KiCad project files:** .kicad_pro, .kicad_sch with 8 hierarchical sheets, custom symbol library (VTL5C1/reverb tank/6-pin DIN), custom footprint library (VTL5C1/1H toroid/35-pad wiring edge array).

## Errata
Identified and resolved 17 cross-document inconsistencies. Three high-priority
issues flagged: discontinued JFET part numbers, output coupling cap, and related items.

## Unreleased
- Initial git repository structure created.
- Reconstructed Parts 1-10 + errata into docs/ from recovered conversation
  content (see docs/PROVENANCE.md for method and verification notes).
- Added bom/bom.csv, spice/power_amp_lm1875.cir, kicad/netlist-notes.txt.

### Consistency pass & build-out (2026-06-14)
- **Errata Issues 9–17 resolved** (docs/errata.md): board-dimension decision
  point, LM317 17 V set-resistor correction (R_reg2 3.0k→3.09k for 17.0–17.5 V),
  missing HighCurrent net class, via-drill/trace-width reconciliation, reverb-pan
  and JFET-bias consistency confirmations, filter-cap and bypass wording.
- **BOM cross-check** (bom/cross-check.md): added the missing preamp, reverb,
  tremolo, MRB, panel-pot, FX-loop, and mechanical/safety rows to bom/bom.csv
  (values from Part 2 + netlist-notes); flagged SPICE simplifications and the
  unrecovered tone-stack values.
- **KiCad project re-authored** (kicad/): cambridge_reverb.kicad_pro (3 net
  classes), custom symbol library (VTL5C1, reverb tank, DIN-6), custom
  footprints (VTL5C1, 1H toroid, 35-pad wiring edge array), library tables, and
  SCHEMATIC-BUILD.md.
- **Reference content** added to empty dirs: datasheets/SOURCES.md,
  photos/CAPTURE-CHECKLIST.md, production/CHECKLIST.md.

### SPICE verification + validated EDA files (2026-06-14)
- **KiCad files validated** with kicad-cli 7.0.11: custom symbol library and
  footprints parse and plot cleanly; .kicad_pro is valid JSON.
- **ngspice block sims added** (spice/): ac_power_amp_lm1875.cir (with C_fb_hf +
  10" speaker model), ac_reverb_driver.cir, ac_mrb.cir, dc_preamp_jfet.cir,
  tran_tremolo_lfo.cir, shared models/ (opamp1p.sub, jfet_2n5457.lib), run_all.sh.
  All run under ngspice-42 and reproduce the documented gains/frequencies.
- **Two findings from running the sims** (folded into errata #15 + cross-check):
  power-amp LF −3 dB is ~17 Hz (input pole, not just C_gain); preamp Rs 2.2 kΩ
  biases the drain cold at ~12 V — Rs ≈ 1–1.2 kΩ hits the 8–9 V target.

### Generated hierarchical schematic (2026-06-14)
- **Wired KiCad schematic generated** (kicad/): root + 8 hierarchical sheets
  (power_supply, preamp, tone_stack, reverb, tremolo, mrb, power_amp, switching)
  via kicad/gen/gen_kicad.py, plus a self-contained primitive symbol library
  (symbols/cr_primitives.kicad_sym).
- **Verified with kicad-cli 7.0.11:** the hierarchy netlists to 94 components,
  56 nets (grew to 102/58 with the VBIAS + footswitch-pulldown additions below),
  **0 unconnected pins**, no duplicate references; GND spans 55 nodes;
  all inter-sheet signals resolve. PDF/SVG of all sheets render correctly.
- Connectivity uses global labels (rails/cross-sheet) + local labels; references
  are descriptive to match the BOM/docs.

### Schematic passes ERC (2026-06-14)
- Installed KiCad 8.0.9 (PPA) and ran a real `kicad-cli sch erc`: **0 violations**.
  Fixes: snapped all pins/wires to the 1.27 mm connection grid (was 338 off-grid),
  and gave the footswitch lines (FS_REV/TREM/MRB) a real second endpoint via
  100 k control pulldowns on the effect sheets.
- Added a mid-rail **VBIAS** network (divider on the Power Supply sheet) and
  referenced the TL072 reverb/tremolo stages to it, so the single-supply op-amp
  stages are electrically real (design addition, flagged in the sheets).
- Schematic now 102 components, 58 nets, 0 unconnected, VBIAS spans 10 nodes.
  Remaining to-finish: tone-stack values (TBD) and inter-effect routing order.

### Auto-placed PCB (2026-06-14)
- **Board generated** (kicad/cambridge_reverb.kicad_pcb) via kicad/gen/gen_pcb.py
  using the KiCad 8 pcbnew API: all 102 footprints assigned + placed, 58 nets
  with pads assigned (ratsnest matches schematic), 190×115 mm Edge.Cuts outline,
  bottom-layer GND pour. Footprints carry into the schematic (Footprint field).
- **Placed, not routed.** kicad-cli pcb drc: the report is dominated by 130
  unconnected (unrouted signal nets — GND is poured) plus cosmetic silk/courtyard
  overlaps from dense auto-placement; the netlist itself is correct. See
  kicad/PCB-NOTES.md for the DRC breakdown and remaining hand-work (placement,
  routing, DRC-to-zero, Gerbers).
- Switched the schematic resistor footprint to the compact vertical variant.

### Power-section routing demo + chassis-fit check (2026-06-14)
- **Routed power demo** (kicad/power_section_demo.kicad_pcb): the +33V5 (2.5 mm
  HighCurrent) and +17V (1.5 mm Power) rails + LM317 ADJ node routed over a GND
  pour. kicad-cli pcb drc -> 0 violations. VREG_IN/VRAW left as ratsnest (the VREG_IN
  cross-row link needs a via — documented).
- **Chassis-fit packing-density check** in gen_pcb.py: ~51% on 190×115 (original
  PCB size, feasible-but-tight) vs ~88% on the Part 7 155×90 safe-bet — i.e. the
  102-part through-hole design does NOT fit the smaller chassis comfortably.
  Recorded in kicad/PCB-NOTES.md (ties to errata #9): measure the real chassis,
  or move passives to SMD, before committing to a board size.

### Audit, sockets, schematic centering & VREG_IN pass (2026-06-15)
- **Availability / sockets / current / noise audit** (docs/component-availability-
  audit.md): parts tiered by sourceability (JFETs + LM1875 are the single-points-
  of-failure); DIP op-amp sockets made REQUIRED (machined-pin); per-rail current
  budget; noise review. (Power-budget numbers were later corrected — see roast R2.)
- **+27V → VREG_IN:** kept the R_27V/C_filt1 element as an LM317-input RC pre-filter
  + power-amp decoupler (a noise feature), bumped 47Ω→100Ω/2W→1W, renamed the net
  and corrected the "27V rail" misnomer (~32V) across schematic/PCB/docs.
- **Schematic pages centered**; **PCB layout audit** (kicad/PCB-AUDIT.md) with the
  off-board-pot footprint fix + grid centering; **SPICE audit** (block-level).

### Roast pass (2026-06-16) — see docs/roast-2026-06-16.md
- 🔴 **R1 added a MAINS PRIMARY FUSE** (was missing — only a secondary fuse
  existed; a mains-powered amp needs primary fusing). BOM + Part 1 safety/Part 3.
- 🔴 **R2 corrected the power spec:** 18 W is unreachable on the 33.5 V single rail
  (needs 17.0 V peak, only 16.75 V available) → real ceiling ~12 W. Fixed Part 1,
  Part 5 thermal, and the availability audit (which I'd built on the bad 18 W).
- 🟠 **R3** rebalanced the broken reverb mixer (R_dry_tap 1M→220k) and flagged that
  the unbuffered inter-effect chain needs a real summing stage before fab.
- 🟠 **R4** marked the orphaned `Wiring_Edge_Array_35` footprint as unused.
- 🟡 **R5–R8:** F1 inrush-path placement, shared-VBIAS tremolo bleed, the rail-less
  SPICE scope caveat, and this CHANGELOG cleanup — all documented.

### BOM value normalization + README refresh (2026-06-16)
- Generator now normalizes value strings (2K2→2.2k, 4K7→4.7k, drop " film") so the
  grouped BOM consolidates cleanly. ERC/DRC/SPICE unaffected.
- Rewrote the top-level **README** to match the current state: the generated +
  tool-verified KiCad/BOM/SPICE flow, the ~12 W power ceiling, the mains-fuse
  safety note, the 190×115 board / chassis-fit caveat, and the honesty/provenance
  framing. (Was still describing the original reconstructed-docs state.)

### Tone stack designed + verified (2026-06-16)
- The `TONE_STACK` placeholder (TBD) is replaced by a **working passive Vox-style
  tone**: Volume pot + a treble "cut" (C_cut 10 nF + POT_TONE 100 k to ground),
  since the original 25-5274-2 values were never recovered. Response simulated in
  `spice/ac_tonestack.cir`: flat at bright (−1.6 dB), musical treble cut at the
  dark end (−9 dB @ 5 kHz, −14 dB @ 10 kHz). Flagged as a designed substitute
  (the original panel may have had separate Treble/Bass). ERC 0; BOM regenerated.

### Schematic completion + generated BOM (2026-06-16)
- **Completed the schematic** — added parts that were in Part 2/the BOM but never
  placed: the four rectifier snubbers (C101–C104), the 2nd pre-filter cap
  (C_filt2), and the tremolo **speed/depth pots** (POT_SPD as a rheostat in the
  Wien arm, POT_DPT scaling the LFO into the LED). 117 components, ERC 0.
- **BOM is now GENERATED from the schematic** (`kicad/gen/gen_bom.py`): every
  reference is 1:1 with the netlist (no more drift — the hand BOM had ~20 missing
  and ~20 stale rows), merged with curated P/Ns + notes and an explicit
  off-board/mechanical section. Added `bom/bom-grouped.csv` (by value, for
  ordering). Density rose to 53 % / 90 % (190×115 / 155×90) — reinforces the
  chassis-fit finding.

### Effects-chain redesign (2026-06-16) — resolves roast R3 + R6
- **Active reverb wet/dry summer** on the spare IC1-B half (inverting summer about
  VBIAS_R: dry always on, wet via POT_REV, unity each). Removed the broken passive
  R_dry_tap/R_blend1/R_blend2 mixer.
- **Output buffer** on the spare IC2-B half drives PA_IN from the post-MRB node
  (removed the unbuffered R_painput 1 M and the dead C_trem_out/R_trem_pass branch).
- **Split bias:** VBIAS → independent **VBIAS_R / VBIAS_T** dividers (100k/100k +
  47 µF each) so the LFO can't modulate the reverb reference.
- **Rail-aware verification:** new `models/opamp_rail.sub` (output clamped to the
  supplies) + `spice/tran_reverb_mixer.cir` confirm single-supply mid-rail bias
  (8.50 V), unity sum, and ±7 V headroom before clipping — the kind of large-signal
  check the rail-less model couldn't do (roast R7).
- ERC 0; full board regenerated (106 footprints); demo DRC 0; BOM updated.

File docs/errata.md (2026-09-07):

# Vox Cambridge Reverb — Errata & Sanity Check

> Reconstructed document — see `PROVENANCE.md`. The original errata listed 17
> cross-document inconsistencies. Issues 1–8 below are recovered substantially
> verbatim. Issues 9–17 were **not** recovered verbatim; they were re-derived by
> a fresh consistency pass on 2026-06-14 (the resolutions are newly authored, the
> reconciled values are recovered). The three HIGH-severity items (Issues 4, 7,
> and the JFET/MRB items) are folded into the relevant reconstructed docs.

## Issue 1 — Part 1 referenced external FX-loop / headphone jacks
The user keeps the original panel with no new holes. FX loop must be internal-only
(IN3 repurposing); headphone output removed; MRB internal-only.
**Severity:** MEDIUM. *(Folded into Part 1 §7.)*

## Issue 2 — Part 1 key-improvements list mentioned external features
Change to: internal FX-loop provision (IN3), on-board tremolo rate LED
(diagnostic, not panel), remove headphone output.
**Severity:** LOW.

## Issue 3 — Bridge rectifier naming (KBU4M vs KBP410G)
Both are 4A/1000V; different packages (KBP410 inline 4-pin, KBU4M SIP 4-pin).
PCB footprint should accommodate both. Part 8 prefers KBP410G for availability.
**Severity:** LOW.

**Update (2026-09-06):** the board now carries a real, datasheet-derived
**KBP footprint** (`cambridge_reverb:Bridge_KBP_P3.81mm`, from Diodes DS39310
KBP404G–KBP410G: 3.81 mm pitch, 0.86 × 0.55 mm leads → 1.2 mm drill, 14.5 × 3.5 mm
body, pins **+ ~ ~ −** as marked). The schematic bridge symbol was renumbered to
that physical order (pin 1 = +, 2 = ~, 3 = ~, 4 = −) so pad and pin numbers agree.
One footprint **cannot** accommodate both parts: KBU is 5.08 mm pitch, and
overlapping the two hole patterns would put holes 1.27 mm apart (violates the
0.25 mm hole-to-hole rule). To build with a KBU4M instead, swap the `BRIDGE`
footprint in `kicad/gen/gen_kicad.py` for a 5.08 mm-pitch one and regenerate.

## Issue 4 — Part 2 listed 2N5457 TO-92 (discontinued) — HIGH
Through-hole 2N5457 is discontinued; the Mouser P/N would show no stock. Primary
options are MMBF5457 on adapter or J113; keep 2N5457 only "if you find genuine."
**Severity:** HIGH. *(Folded into Parts 1, 2, 8.)*

## Issue 5 — Part 1 listed TIP41C/TIP42C discrete output as an option
The rest of the suite assumes the LM1875 as the sole power amp. Clarify the
discrete stage is reference-only, not developed (no BOM/SPICE/wiring).
**Severity:** MEDIUM. *(Folded into Part 1 §3.)*

## Issue 6 — Part 1 mentioned LM13700 OTA tremolo modulator
No BOM/SPICE/wiring exists for it; LED/LDR (VTL5C1) is used throughout. Note as
an undocumented advanced alternative.
**Severity:** LOW.

## Issue 7 — Part 2 said 2200µF output cap was "only for discrete output" — HIGH
The LM1875 in single-supply mode ALSO requires the 2200µF output coupling cap.
Remove the qualifier.
**Severity:** HIGH. *(Folded into Part 2 BOM + Part 1 §3.)*

## Issue 8 — Part 1 §6 described MRB with a panel rotary switch
Implies a new panel control. Default is hardwired 600 Hz; any selector is
internal-only (inside chassis or repurposing the line-reverse switch).
**Severity:** MEDIUM. *(Folded into Part 1 §6.)*

## Issues 9–17 — consistency pass (2026-06-14)

The original Issues 9–17 were not recovered verbatim. Rather than leave them as
a stub, the topics flagged in the project record were re-derived by a fresh
cross-document consistency pass over the *reconstructed* docs, the BOM, the
SPICE netlist, and `kicad/netlist-notes.txt`. These resolutions are **newly
authored** (not recovered originals); the underlying values they reconcile are
recovered. Re-verify before fabrication.

## Issue 9 — Board dimensions: 190×115 vs 155×90 mm
Part 4 (and the Part 5 floor plan) use **190 × 115 mm** to match the original
25-5274-2 footprint; Part 7 recommends **155 × 90 mm** as a measure-first "safe
bet." These are not contradictory — the outline is a measurement-gated decision
point, not a fixed value. **Resolution:** measure the chassis (Part 7 procedure),
then set `Edge.Cuts` to the largest size your measured chassis supports; default
to 155×90 only if you cannot measure. Both numbers are intentionally retained.
**Severity:** MEDIUM (decision point — must be closed before the PCB outline is final).

## Issue 10 — 17 V rail: LM317 set resistors yield 16.9 V, below the stated 17.0–17.5 V band — re-verify
Part 2 specifies `R_reg1 = 240 Ω`, `R_reg2 = 3.0 kΩ`. With the LM317
(`Vout = 1.25 × (1 + R_reg2/R_reg1)`, I_adj negligible) this gives
**1.25 × (1 + 3000/240) = 16.88 V** — about 0.13 V *below* the 17.0–17.5 V
window quoted in Part 2 §setup and the Part 3 troubleshooting table.
**Resolution:** either (a) accept ~16.9 V and widen the stated window to
**16.8–17.5 V**, or (b) to actually land in 17.0–17.5 V, use `R_reg2 ≈ 3.09 kΩ`
(E96 → 17.34 V) or 3.01–3.07 kΩ. Recommended: **R_reg2 = 3.09 kΩ (E96)**.
**Severity:** MEDIUM.

## Issue 11 — Net-class table is missing a high-current (speaker/PA) class
Part 4's net-class table defines only **Default (0.30 mm)** and **Power
(1.50 mm)** and assigns +33V5/VREG_IN/+17V/GND/SPK_P/SPK_N all to Power. But the Part 4
pre-order checklist *and* `netlist-notes.txt` both call for **2.5 mm** on the
speaker / power-amp current path. The single 1.5 mm Power class can't satisfy
that. **Resolution:** add a third **HighCurrent (2.50 mm)** class for
`+33V5`, `SPKR+`, `SPKR-`, and the LM1875 output; keep **Power (1.50 mm)** for
`VREG_IN`, `+17V`, `GND`. This three-class split is encoded in
`kicad/cambridge_reverb.kicad_pro`.
**Severity:** MEDIUM.

**Update (2026-09-06):** `VRAW` (bridge output → fuse → `C_main`) and the
transformer secondary nets `AC1`/`AC2` carry the same current as `+33V5` (more,
as RMS: rectifier charging pulses) but had fallen into the 0.5 mm Default class.
They are now in **HighCurrent** too (`.kicad_pro` pattern list).

**Addendum (SMD variant, 2026-09-06):** `kicad/smd/cambridge_reverb_smd.kicad_pro`
uses **HighCurrent 2.0 mm / Power 1.0 mm** (0.25 mm clearance) instead of 2.5 / 1.5.
The wider classes were sized for the 190×115 THT board; on the 155×90 mixed-SMD
board they cannot pass between 0805/1206 pads and starved the router. Electrically
2.0 / 1.0 mm on 1 oz copper carry several amps — ample for ~1.7 A peak / <1 A RMS.

## Issue 12 — Via-drill specs disagree between Part 4 and netlist-notes
Part 4 design rules give min via drill **0.3 mm** and a Power-class via drill of
**0.5 mm**; `netlist-notes.txt` instead says **signal vias 0.5 mm**, **power
vias 1.0 mm**, **ground-stitch 0.8 mm**. **Resolution** (reconciled, encoded in
the `.kicad_pro`): Default via **0.4 mm drill / 0.8 mm dia**; Power via
**0.8 mm drill / 1.4 mm dia**; HighCurrent via **1.0 mm drill / 1.6 mm dia**;
ground-stitch vias **0.8 mm**. All are ≥ JLCPCB minimums and surcharge-free.
**Severity:** LOW.

## Issue 13 — Signal trace width: 0.30 mm (net class) vs 0.50 mm (netlist-notes)
Part 4's Default net class is 0.30 mm; `netlist-notes.txt` suggests 0.50 mm for
signal. Both pass DRC and exceed JLCPCB's 0.127 mm minimum. **Resolution:** adopt
**0.50 mm** as the working signal default for hand-assembly robustness (more
copper, easier rework); the net-class minimum stays 0.30 mm so tight spots are
still legal. Encoded in the `.kicad_pro` Default class.
**Severity:** LOW.

## Issue 14 — Reverb-pan part number consistency — confirmed, no action
Cross-checked Part 1 §4, Part 9, and `bom/bom.csv`: all specify the
high-impedance **Accutronics 4FB2A1C (~1475 Ω)** and all explicitly flag the
8 Ω-input **4AB3C1B as incompatible** with the direct TL072 driver. Consistent
across every document. **No change required.**
**Severity:** NONE (verified consistent).

## Issue 15 — JFET bias values across Part 2 and netlist-notes — consistent; preamp SPICE absent
Part 2's preamp self-bias (`R_g = 1 MΩ`, `R_d ≈ 10 kΩ`, `R_s ≈ 2.2 kΩ`,
`C_s = 10 µF`) matches the reverb-recovery JFET in `netlist-notes.txt`
(`R_rec_bias = 1 MΩ`, `R_rec1 = 10 kΩ`, `R_rec2 = 2.2 kΩ`, `C_rec_byp = 10 µF`).
**Caveat:** only the *power-amp* SPICE netlist was recovered, so there was no
preamp/recovery SPICE to cross-check the bias point against.

**Update (ngspice, 2026-06-14):** a preamp sim now exists
(`spice/dc_preamp_jfet.cir`). With a nominal 2N5457 (Idss ≈ 3 mA, Vp ≈ −1.8 V),
the recovered `R_s ≈ 2.2 kΩ` / `R_d = 10 kΩ` bias the **drain at ~12 V**
(Id ≈ 0.49 mA) — *colder* than the 8–9 V target in Part 2/Part 3. Simulated fix:
**R_s ≈ 1.0 kΩ → Vd ≈ 8.5 V**, **R_s ≈ 1.2 kΩ → Vd ≈ 9.5 V**. The 2N5457 has a
wide Idss/Vp spread, so treat R_s ≈ 1–1.2 kΩ as the nominal and **trim per device
on the bench**. The BOM keeps the recovered 2.2 kΩ with this note.
**Severity:** LOW (bias trim) — but verify before relying on the stated 8–9 V.

## Issue 16 — Main filter cap: 4700 µF (Part 2) vs 2× 2200 µF split (Part 7)
Part 2's BOM gives **C_main = 4700 µF/50 V**; Part 7 notes the original ~5000 µF
cap was chassis-mounted and suggests **2× 2200 µF side-by-side** *only if* you
PCB-mount it and vertical clearance to the control panel is tight. Not a conflict
— 4700 µF is canonical; the 2× 2200 µF is a mechanical fallback. **Resolution:**
BOM keeps 4700 µF; clearance check in Part 7 decides whether the split is needed.
**Severity:** LOW.

## Issue 17 — "Bypass on each supply pin" wording vs single-supply reality
Part 1 §3 says "100 nF + 10 µF on **each** supply pin." In the single-supply
LM1875 design, V− (pin 3) **is** ground, so the bypass pair lands on **V+ (pin 5)
only**, exactly as Part 2 and the netlist show (`C_byp1`, `C_byp2` on pin 5 → GND).
**Resolution:** read "each supply pin" as "the V+ supply pin"; no extra parts.
**Severity:** LOW (wording).

## Issue 18 — JFET symbol pin numbers did not match the TO-92 / SOT-23 parts (2026-09-06) — HIGH
The generated schematic's JFET symbol numbered its pins **1 = Drain, 2 = Gate,
3 = Source**, and the board used the stock `TO-92_Inline` footprint with pads 1-2-3
in a row. The onsemi datasheets for **both** specified parts number the leads
**1 = Drain, 2 = Source, 3 = Gate** — 2N5457/J113 (TO-92, straight-lead) and
MMBF5457 (SOT-23) alike — so a real part fitted to the old board would have had
its gate on the source pad and vice-versa (Q1, Q2, Q_rec). ERC/DRC cannot see
this; it was caught while adding the SOT-23 footprint for the mixed-SMD variant.
**Resolution:** symbol renumbered to 1 = D, 2 = S, 3 = G; all three JFET net maps
updated; both boards regenerated. If you populate the THT board with a SOT-23 on a
TO-92 adapter, wire the adapter D-S-G to pads 1-2-3.
**Severity:** HIGH (silent wiring fault) — fixed in the generator; verify against
the datasheet of whatever JFET you actually buy (J113: also D-S-G).

## Issue 19 — The tremolo LFO as recovered cannot run at tremolo rates (2026-09-07) — HIGH
The recovered Wien-bridge LFO put the speed pot in **one** arm only: series arm
`R_lfo_ser` 10 k + `POT_SPD` 0–500 k with `C_lfo1` 100 nF, shunt arm a fixed
`R_lfo1` 33 k with `C_lfo2` 100 nF, amplifier gain 1 + 10 k/4.7 k = 3.13. For an
asymmetric Wien network the loop only starts when gain > 2 + R1/R2, i.e. while the
series arm stays under ~37 k — the bottom **5 %** of the pot — and there it runs at
**45–80 Hz** (f₀ = 1/(2π√(R1R2)C)). Everywhere else it does not oscillate at all.
Part 2's "~1 Hz to ~10 Hz" was never reachable with those values. Swept and shown
in `spice/sweep_lfo_speed_recovered.cir` (results in `spice/results/`).
**Resolution:** symmetric network with a **dual-gang 250 k lin speed pot**, one gang
in each arm, `R_lfo_ser` = `R_lfo_sh` = 15 k floors, `C_lfo1` = `C_lfo2` = **1 µF**.
The attenuation is then exactly 1/3 at every setting, the existing gain-3.13 /
diode-limited amplifier starts everywhere, and f = 1/(2π(15 k + pot)·1 µF) =
**10.6 Hz (fast) … 0.60 Hz (slow)** at constant 0.96 Vpp
(`spice/sweep_lfo_speed.cir`). The dual-gang pot goes in the original speed-pot
hole (no new holes); the original single pot is no longer reused. Alternative if
you insist on the single pot: a one-op-amp Schmitt relaxation LFO — square/
exponential waveform, harder tremolo; not adopted. `POT_SPD_A`/`POT_SPD_B` in the
schematic and BOM are the two gangs of **one** part.
**Severity:** HIGH (the effect did not work as drawn) — fixed in the generator;
both boards regenerated and re-routed.

## Issue 20 — Tone: the single "cut" pot did not match the panel, and the recovered coupling had no bass (2026-09-07) — HIGH
Two problems in the tone sheet, one recovered and one designed. **(a)** The
recovered preamp coupled Q2's drain to the tone/volume network through
`C_treble` **470 pF alone** — into the ~250 k volume pot that is a **1.3 kHz
high-pass**: no bass or low-mids at all reached the reverb, tremolo or power amp.
`C_treble` is the Vox "chime" cap; it belongs *across the top of the volume pot*
as a bright cap, not in series as the only coupling. **(b)** The Cambridge Reverb's
panel has **Bass and Treble** pots, but the designed substitute (cross-check §4)
was a Volume + single treble "cut" pot: the Bass hole had nothing to drive.
**Resolution (built design, `kicad/gen/gen_kicad.py` tone sheet):**
- `C_cpl_out` **1 µF** couples Q2D → `PREAMP_OUT` (flat to ~16 Hz into the 1 M
  bias resistor); `C_treble` 470 pF moves across the top half of the volume pot
  (bright cap: treble lift at low volume, transparent at full).
- A **passive James (Thomas-Vox style) Bass/Treble network** driven by a TL074
  buffer (`IC3`-A) and followed by a ×2 make-up stage (`IC3`-B) — the topology the
  originals used, deliberately **not** an active Baxandall: asymmetric, more cut
  than boost, a slight bright tilt at noon, both pots **250 k lin** in the original
  holes. `R_j1`/`R_j2` 10 k, `C_j1`/`C_j2` 22 nF, `R_j3` 68 k (bass ladder);
  `C_j3`/`C_j4` 2.2 nF, `R_j4` 1 k (treble ladder). Swept in
  `spice/sweep_tonestack.cir`: bass −7.5 … +4.9 dB @ 100 Hz, treble −16.5 … +5.6 dB
  @ 10 kHz, noon flat within 0.3 dB (`spice/results/`).
- A **switchable MID CUT** for honky pickups: `R_mid` 10 k then a series-resonant
  shunt to mid-rail — `C_res` 22 nF + a gyrator (`IC3`-C, `R_gL` 4.7 k, `C_gg`
  1.8 nF, `R_gg` 220 k → L = 1.86 H). **−9.6 dB at ~800 Hz, Q ≈ 0.6** (broad:
  −3 dB from ~400 Hz to ~1.7 kHz), flat within 0.05 dB when off. `SW_MID` is an
  SPST mini toggle in the **original line-reverse switch hole** (that position
  was reserved for "internal repurposing" in Issue 8 — no new holes). The switch
  sits on a node at mid-rail DC on both sides, so it does not pop.
- `IC3`-D buffers the result into the volume pot; `TONE_OUT` still feeds the
  summer, the tank driver and the FX send as before. `IC3` gets its own mid-rail
  (`VBIAS_3`, split-bias policy) and a DIP-14 socket; test points `TMK`
  (make-up output) and `VB_3` join the strip.
**Severity:** HIGH ((a) alone made the amp sound like a treble-only transistor
radio) — fixed in the generator; both boards regenerated and re-routed. The
"designed substitute" wording in cross-check §4 is superseded.

## Issue 21 — Hum and hiss: the LM1875 bias divider had no bypass, and the LM317's noise reached the JFETs (2026-09-07) — HIGH
Found by the first noise / hum models (`spice/ac_hum_psrr.cir`, `spice/noise_frontend.cir`,
Part 6c). **(a) Hum.** The power-amp input was biased by `R_bias1`/`R_bias2` (22 k/22 k
from +33V5) with the LM1875's + input sitting *on* the divider node and no bypass
capacitor: half the rail ripple went straight into the amplifier, ×23, to the speaker —
**+4 dB ripple-to-speaker, 0.4 Vrms of 100 Hz at idle (−28 dB below full power)**. Fix:
the textbook single-supply network — divider node bypassed by `C_bref` **100 µF**, then
`R_bias3` **22 k** into the + input (input impedance unchanged, LF corner 7 Hz with
`C_in_pa`): **−58 dB**, 0.3 mV. **(b) Hiss.** The LM317 puts out ~510 µV rms of noise
(TI: 0.003 % of V_out, 10 Hz–10 kHz) and the JFET common-source stages have ~0 dB PSRR,
so the regulator — not the JFETs — set the preamp noise floor, **23 dB above** the JFETs'
own: input-referred 37 µV rms, SNR 34 dB at 12 W. Fix: `C_adj` **10 µF** on the LM317 ADJ
pin (TI: ripple rejection 65 → 80 dB, noise ÷ ~10) and an RC-decoupled rail for the
three JFET stages, `R_pre` **100 Ω** + `C_pre` **220 µF** (`+17V_PRE`, 7 Hz corner) —
EIN 2.7 µV, SNR 57 dB, hum path B −95 dB. Four cheap parts. **Severity:** HIGH (the amp
would have hummed audibly at idle and hissed like a much worse design).

## Issue 22 — Tremolo had no depth: the vactrol LED ran at 7 mA DC (2026-09-07) — HIGH
`spice/tran_tremolo_depth.cir` (a behavioural VTL5C1 added to the errata #19 LFO) shows
the tremolo as drawn: the LFO output sits at the 8.5 V mid-rail with a ±0.5 V swing
(1N4148 limiter), and the vactrol LED was returned to **ground** through 1 k — so it
carried **6.4–7.4 mA DC**, the LDR sat at ~1 kΩ, and the "tremolo" was a permanent
**−19.5 dB pad with 1.7 dB of wobble**. The rate LED (2.2 k to ground) glowed steadily
for the same reason. Fix: the limiter diodes become two antiparallel **red LEDs** across
`R_lfo_fb1` (knee ~1.6 V → **2 V** LFO swing; `LED_rate` is one of them and now really
blinks; `LED_lim` is the other; `D_lfo1`/`D_lfo2`/`R_led_diag`/`R_led` are gone) and the
vactrol LED gets a driver: `Q_trem` (2N3904; MMBT3904 on the SMD board, on a SOT-23
footprint renumbered to the TO-92's E-B-C order) as an emitter follower, AC-coupled from
the depth pot by `C_drv` **100 µF** into a **180 k/10 k** base bias (~0.9 V, just below
conduction), `R_e` **470 Ω**, vactrol LED from +17 V via `R_c` **100 Ω** in the collector.
Result: LED 0…4.7 mA at the LFO rate, LDR 1.9 k…50 MΩ, **15 dB depth**, 0.8 dB insertion
loss. The LM317 sees ≤ 6 mA more at the LFO peak (Part 6c §5). **Severity:** HIGH (the
effect did not work); the depth pot and the footswitch tap are unchanged.

## Issue 23 — Fab rules: two footprints under JLCPCB's annular-ring minimum; assembly cost knobs (2026-09-07) — MEDIUM
Checking both boards against JLCPCB's published 2-layer limits (Part 4, updated): the stock
`TO-92_Inline` (1.05 mm pads on 0.75 mm holes) has a **0.15 mm** ring and the project's
LM1875 footprint (1.45 mm pads on 1.1 mm holes) **0.175 mm** — both under JLC's 0.18 mm
absolute minimum (0.25 recommended). Fixes: JFETs and the new `Q_trem` on
`TO-92_Inline_Wide` (2.54 mm pitch — which also matches the SOT-23→TO-92 adapters —
1.5 mm pads, 0.35 mm ring); LM1875 pads 1.5 × 2.6 mm (0.20 mm ring; the 1.7 mm pitch
cannot give 0.25 without a 1.0 mm drill that the 0.97 mm lead diagonal would not
survive — JLC's absolute minimum is met, the recommendation is not, and it is stated on
the footprint). Both `.kicad_pro` files now carry the JLC limits as DRC constraints
(hole-to-hole 0.5, hole-to-copper 0.3, annular 0.18, mask dam 0.1, silk 0.15 / 1.0 mm),
so the check is automatic. Cost: on the assembled SMD board the price is driven by
part **types** (an "extended" library part costs $3 per type per order) rather than
board area, so the 1210 capacitor line (an extended part) is folded into 1206, the two
optional MRB caps are marked **DNP** (not placed, not in the assembly BOM), and the
gyrator moves to E24 values (2.2 nF / 180 k, same 1.86 H): 31 → 29 lines, 7 → 2
extended types (`kicad/gen/jlc_cost.py`). Three fiducials were added for the
pick-and-place camera. **Severity:** MEDIUM (a fab would have flagged the rings or
produced breakouts; the rest is money).

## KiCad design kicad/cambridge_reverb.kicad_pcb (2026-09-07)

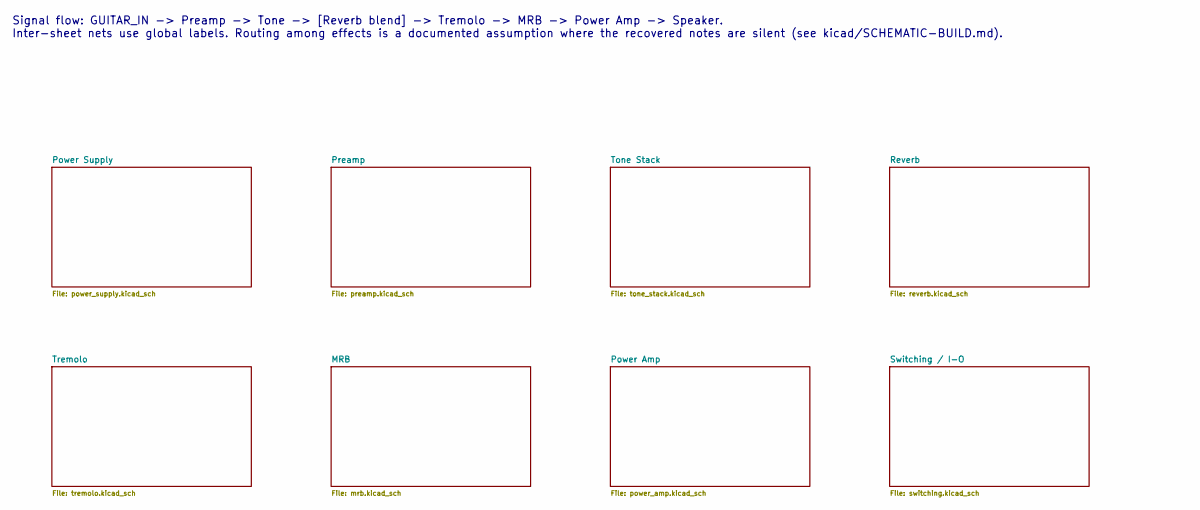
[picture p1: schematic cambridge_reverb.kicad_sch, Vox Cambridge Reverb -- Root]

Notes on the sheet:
Signal flow: GUITAR_IN -> Preamp -> Tone -> [Reverb blend] -> Tremolo -> MRB -> Power Amp -> Speaker. Inter-sheet nets use global labels. Routing among effects is a documented assumption where the recovered notes are silent (see kicad/SCHEMATIC-BUILD.md).

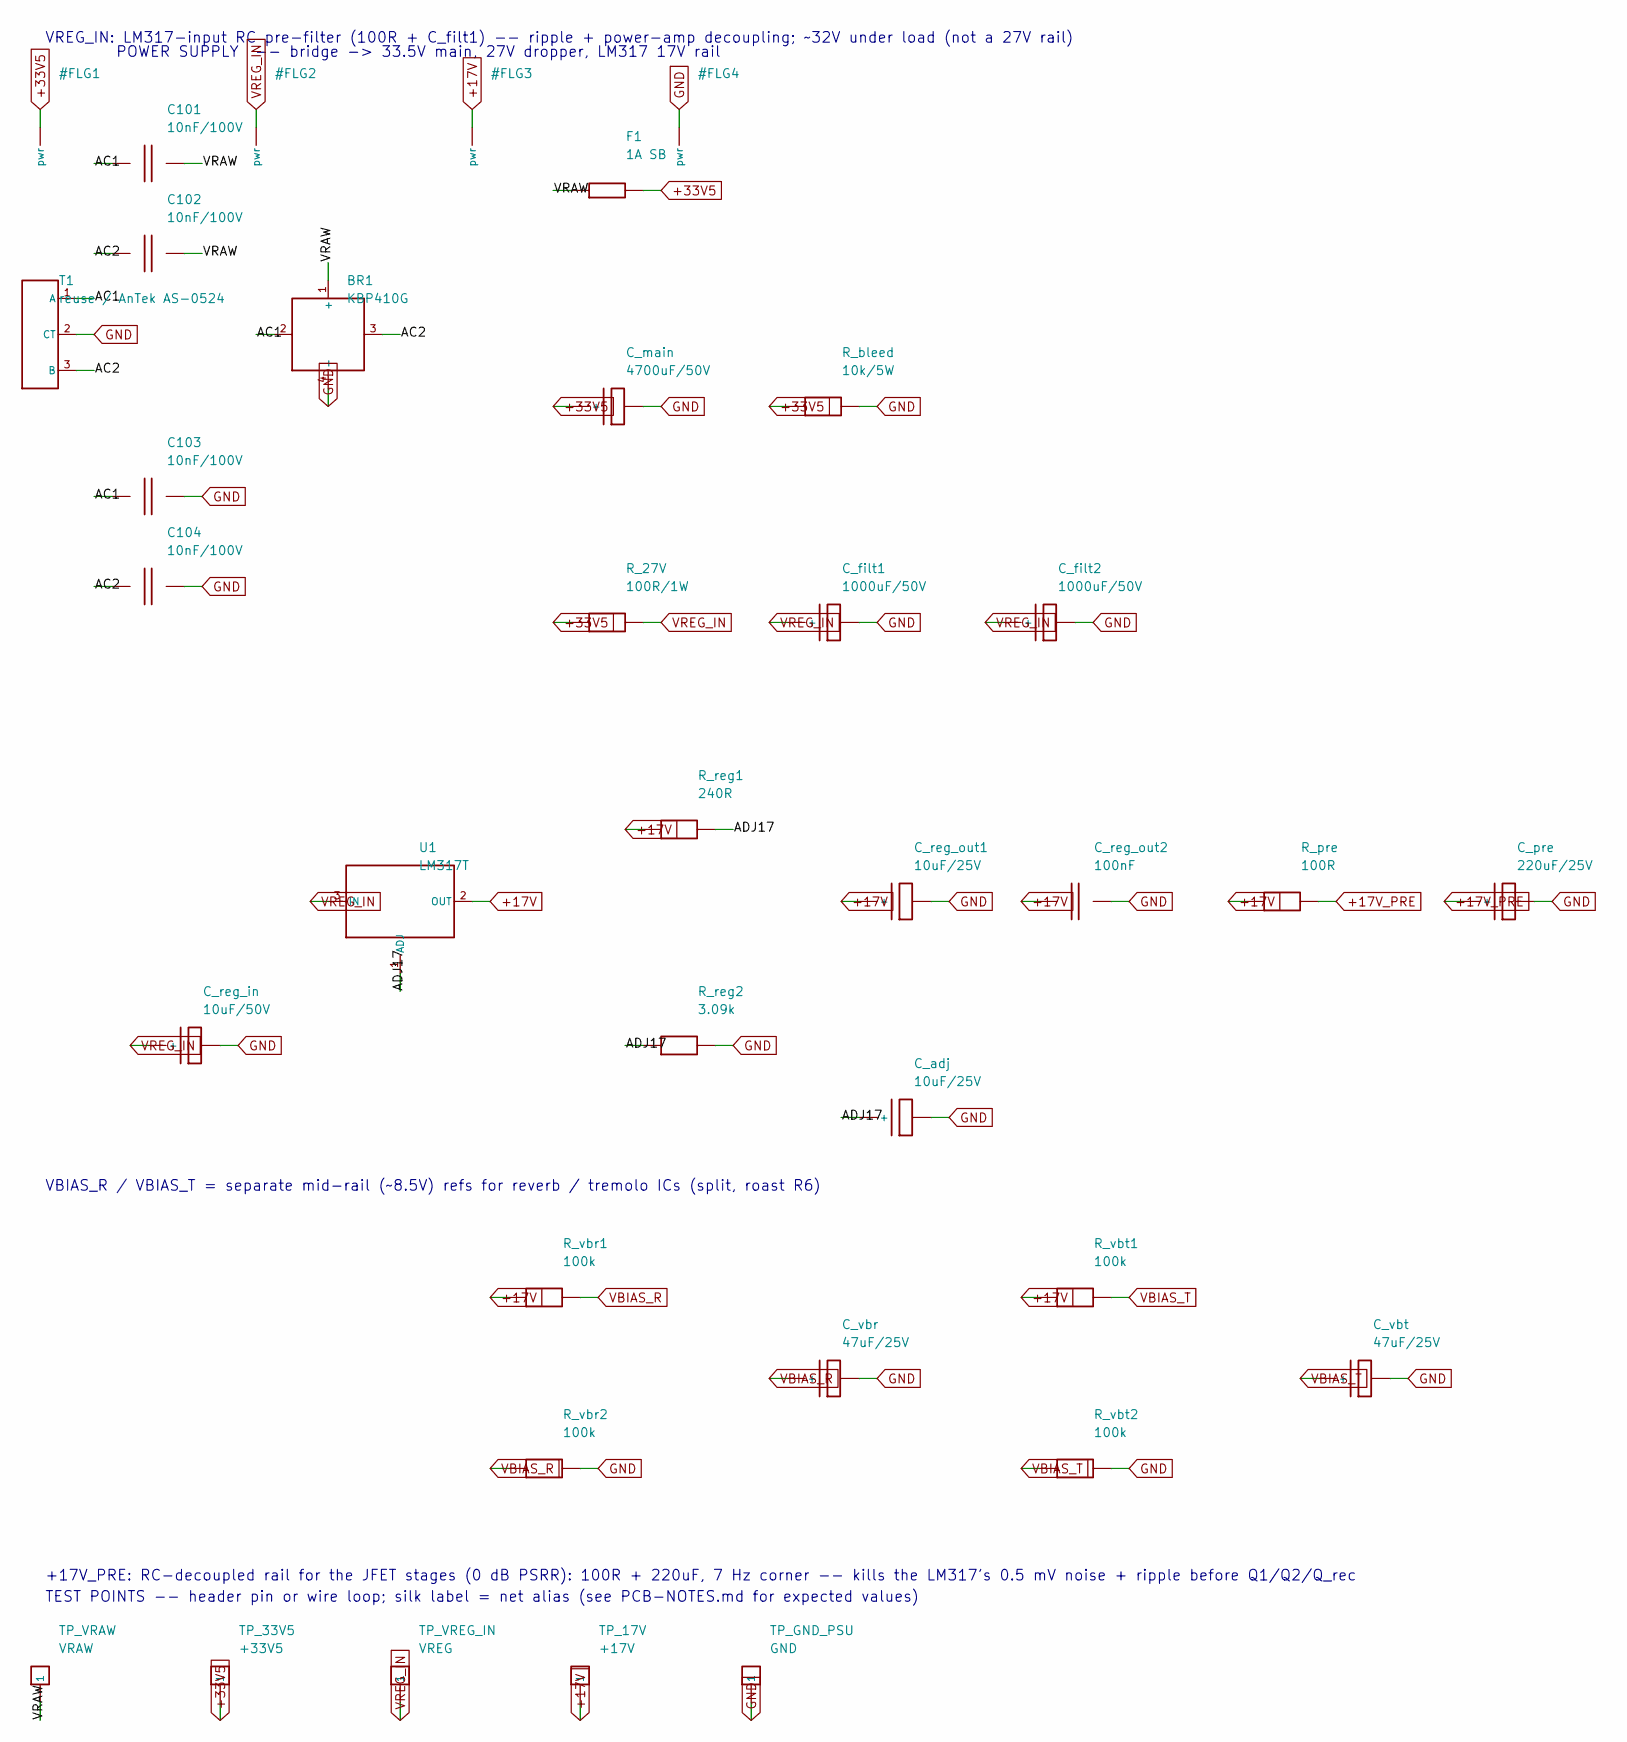
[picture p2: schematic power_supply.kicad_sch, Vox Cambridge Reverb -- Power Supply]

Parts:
BR1: KBP410G; Bridge_KBP_P3.81mm
C101, C102, C103, C104: 10nF/100V; C_Disc_D7.5mm_W2.5mm_P5.00mm
C_adj: 10uF/25V; CP_Radial_D5.0mm_P2.00mm
C_filt1, C_filt2: 1000uF/50V; CP_Radial_D12.5mm_P5.00mm
C_main: 4700uF/50V; CP_Radial_D18.0mm_P7.50mm
C_pre: 220uF/25V; CP_Radial_D6.3mm_P2.50mm
C_reg_in: 10uF/50V; CP_Radial_D5.0mm_P2.50mm
C_reg_out1: 10uF/25V; CP_Radial_D5.0mm_P2.50mm
C_reg_out2: 100nF; C_Disc_D7.5mm_W2.5mm_P5.00mm
C_vbr: 47uF/25V; CP_Radial_D6.3mm_P2.50mm
C_vbt: 47uF/25V; CP_Radial_D6.3mm_P2.50mm
F1: 1A SB; Fuseholder_Clip-5x20mm_Eaton_1A5601-01_Inline_P20.80x6.76mm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
R_27V: 100R/1W; R_Axial_DIN0414_L11.9mm_D4.5mm_P15.24mm_Horizontal
R_bleed: 10k/5W; R_Axial_Power_L20.0mm_W6.4mm_P25.40mm
R_pre: 100R; R_Axial_DIN0207_L6.3mm_D2.5mm_P5.08mm_Vertical
R_reg1: 240R; R_Axial_DIN0207_L6.3mm_D2.5mm_P5.08mm_Vertical
R_reg2: 3.09k; R_Axial_DIN0207_L6.3mm_D2.5mm_P5.08mm_Vertical
R_vbr1, R_vbr2: 100k; R_Axial_DIN0207_L6.3mm_D2.5mm_P5.08mm_Vertical
R_vbt1, R_vbt2: 100k; R_Axial_DIN0207_L6.3mm_D2.5mm_P5.08mm_Vertical
T1: reuse / AnTek AS-0524; WirePad_1x03_P5.08mm_D1.5mm
TP_17V: +17V; TestPoint_THT_D2.0mm_Label
TP_33V5: +33V5; TestPoint_THT_D2.0mm_Label
TP_GND_PSU: GND; TestPoint_THT_D2.0mm_Label
TP_VRAW: VRAW; TestPoint_THT_D2.0mm_Label
TP_VREG_IN: VREG; TestPoint_THT_D2.0mm_Label
U1: LM317T; TO-220-3_Vertical

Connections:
+17V: C_reg_out1.1 (+), C_reg_out2.1, R_pre.1, R_reg1.1, R_vbr1.1, R_vbt1.1, TP_17V.1, U1.2 (OUT); also elsewhere on the board
+17V_PRE: C_pre.1 (+), R_pre.2; also elsewhere on the board
+33V5: C_main.1 (+), F1.2, R_27V.1, R_bleed.1, TP_33V5.1; also elsewhere on the board
AC1: BR1.2, C101.1, C103.1, T1.1 (A)
AC2: BR1.3, C102.1, C104.1, T1.3 (B)
ADJ17: C_adj.1 (+), R_reg1.2, R_reg2.1, U1.1 (ADJ)
GND: BR1.4 (-), C103.2, C104.2, C_adj.2, C_filt1.2, C_filt2.2, C_main.2, C_pre.2, C_reg_in.2, C_reg_out1.2, C_reg_out2.2, C_vbr.2, C_vbt.2, R_bleed.2, R_reg2.2, R_vbr2.2, R_vbt2.2, T1.2 (CT), TP_GND_PSU.1; also elsewhere on the board
VBIAS_R: C_vbr.1 (+), R_vbr1.2, R_vbr2.1; also elsewhere on the board
VBIAS_T: C_vbt.1 (+), R_vbt1.2, R_vbt2.1; also elsewhere on the board
VRAW: BR1.1 (+), C101.2, C102.2, F1.1, TP_VRAW.1
VREG_IN: C_filt1.1 (+), C_filt2.1 (+), C_reg_in.1 (+), R_27V.2, TP_VREG_IN.1, U1.3 (IN)

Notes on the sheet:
POWER SUPPLY -- bridge -> 33.5V main, 27V dropper, LM317 17V rail
VREG_IN: LM317-input RC pre-filter (100R + C_filt1) -- ripple + power-amp decoupling; ~32V under load (not a 27V rail)
+17V_PRE: RC-decoupled rail for the JFET stages (0 dB PSRR): 100R + 220uF, 7 Hz corner -- kills the LM317's 0.5 mV noise + ripple before Q1/Q2/Q_rec
VBIAS_R / VBIAS_T = separate mid-rail (~8.5V) refs for reverb / tremolo ICs (split, roast R6)
TEST POINTS -- header pin or wire loop; silk label = net alias (see PCB-NOTES.md for expected values)

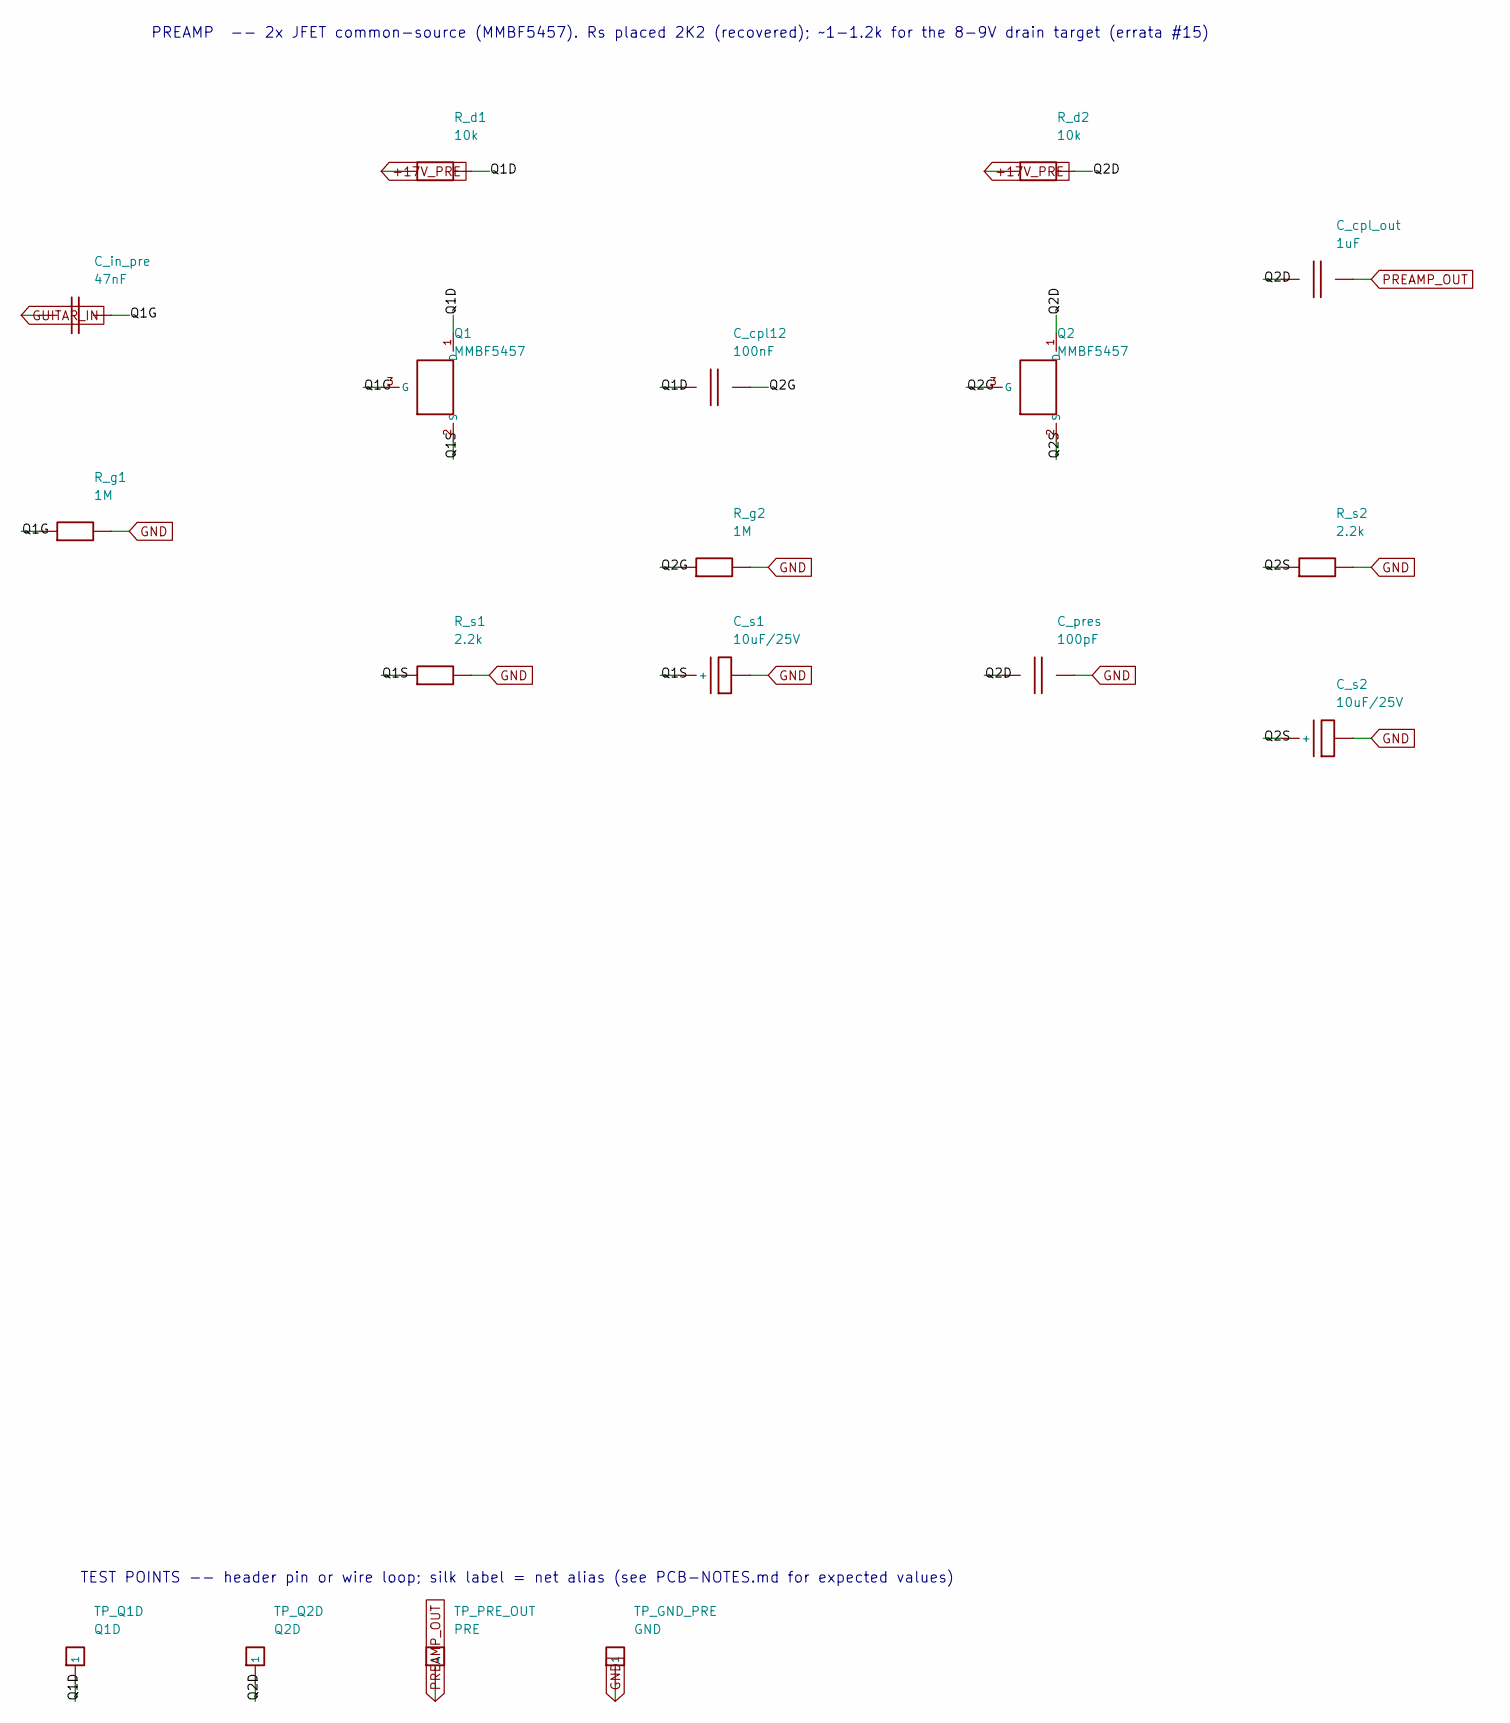
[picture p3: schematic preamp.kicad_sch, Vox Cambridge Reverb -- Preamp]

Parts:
C_cpl12: 100nF; C_Disc_D7.5mm_W2.5mm_P5.00mm
C_cpl_out: 1uF; C_Disc_D7.5mm_W2.5mm_P5.00mm
C_in_pre: 47nF; C_Disc_D7.5mm_W2.5mm_P5.00mm
C_pres: 100pF; C_Disc_D7.5mm_W2.5mm_P5.00mm
C_s1, C_s2: 10uF/25V; CP_Radial_D5.0mm_P2.00mm
Q1, Q2: MMBF5457; TO-92_Inline_Wide
R_d1, R_d2: 10k; R_Axial_DIN0207_L6.3mm_D2.5mm_P5.08mm_Vertical
R_g1, R_g2: 1M; R_Axial_DIN0207_L6.3mm_D2.5mm_P5.08mm_Vertical
R_s1, R_s2: 2.2k; R_Axial_DIN0207_L6.3mm_D2.5mm_P5.08mm_Vertical
TP_GND_PRE: GND; TestPoint_THT_D2.0mm_Label
TP_PRE_OUT: PRE; TestPoint_THT_D2.0mm_Label
TP_Q1D: Q1D; TestPoint_THT_D2.0mm_Label
TP_Q2D: Q2D; TestPoint_THT_D2.0mm_Label

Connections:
+17V_PRE: R_d1.1, R_d2.1; also elsewhere on the board
GND: C_pres.2, C_s1.2, C_s2.2, R_g1.2, R_g2.2, R_s1.2, R_s2.2, TP_GND_PRE.1; also elsewhere on the board
GUITAR_IN: C_in_pre.1; also elsewhere on the board
PREAMP_OUT: C_cpl_out.2, TP_PRE_OUT.1; also elsewhere on the board
Q1D: C_cpl12.1, Q1.1 (D), R_d1.2, TP_Q1D.1
Q1G: C_in_pre.2, Q1.3 (G), R_g1.1
Q1S: C_s1.1 (+), Q1.2 (S), R_s1.1
Q2D: C_cpl_out.1, C_pres.1, Q2.1 (D), R_d2.2, TP_Q2D.1
Q2G: C_cpl12.2, Q2.3 (G), R_g2.1
Q2S: C_s2.1 (+), Q2.2 (S), R_s2.1

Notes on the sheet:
PREAMP -- 2x JFET common-source (MMBF5457). Rs placed 2K2 (recovered); ~1-1.2k for the 8-9V drain target (errata #15)
TEST POINTS -- header pin or wire loop; silk label = net alias (see PCB-NOTES.md for expected values)

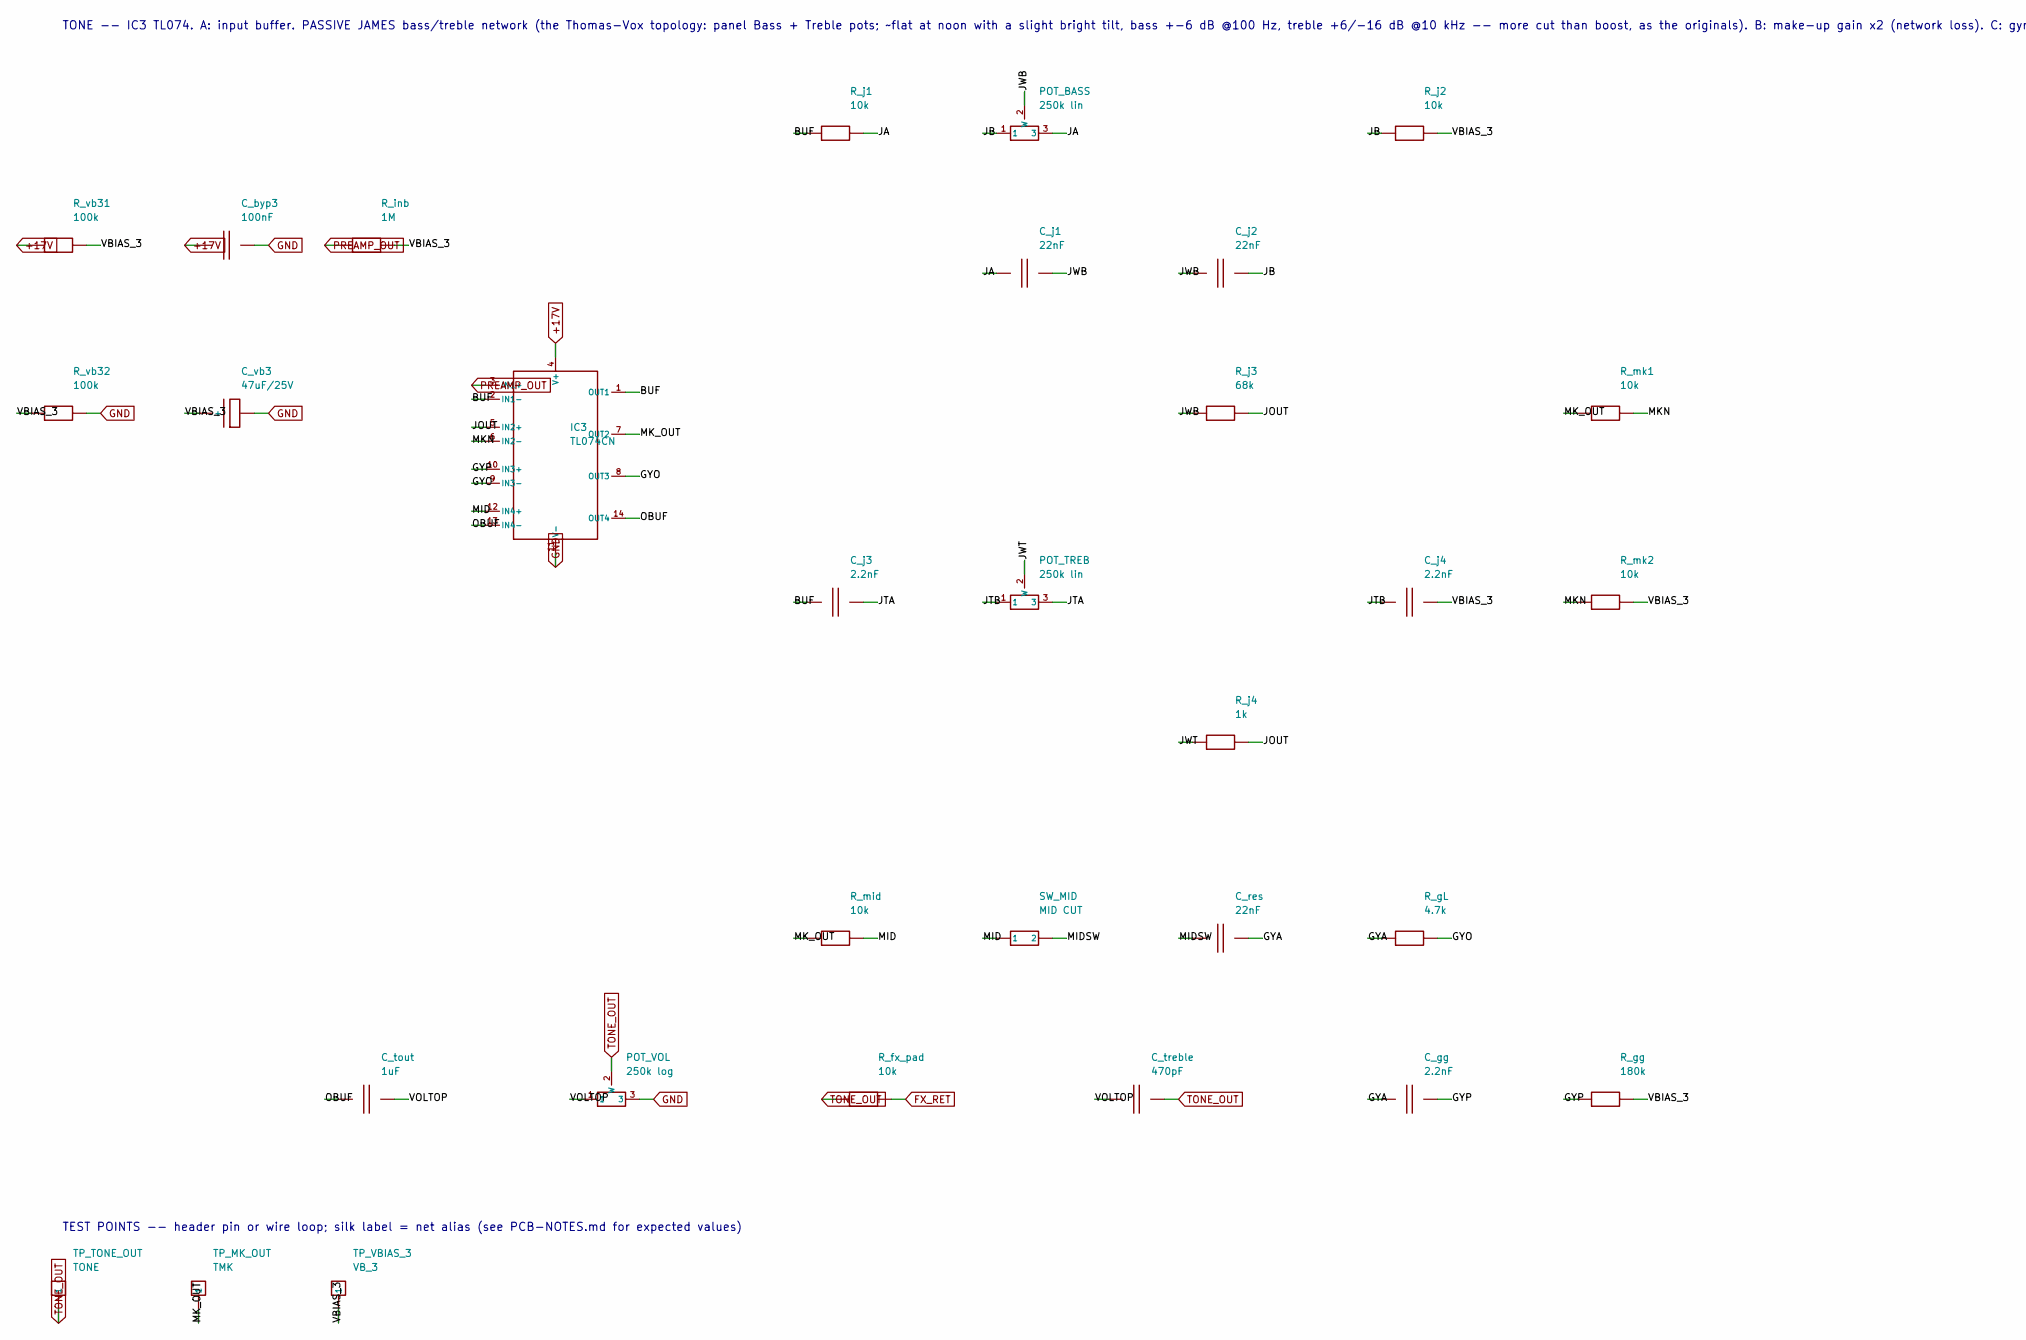
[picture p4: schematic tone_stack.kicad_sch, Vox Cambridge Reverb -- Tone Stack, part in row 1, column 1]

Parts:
C_byp3: 100nF; C_Disc_D7.5mm_W2.5mm_P5.00mm
C_gg: 2.2nF; C_Disc_D7.5mm_W2.5mm_P5.00mm
C_j1, C_j2: 22nF; C_Disc_D7.5mm_W2.5mm_P5.00mm
C_j3, C_j4: 2.2nF; C_Disc_D7.5mm_W2.5mm_P5.00mm
C_res: 22nF; C_Disc_D7.5mm_W2.5mm_P5.00mm
C_tout: 1uF; C_Disc_D7.5mm_W2.5mm_P5.00mm
C_treble: 470pF; C_Disc_D7.5mm_W2.5mm_P5.00mm
C_vb3: 47uF/25V; CP_Radial_D6.3mm_P2.50mm
IC3: TL074CN; DIP-14_W7.62mm
POT_BASS: 250k lin; WirePad_1x03_P2.54mm_D1.2mm
POT_TREB: 250k lin; WirePad_1x03_P2.54mm_D1.2mm
POT_VOL: 250k log; WirePad_1x03_P2.54mm_D1.2mm
R_fx_pad: 10k; R_Axial_DIN0207_L6.3mm_D2.5mm_P5.08mm_Vertical
R_gL: 4.7k; R_Axial_DIN0207_L6.3mm_D2.5mm_P5.08mm_Vertical
R_gg: 180k; R_Axial_DIN0207_L6.3mm_D2.5mm_P5.08mm_Vertical
R_inb: 1M; R_Axial_DIN0207_L6.3mm_D2.5mm_P5.08mm_Vertical
R_j1, R_j2: 10k; R_Axial_DIN0207_L6.3mm_D2.5mm_P5.08mm_Vertical
R_j3: 68k; R_Axial_DIN0207_L6.3mm_D2.5mm_P5.08mm_Vertical
R_j4: 1k; R_Axial_DIN0207_L6.3mm_D2.5mm_P5.08mm_Vertical
R_mid: 10k; R_Axial_DIN0207_L6.3mm_D2.5mm_P5.08mm_Vertical
R_mk1, R_mk2: 10k; R_Axial_DIN0207_L6.3mm_D2.5mm_P5.08mm_Vertical
R_vb31, R_vb32: 100k; R_Axial_DIN0207_L6.3mm_D2.5mm_P5.08mm_Vertical
SW_MID: MID CUT; WirePad_1x02_P2.54mm_D1.2mm
TP_MK_OUT: TMK; TestPoint_THT_D2.0mm_Label
TP_TONE_OUT: TONE; TestPoint_THT_D2.0mm_Label
TP_VBIAS_3: VB_3; TestPoint_THT_D2.0mm_Label

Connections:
+17V: C_byp3.1, IC3.4 (V+), R_vb31.1; also elsewhere on the board
BUF: C_j3.1, IC3.1 (OUT1), IC3.2 (IN1-), R_j1.1
FX_RET: R_fx_pad.2; also elsewhere on the board
GND: C_byp3.2, C_vb3.2, IC3.11 (V-), POT_VOL.3, R_vb32.2; also elsewhere on the board
GYA: C_gg.1, C_res.2, R_gL.1
GYO: IC3.8 (OUT3), IC3.9 (IN3-), R_gL.2
GYP: C_gg.2, IC3.10 (IN3+), R_gg.1
JA: C_j1.1, POT_BASS.3, R_j1.2
JB: C_j2.2, POT_BASS.1, R_j2.1
JOUT: IC3.5 (IN2+), R_j3.2, R_j4.2
JTA: C_j3.2, POT_TREB.3
JTB: C_j4.1, POT_TREB.1
JWB: C_j1.2, C_j2.1, POT_BASS.2 (W), R_j3.1
JWT: POT_TREB.2 (W), R_j4.1
MID: IC3.12 (IN4+), R_mid.2, SW_MID.1
MIDSW: C_res.1, SW_MID.2
MKN: IC3.6 (IN2-), R_mk1.2, R_mk2.1
MK_OUT: IC3.7 (OUT2), R_mid.1, R_mk1.1, TP_MK_OUT.1
OBUF: C_tout.1, IC3.13 (IN4-), IC3.14 (OUT4)
PREAMP_OUT: IC3.3 (IN1+), R_inb.1; also elsewhere on the board
TONE_OUT: C_treble.2, POT_VOL.2 (W), R_fx_pad.1, TP_TONE_OUT.1; also elsewhere on the board
VBIAS_3: C_j4.2, C_vb3.1 (+), R_gg.2, R_inb.2, R_j2.2, R_mk2.2, R_vb31.2, R_vb32.1, TP_VBIAS_3.1
VOLTOP: C_tout.2, C_treble.1, POT_VOL.1

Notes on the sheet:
TONE -- IC3 TL074. A: input buffer. PASSIVE JAMES bass/treble network (the Thomas-Vox topology: panel Bass + Treble pots; ~flat at noon with a slight bright tilt, bass +-6 dB @100 Hz, treble +6/-16 dB @10 kHz -- more cut than boost, as the originals). B: make-up gain x2 (network loss). C: gyrator M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
TEST POINTS -- header pin or wire loop; silk label = net alias (see PCB-NOTES.md for expected values)

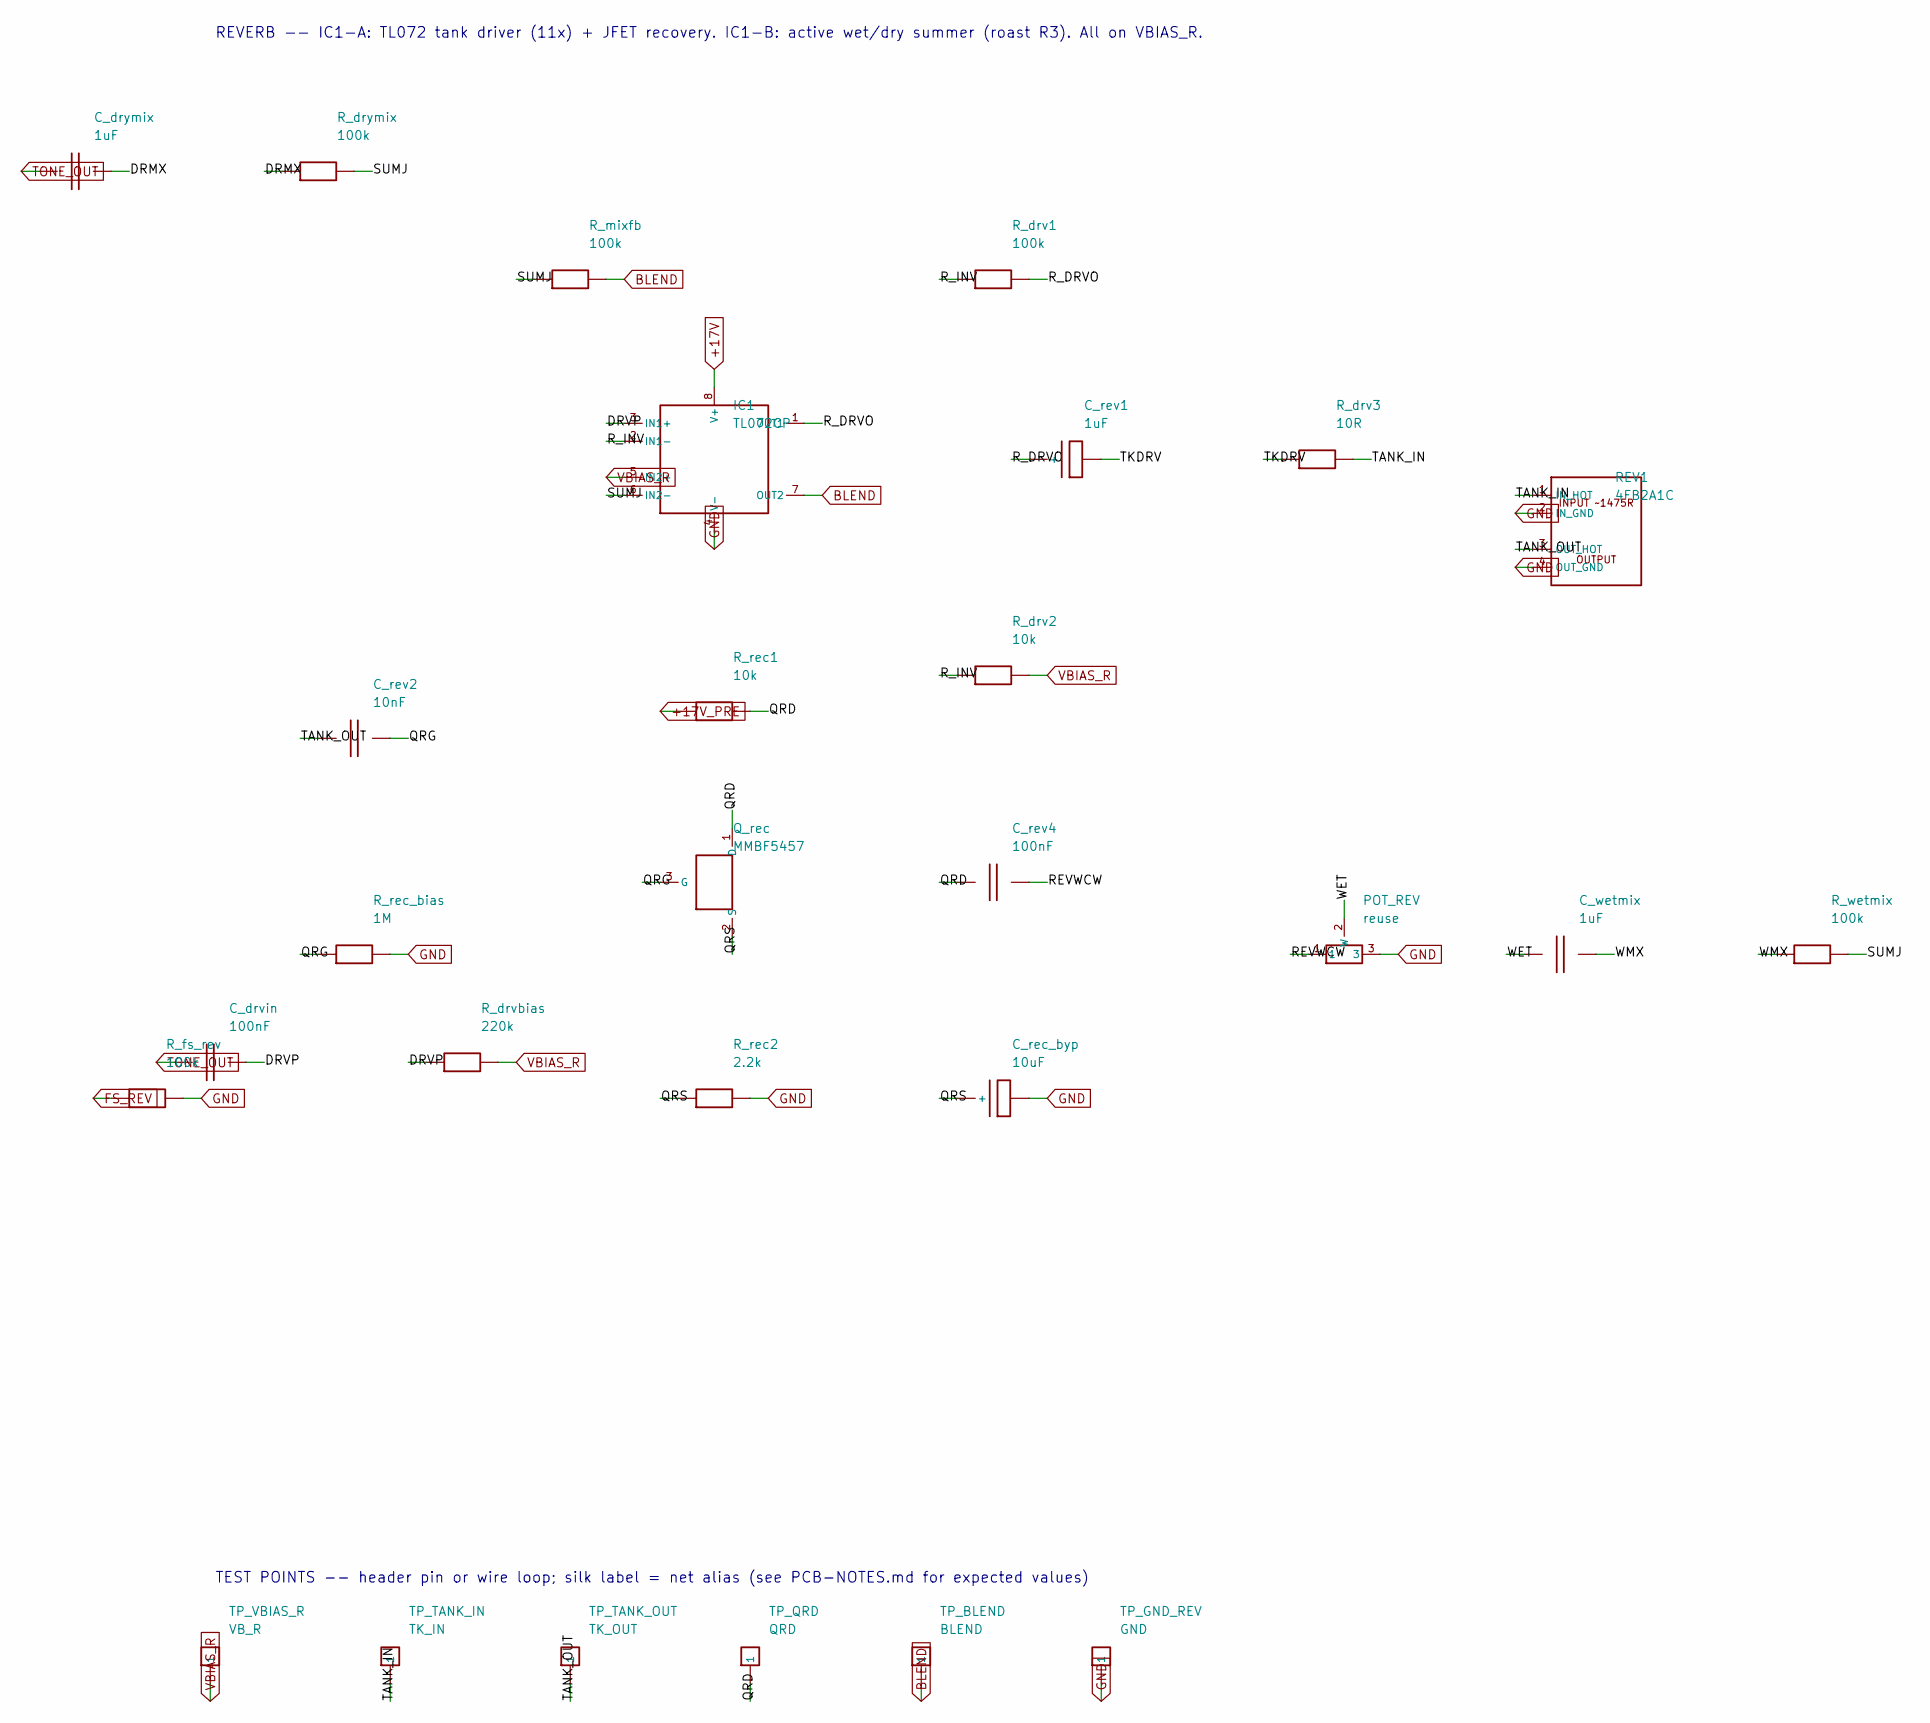
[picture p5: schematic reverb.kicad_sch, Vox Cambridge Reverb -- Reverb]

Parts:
C_drvin: 100nF; C_Disc_D7.5mm_W2.5mm_P5.00mm
C_drymix: 1uF; C_Disc_D7.5mm_W2.5mm_P5.00mm
C_rec_byp: 10uF; CP_Radial_D5.0mm_P2.00mm
C_rev1: 1uF; CP_Radial_D5.0mm_P2.00mm
C_rev2: 10nF; C_Disc_D7.5mm_W2.5mm_P5.00mm
C_rev4: 100nF; C_Disc_D7.5mm_W2.5mm_P5.00mm
C_wetmix: 1uF; C_Disc_D7.5mm_W2.5mm_P5.00mm
IC1: TL072CP; DIP-8_W7.62mm
POT_REV: reuse; WirePad_1x03_P2.54mm_D1.2mm
Q_rec: MMBF5457; TO-92_Inline_Wide
REV1: 4FB2A1C; WirePad_1x04_P2.54mm_D1.2mm
R_drv1: 100k; R_Axial_DIN0207_L6.3mm_D2.5mm_P5.08mm_Vertical
R_drv2: 10k; R_Axial_DIN0207_L6.3mm_D2.5mm_P5.08mm_Vertical
R_drv3: 10R; R_Axial_DIN0207_L6.3mm_D2.5mm_P5.08mm_Vertical
R_drvbias: 220k; R_Axial_DIN0207_L6.3mm_D2.5mm_P5.08mm_Vertical
R_drymix: 100k; R_Axial_DIN0207_L6.3mm_D2.5mm_P5.08mm_Vertical
R_fs_rev: 100k; R_Axial_DIN0207_L6.3mm_D2.5mm_P5.08mm_Vertical
R_mixfb: 100k; R_Axial_DIN0207_L6.3mm_D2.5mm_P5.08mm_Vertical
R_rec1: 10k; R_Axial_DIN0207_L6.3mm_D2.5mm_P5.08mm_Vertical
R_rec2: 2.2k; R_Axial_DIN0207_L6.3mm_D2.5mm_P5.08mm_Vertical
R_rec_bias: 1M; R_Axial_DIN0207_L6.3mm_D2.5mm_P5.08mm_Vertical
R_wetmix: 100k; R_Axial_DIN0207_L6.3mm_D2.5mm_P5.08mm_Vertical
TP_BLEND: BLEND; TestPoint_THT_D2.0mm_Label
TP_GND_REV: GND; TestPoint_THT_D2.0mm_Label
TP_QRD: QRD; TestPoint_THT_D2.0mm_Label
TP_TANK_IN: TK_IN; TestPoint_THT_D2.0mm_Label
TP_TANK_OUT: TK_OUT; TestPoint_THT_D2.0mm_Label
TP_VBIAS_R: VB_R; TestPoint_THT_D2.0mm_Label

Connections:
+17V: IC1.8 (V+); also elsewhere on the board
+17V_PRE: R_rec1.1; also elsewhere on the board
BLEND: IC1.7 (OUT2), R_mixfb.2, TP_BLEND.1; also elsewhere on the board
DRMX: C_drymix.2, R_drymix.1
DRVP: C_drvin.2, IC1.3 (IN1+), R_drvbias.1
FS_REV: R_fs_rev.1; also elsewhere on the board
GND: C_rec_byp.2, IC1.4 (V-), POT_REV.3, REV1.2 (IN_GND), REV1.4 (OUT_GND), R_fs_rev.2, R_rec2.2, R_rec_bias.2, TP_GND_REV.1; also elsewhere on the board
QRD: C_rev4.1, Q_rec.1 (D), R_rec1.2, TP_QRD.1
QRG: C_rev2.2, Q_rec.3 (G), R_rec_bias.1
QRS: C_rec_byp.1 (+), Q_rec.2 (S), R_rec2.1
REVWCW: C_rev4.2, POT_REV.1
R_DRVO: C_rev1.1 (+), IC1.1 (OUT1), R_drv1.2
R_INV: IC1.2 (IN1-), R_drv1.1, R_drv2.1
SUMJ: IC1.6 (IN2-), R_drymix.2, R_mixfb.1, R_wetmix.2
TANK_IN: REV1.1 (IN_HOT), R_drv3.2, TP_TANK_IN.1
TANK_OUT: C_rev2.1, REV1.3 (OUT_HOT), TP_TANK_OUT.1
TKDRV: C_rev1.2, R_drv3.1
TONE_OUT: C_drvin.1, C_drymix.1; also elsewhere on the board
VBIAS_R: IC1.5 (IN2+), R_drv2.2, R_drvbias.2, TP_VBIAS_R.1; also elsewhere on the board
WET: C_wetmix.1, POT_REV.2 (W)
WMX: C_wetmix.2, R_wetmix.1

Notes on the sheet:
REVERB -- IC1-A: TL072 tank driver (11x) + JFET recovery. IC1-B: active wet/dry summer (roast R3). All on VBIAS_R.
TEST POINTS -- header pin or wire loop; silk label = net alias (see PCB-NOTES.md for expected values)

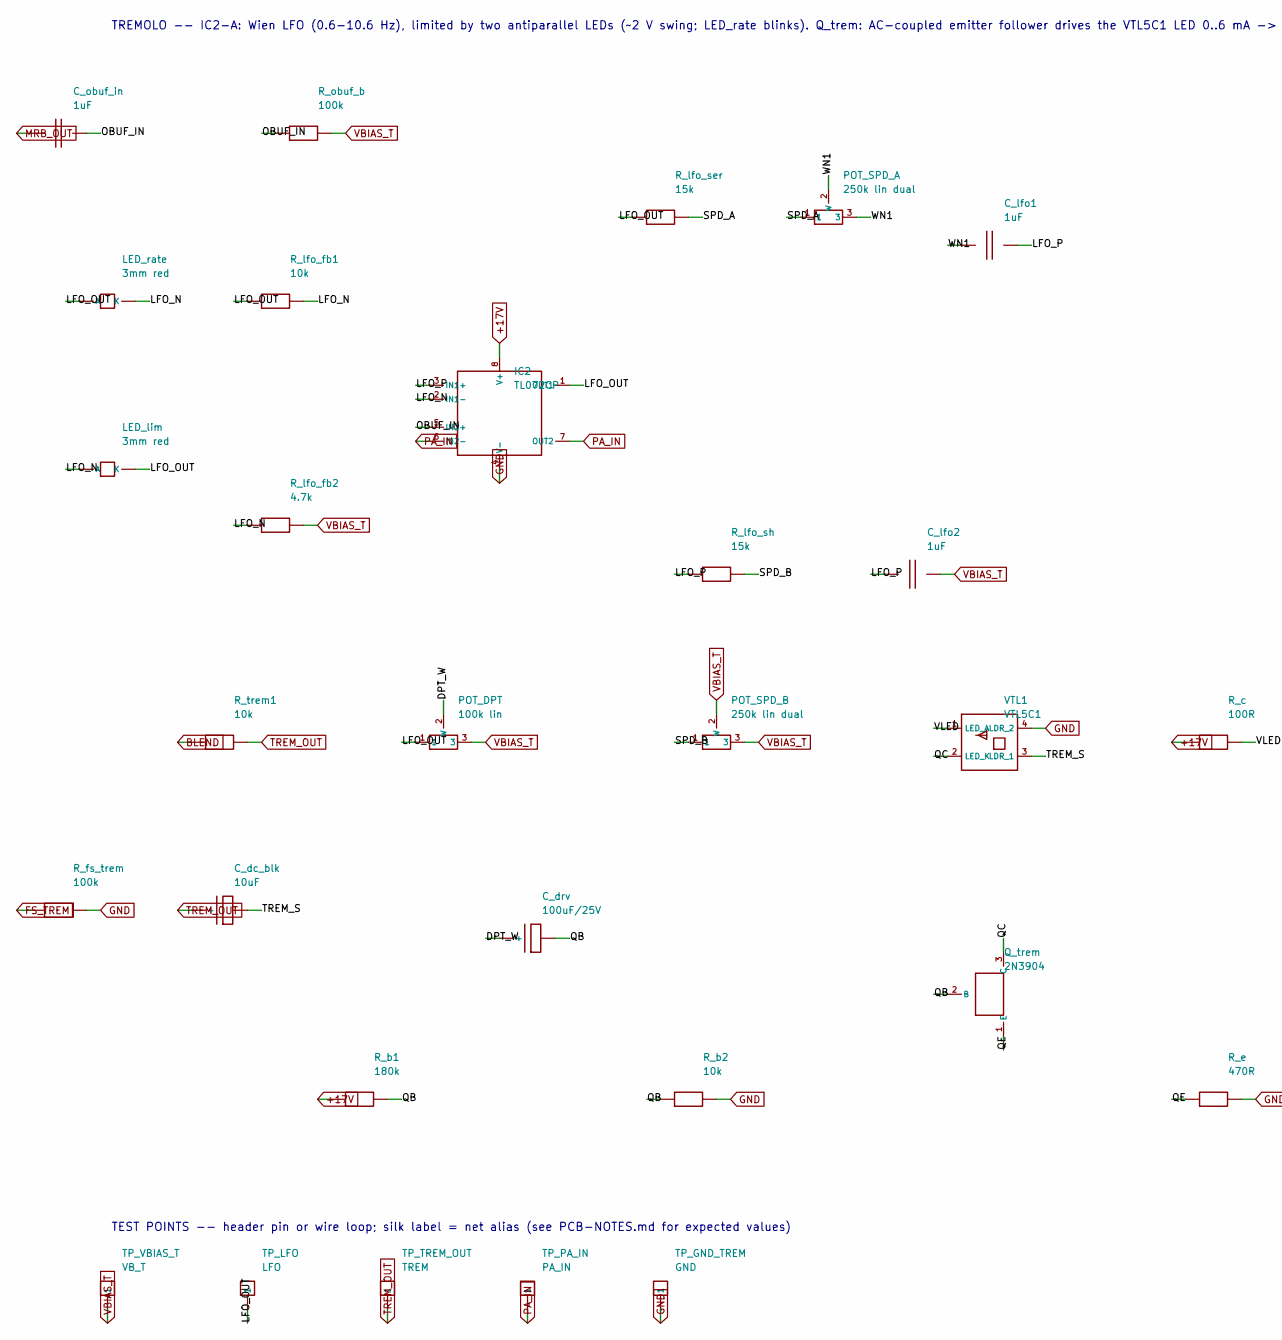
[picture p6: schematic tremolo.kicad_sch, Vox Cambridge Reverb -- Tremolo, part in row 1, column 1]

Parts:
C_dc_blk: 10uF; CP_Radial_D5.0mm_P2.00mm
C_drv: 100uF/25V; CP_Radial_D6.3mm_P2.50mm
C_lfo1, C_lfo2: 1uF; C_Disc_D7.5mm_W2.5mm_P5.00mm
C_obuf_in: 1uF; C_Disc_D7.5mm_W2.5mm_P5.00mm
IC2: TL072CP; DIP-8_W7.62mm
LED_lim: 3mm red; LED_D3.0mm
LED_rate: 3mm red; LED_D3.0mm
POT_DPT: 100k lin; WirePad_1x03_P2.54mm_D1.2mm
POT_SPD_A: 250k lin dual; WirePad_1x03_P2.54mm_D1.2mm
POT_SPD_B: 250k lin dual; WirePad_1x03_P2.54mm_D1.2mm
Q_trem: 2N3904; TO-92_Inline_Wide
R_b1: 180k; R_Axial_DIN0207_L6.3mm_D2.5mm_P5.08mm_Vertical
R_b2: 10k; R_Axial_DIN0207_L6.3mm_D2.5mm_P5.08mm_Vertical
R_c: 100R; R_Axial_DIN0207_L6.3mm_D2.5mm_P5.08mm_Vertical
R_e: 470R; R_Axial_DIN0207_L6.3mm_D2.5mm_P5.08mm_Vertical
R_fs_trem: 100k; R_Axial_DIN0207_L6.3mm_D2.5mm_P5.08mm_Vertical
R_lfo_fb1: 10k; R_Axial_DIN0207_L6.3mm_D2.5mm_P5.08mm_Vertical
R_lfo_fb2: 4.7k; R_Axial_DIN0207_L6.3mm_D2.5mm_P5.08mm_Vertical
R_lfo_ser: 15k; R_Axial_DIN0207_L6.3mm_D2.5mm_P5.08mm_Vertical
R_lfo_sh: 15k; R_Axial_DIN0207_L6.3mm_D2.5mm_P5.08mm_Vertical
R_obuf_b: 100k; R_Axial_DIN0207_L6.3mm_D2.5mm_P5.08mm_Vertical
R_trem1: 10k; R_Axial_DIN0207_L6.3mm_D2.5mm_P5.08mm_Vertical
TP_GND_TREM: GND; TestPoint_THT_D2.0mm_Label
TP_LFO: LFO; TestPoint_THT_D2.0mm_Label
TP_PA_IN: PA_IN; TestPoint_THT_D2.0mm_Label
TP_TREM_OUT: TREM; TestPoint_THT_D2.0mm_Label
TP_VBIAS_T: VB_T; TestPoint_THT_D2.0mm_Label
VTL1: VTL5C1

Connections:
+17V: IC2.8 (V+), R_b1.1, R_c.1; also elsewhere on the board
BLEND: R_trem1.1; also elsewhere on the board
DPT_W: C_drv.1 (+), POT_DPT.2 (W)
FS_TREM: R_fs_trem.1; also elsewhere on the board
GND: IC2.4 (V-), R_b2.2, R_e.2, R_fs_trem.2, TP_GND_TREM.1, VTL1.4 (LDR_2); also elsewhere on the board
LFO_N: IC2.2 (IN1-), LED_lim.1 (A), LED_rate.2 (K), R_lfo_fb1.2, R_lfo_fb2.1
LFO_OUT: IC2.1 (OUT1), LED_lim.2 (K), LED_rate.1 (A), POT_DPT.1, R_lfo_fb1.1, R_lfo_ser.1, TP_LFO.1
LFO_P: C_lfo1.2, C_lfo2.1, IC2.3 (IN1+), R_lfo_sh.1
MRB_OUT: C_obuf_in.1; also elsewhere on the board
OBUF_IN: C_obuf_in.2, IC2.5 (IN2+), R_obuf_b.1
PA_IN: IC2.6 (IN2-), IC2.7 (OUT2), TP_PA_IN.1; also elsewhere on the board
QB: C_drv.2, Q_trem.2 (B), R_b1.2, R_b2.1
QC: Q_trem.3 (C), VTL1.2 (LED_K)
QE: Q_trem.1 (E), R_e.1
SPD_A: POT_SPD_A.1, R_lfo_ser.2
SPD_B: POT_SPD_B.1, R_lfo_sh.2
TREM_OUT: C_dc_blk.1 (+), R_trem1.2, TP_TREM_OUT.1; also elsewhere on the board
TREM_S: C_dc_blk.2, VTL1.3 (LDR_1)
VBIAS_T: C_lfo2.2, POT_DPT.3, POT_SPD_B.2 (W), POT_SPD_B.3, R_lfo_fb2.2, R_obuf_b.2, TP_VBIAS_T.1; also elsewhere on the board
VLED: R_c.2, VTL1.1 (LED_A)
WN1: C_lfo1.1, POT_SPD_A.2 (W), POT_SPD_A.3

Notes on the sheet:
TREMOLO -- IC2-A: Wien LFO (0.6-10.6 Hz), limited by two antiparallel LEDs (~2 V swing; LED_rate blinks). Q_trem: AC-coupled emitter follower drives the VTL5C1 LED 0..6 mA -> 15 dB depth, 0.8 dB insertion loss (was 7 mA DC: -20 dB pad, 1.7 dB depth). IC2-B: post-MRB output buffer -> PA_IN.
TEST POINTS -- header pin or wire loop; silk label = net alias (see PCB-NOTES.md for expected values)

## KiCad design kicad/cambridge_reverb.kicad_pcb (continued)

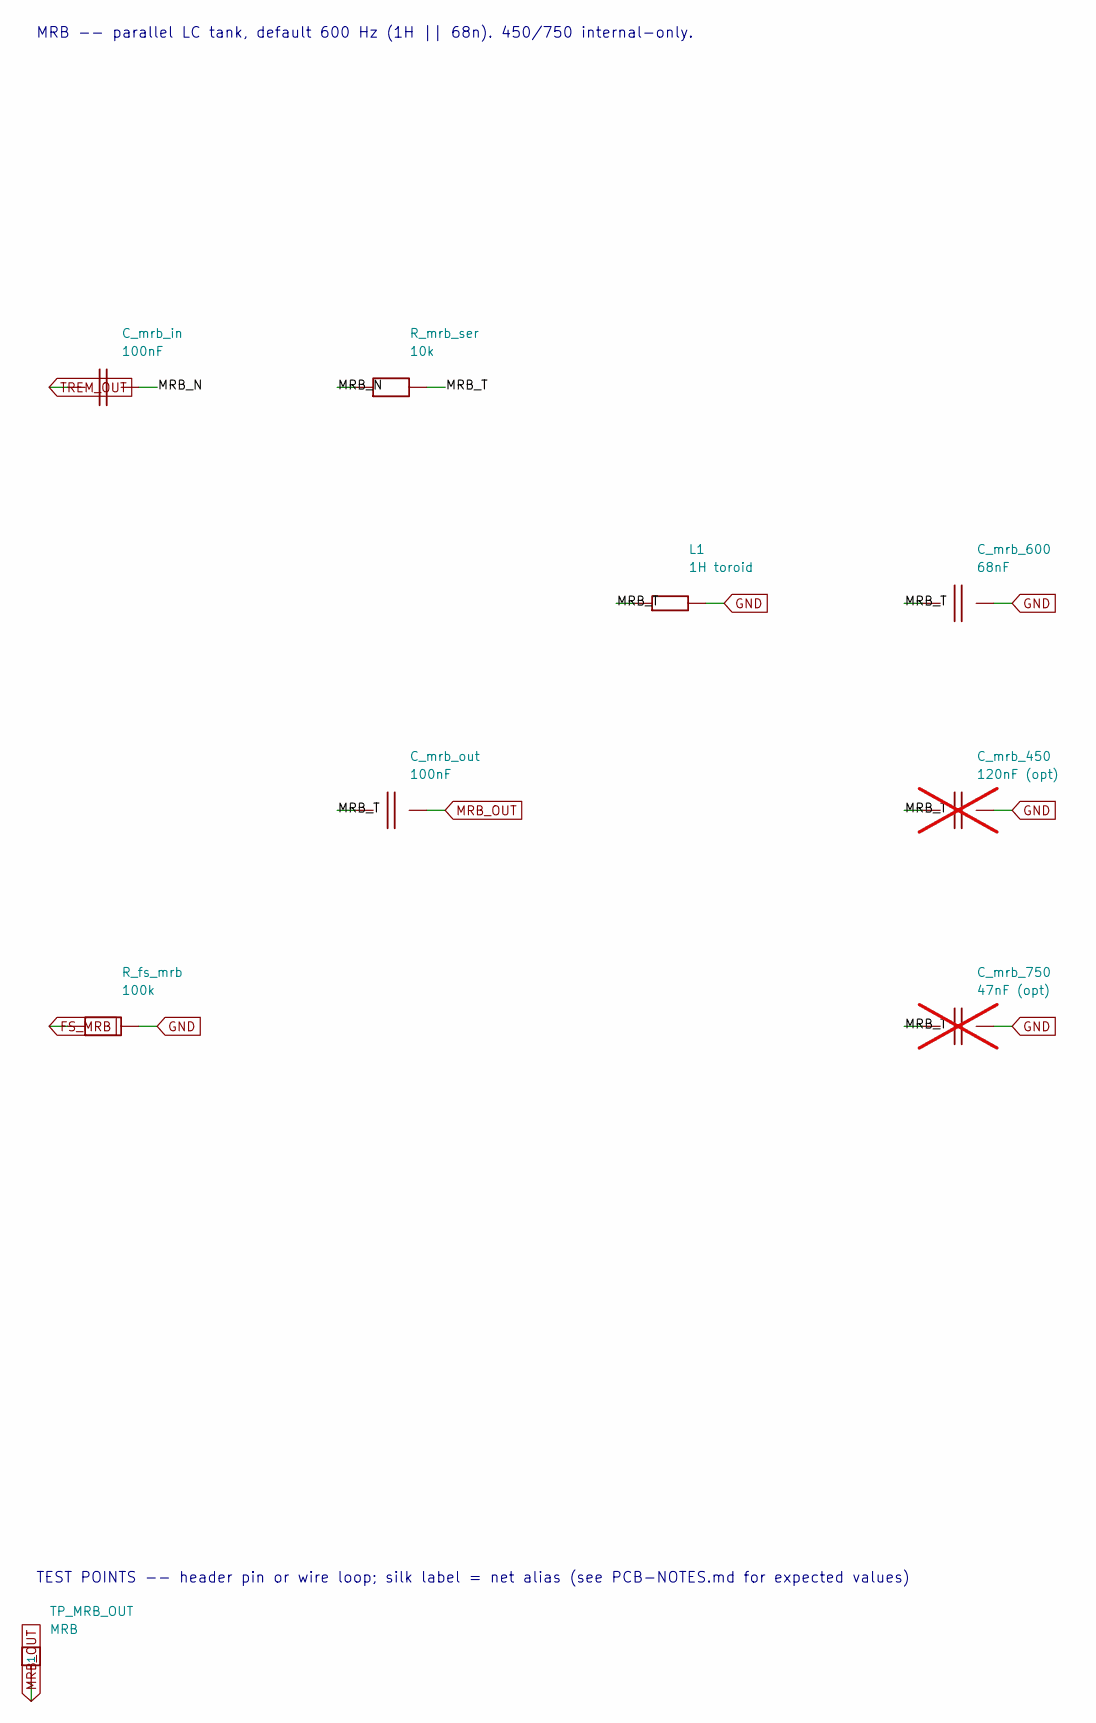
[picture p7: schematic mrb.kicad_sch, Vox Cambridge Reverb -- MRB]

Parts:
C_mrb_450: 120nF (opt); C_Disc_D7.5mm_W2.5mm_P5.00mm; not fitted
C_mrb_600: 68nF; C_Disc_D7.5mm_W2.5mm_P5.00mm
C_mrb_750: 47nF (opt); C_Disc_D7.5mm_W2.5mm_P5.00mm; not fitted
C_mrb_in: 100nF; C_Disc_D7.5mm_W2.5mm_P5.00mm
C_mrb_out: 100nF; C_Disc_D7.5mm_W2.5mm_P5.00mm
L1: 1H toroid; Inductor_MRB_1H_Toroid
R_fs_mrb: 100k; R_Axial_DIN0207_L6.3mm_D2.5mm_P5.08mm_Vertical
R_mrb_ser: 10k; R_Axial_DIN0207_L6.3mm_D2.5mm_P5.08mm_Vertical
TP_MRB_OUT: MRB; TestPoint_THT_D2.0mm_Label

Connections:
FS_MRB: R_fs_mrb.1; also elsewhere on the board
GND: C_mrb_450.2, C_mrb_600.2, C_mrb_750.2, L1.2, R_fs_mrb.2; also elsewhere on the board
MRB_N: C_mrb_in.2, R_mrb_ser.1
MRB_OUT: C_mrb_out.2, TP_MRB_OUT.1; also elsewhere on the board
MRB_T: C_mrb_450.1, C_mrb_600.1, C_mrb_750.1, C_mrb_out.1, L1.1, R_mrb_ser.2
TREM_OUT: C_mrb_in.1; also elsewhere on the board

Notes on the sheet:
MRB -- parallel LC tank, default 600 Hz (1H || 68n). 450/750 internal-only.
TEST POINTS -- header pin or wire loop; silk label = net alias (see PCB-NOTES.md for expected values)

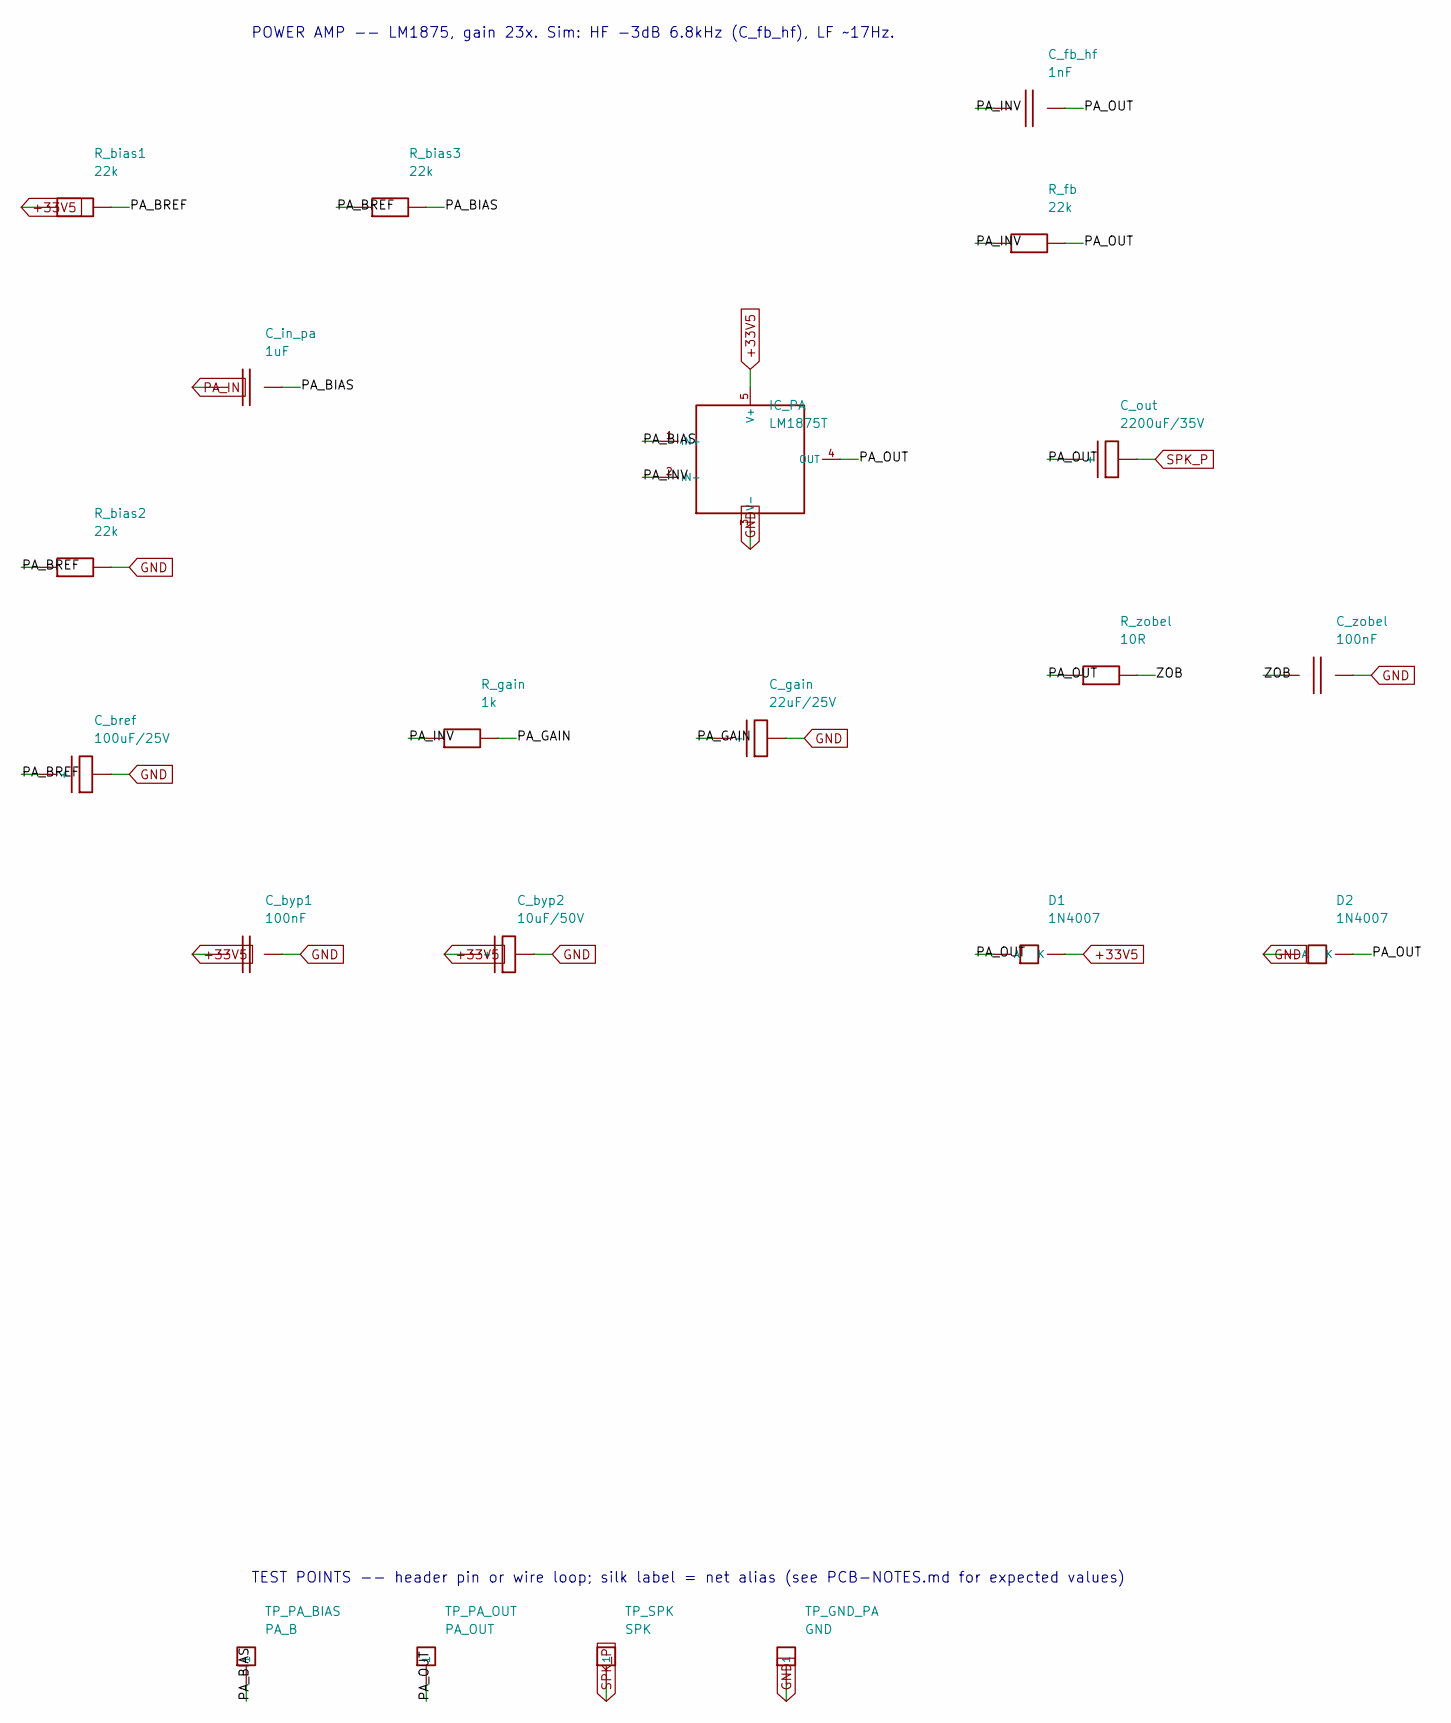
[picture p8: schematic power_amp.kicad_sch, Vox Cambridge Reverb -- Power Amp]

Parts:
C_bref: 100uF/25V; CP_Radial_D6.3mm_P2.50mm
C_byp1: 100nF; C_Disc_D7.5mm_W2.5mm_P5.00mm
C_byp2: 10uF/50V; CP_Radial_D5.0mm_P2.00mm
C_fb_hf: 1nF; C_Disc_D7.5mm_W2.5mm_P5.00mm
C_gain: 22uF/25V; CP_Radial_D5.0mm_P2.00mm
C_in_pa: 1uF; C_Disc_D7.5mm_W2.5mm_P5.00mm
C_out: 2200uF/35V; CP_Radial_D16.0mm_P7.50mm
C_zobel: 100nF; C_Disc_D7.5mm_W2.5mm_P5.00mm
D1, D2: 1N4007; D_DO-41_SOD81_P10.16mm_Horizontal
IC_PA: LM1875T; TO-220-5_Vertical_P1.70mm_LM1875
R_bias1, R_bias2, R_bias3: 22k; R_Axial_DIN0207_L6.3mm_D2.5mm_P5.08mm_Vertical
R_fb: 22k; R_Axial_DIN0207_L6.3mm_D2.5mm_P5.08mm_Vertical
R_gain: 1k; R_Axial_DIN0207_L6.3mm_D2.5mm_P5.08mm_Vertical
R_zobel: 10R; R_Axial_DIN0207_L6.3mm_D2.5mm_P5.08mm_Vertical
TP_GND_PA: GND; TestPoint_THT_D2.0mm_Label
TP_PA_BIAS: PA_B; TestPoint_THT_D2.0mm_Label
TP_PA_OUT: PA_OUT; TestPoint_THT_D2.0mm_Label
TP_SPK: SPK; TestPoint_THT_D2.0mm_Label

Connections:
+33V5: C_byp1.1, C_byp2.1 (+), D1.2 (K), IC_PA.5 (V+), R_bias1.1; also elsewhere on the board
GND: C_bref.2, C_byp1.2, C_byp2.2, C_gain.2, C_zobel.2, D2.1 (A), IC_PA.3 (V-), R_bias2.2, TP_GND_PA.1; also elsewhere on the board
PA_BIAS: C_in_pa.2, IC_PA.1 (IN+), R_bias3.2, TP_PA_BIAS.1
PA_BREF: C_bref.1 (+), R_bias1.2, R_bias2.1, R_bias3.1
PA_GAIN: C_gain.1 (+), R_gain.2
PA_IN: C_in_pa.1; also elsewhere on the board
PA_INV: C_fb_hf.1, IC_PA.2 (IN-), R_fb.1, R_gain.1
PA_OUT: C_fb_hf.2, C_out.1 (+), D1.1 (A), D2.2 (K), IC_PA.4 (OUT), R_fb.2, R_zobel.1, TP_PA_OUT.1
SPK_P: C_out.2, TP_SPK.1; also elsewhere on the board
ZOB: C_zobel.1, R_zobel.2

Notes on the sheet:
POWER AMP -- LM1875, gain 23x. Sim: HF -3dB 6.8kHz (C_fb_hf), LF ~17Hz.
TEST POINTS -- header pin or wire loop; silk label = net alias (see PCB-NOTES.md for expected values)

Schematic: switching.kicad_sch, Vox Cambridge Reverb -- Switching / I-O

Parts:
FS1: DIN-6; WirePad_1x06_P2.54mm_D1.2mm
J_IN1: Input 1; WirePad_1x02_P2.54mm_D1.2mm
J_IN2: Input 2; WirePad_1x02_P2.54mm_D1.2mm
J_IN3: IN3 / FX return; WirePad_1x02_P2.54mm_D1.2mm
LS1: 10in Bulldog; WirePad_1x02_P5.08mm_D1.5mm
R_spk_rtn: 0R; R_Axial_DIN0414_L11.9mm_D4.5mm_P15.24mm_Horizontal

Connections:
FS_MRB: FS1.3 (FS_MRB); also elsewhere on the board
FS_REV: FS1.1 (FS_REV); also elsewhere on the board
FS_TREM: FS1.2 (FS_TREM); also elsewhere on the board
FX_RET: J_IN3.1 (T); also elsewhere on the board
GND: FS1.4 (FS_GND), FS1.5 (NC5), FS1.6 (NC6), J_IN1.2 (S), J_IN2.2 (S), J_IN3.2 (S), R_spk_rtn.2; also elsewhere on the board
GUITAR_IN: J_IN1.1 (T), J_IN2.1 (T); also elsewhere on the board
SPK_N: LS1.2 (-), R_spk_rtn.1
SPK_P: LS1.1 (+); also elsewhere on the board

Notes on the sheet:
SWITCHING / I-O -- input jacks (IN3=internal FX loop), footswitch DIN, speaker.

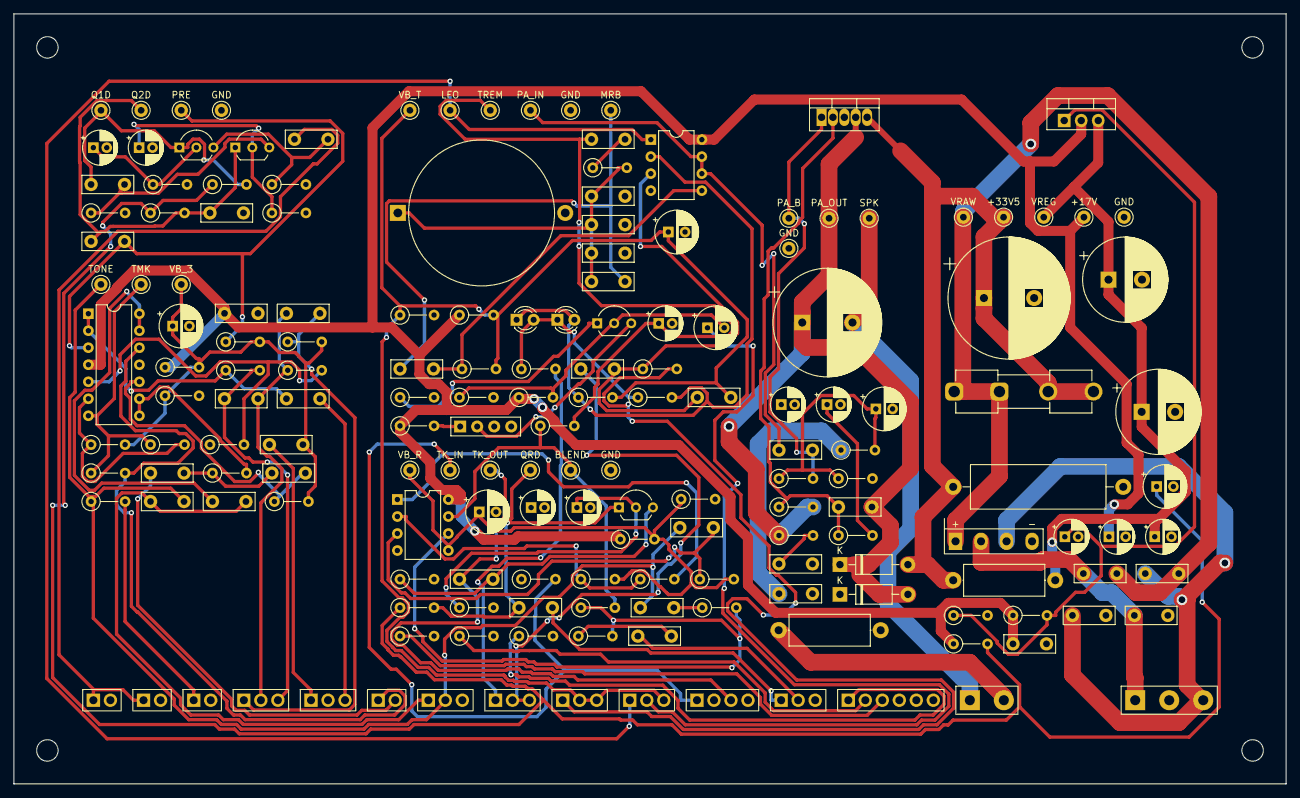
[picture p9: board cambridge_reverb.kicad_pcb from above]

Board: 2 copper layers, 190.0 x 115.0 mm, 178 parts (0 on the bottom side), 83 nets.

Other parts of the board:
H1, H2, H3, H4: MountingHole_3.2mm_M3

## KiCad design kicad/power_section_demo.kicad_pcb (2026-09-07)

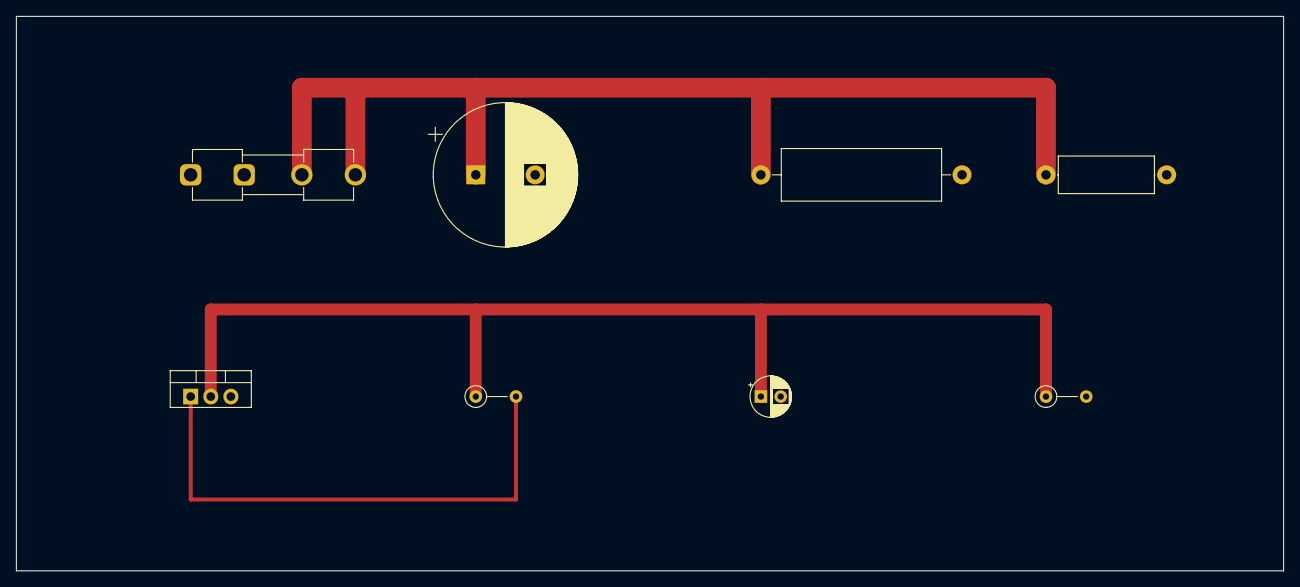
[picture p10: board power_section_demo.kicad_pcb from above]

Board: 2 copper layers, 160.0 x 70.0 mm, 8 parts (0 on the bottom side), 5 nets.

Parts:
C_main: 4700uF/50V; CP_Radial_D18.0mm_P7.50mm
C_reg_out1: 10uF/25V; CP_Radial_D5.0mm_P2.50mm
F1: 1A SB; Fuseholder_Clip-5x20mm_Eaton_1A5601-01_Inline_P20.80x6.76mm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
R_27V: 100R/1W; R_Axial_DIN0414_L11.9mm_D4.5mm_P15.24mm_Horizontal
R_bleed: 10k/5W; R_Axial_Power_L20.0mm_W6.4mm_P25.40mm
R_reg1: 240R; R_Axial_DIN0207_L6.3mm_D2.5mm_P5.08mm_Vertical
R_vbr1: 100k; R_Axial_DIN0207_L6.3mm_D2.5mm_P5.08mm_Vertical
U1: LM317T; TO-220-3_Vertical

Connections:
+17V: C_reg_out1.1, R_reg1.1, R_vbr1.1, U1.2
+33V5: C_main.1, F1.2, R_27V.1, R_bleed.1
ADJ17: R_reg1.2, U1.1
GND: C_main.2, C_reg_out1.2, R_bleed.2
VREG_IN: R_27V.2, U1.3

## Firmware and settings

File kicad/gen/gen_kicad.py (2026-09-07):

#!/usr/bin/env python3
"""Generate the Vox Cambridge Reverb KiCad 7 hierarchical schematic.

Self-contained: defines primitive symbols (cr_primitives.kicad_sym) with known
pin geometry, then emits a root sheet + 8 sub-sheets wired with labels.
Connectivity uses a short wire stub from each pin endpoint to a label
(global_label for cross-sheet/rail nets, local label otherwise) -- robust and
ERC-clean without fragile wire routing. Validated with `kicad-cli sch erc`.

Symbol-lib coords are y-up; schematic is y-down, so pin endpoints map as
(Px+ex, Py-ey).  Run from repo root:  python3 kicad/gen/gen_kicad.py
"""
import uuid, os, math

ROOT = os.path.join(os.path.dirname(__file__), "..")

# Build PROFILE: "tht" (the primary, all through-hole board, written to kicad/) or
# "smd" (the mixed variant: small passives + small semis on SMD footprints, power
# parts / cans / connectors / op-amps stay THT; written to kicad/smd/). One
# schematic source, two footprint maps -- set with set_profile() before build().
PROFILE = os.environ.get("CR_PROFILE", "tht")
OUTDIR = ROOT
def set_profile(profile):
    global PROFILE, OUTDIR
    assert profile in ("tht", "smd"), profile
    PROFILE = profile
    OUTDIR = ROOT if profile == "tht" else os.path.join(ROOT, "smd")
    os.makedirs(OUTDIR, exist_ok=True)
set_profile(PROFILE)

def U(): return str(uuid.uuid4())
def SNAP(v): return round(round(v / 1.27) * 1.27, 4)   # snap to 50-mil grid

import re as _re
def NV(v):
    """Normalize a value string for a tidy/consolidated BOM (cosmetic only):
    drop the ' film' descriptor (footprint conveys it) and standardize resistor
    k-notation (2K2 -> 2.2k, 4K7 -> 4.7k, 100K -> 100k)."""
    s = v.strip().replace(" film", "")
    m = _re.fullmatch(r'(\d+)K(\d+)', s)
    if m: return f"{m.group(1)}.{m.group(2)}k"
    if _re.fullmatch(r'\d+K', s): return s[:-1] + "k"
    return s

# ----------------------------------------------------------------------------
# Primitive symbol database.
# pins: (number, name, ex, ey, ox, oy)  in SYMBOL (y-up) coords.
#   (ex,ey) = connection endpoint; (ox,oy) = outward unit vector.
# body: list of rectangles (x1,y1,x2,y2) drawn for looks (y-up).
# ----------------------------------------------------------------------------
def ang(ox, oy):
    # pin graphic is drawn from endpoint toward body = opposite of outward
    if (ox, oy) == (-1, 0): return 0
    if (ox, oy) == (1, 0):  return 180
    if (ox, oy) == (0, 1):  return 270
    if (ox, oy) == (0, -1): return 90
    raise ValueError((ox, oy))

SYMS = {
 "R":  dict(ref="R", desc="Resistor", hide_nums=True,
            pins=[("1","~",-5.08,0,-1,0),("2","~",5.08,0,1,0)],
            body=[(-2.54,-1.27,2.54,1.27)]),
 "C":  dict(ref="C", desc="Unpolarized capacitor", hide_nums=True,
            pins=[("1","~",-5.08,0,-1,0),("2","~",5.08,0,1,0)],
            body=[(-0.5,-2.54,-0.5,2.54),(0.5,-2.54,0.5,2.54)]),
 "CP": dict(ref="C", desc="Polarized capacitor (pin1 +)", hide_nums=True,
            pins=[("1","+",-5.08,0,-1,0),("2","~",5.08,0,1,0)],
            body=[(-0.5,-2.54,-0.5,2.54),(0.6,-2.54,2.4,2.54)]),
 "L":  dict(ref="L", desc="Inductor", hide_nums=True,
            pins=[("1","~",-5.08,0,-1,0),("2","~",5.08,0,1,0)],
            body=[(-2.54,-1.0,2.54,1.0)]),
 "D":  dict(ref="D", desc="Diode (1=A 2=K)", hide_nums=True,
            pins=[("1","A",-5.08,0,-1,0),("2","K",5.08,0,1,0)],
            body=[(-1.27,-1.27,1.27,1.27)]),
 "LED":dict(ref="D", desc="LED (1=A 2=K)", hide_nums=True,
            pins=[("1","A",-5.08,0,-1,0),("2","K",5.08,0,1,0)],
            body=[(-1.27,-1.27,1.27,1.27)]),
 "FUSE":dict(ref="F", desc="Fuse", hide_nums=True,
            pins=[("1","~",-5.08,0,-1,0),("2","~",5.08,0,1,0)],
            body=[(-2.54,-1.0,2.54,1.0)]),
 "POT":dict(ref="RV", desc="Potentiometer (1,3 ends; 2 wiper)", hide_nums=False,
            pins=[("1","1",-5.08,0,-1,0),("3","3",5.08,0,1,0),("2","W",0,5.08,0,1)],
            body=[(-2.54,-1.27,2.54,1.27)]),
 # pin numbers follow the onsemi 2N5457 (TO-92) AND MMBF5457 (SOT-23) datasheets:
 # 1 = Drain, 2 = Source, 3 = Gate. (Before 2026-09 the symbol had 2 = G / 3 = S,
 # which on a real TO-92 2N5457 wires the gate to the source lead -- errata #18.)
 "NJFET":dict(ref="Q", desc="N-channel JFET (1=D 2=S 3=G, onsemi 2N5457/MMBF5457)", hide_nums=False,
            pins=[("3","G",-7.62,0,-1,0),("1","D",2.54,7.62,0,1),("2","S",2.54,-7.62,0,-1)],
            body=[(-2.54,-3.81,2.54,3.81)]),
 "NPN":dict(ref="Q", desc="NPN BJT (1=E 2=B 3=C: onsemi 2N3904 TO-92; MMBT3904 goes on the EBC-renumbered SOT-23)", hide_nums=False,
            pins=[("2","B",-7.62,0,-1,0),("3","C",2.54,7.62,0,1),("1","E",2.54,-7.62,0,-1)],
            body=[(-2.54,-3.81,2.54,3.81)]),
 "BRIDGE":dict(ref="BR", desc="Bridge rectifier (KBP pin order: 1=+ 2=~ 3=~ 4=-)", hide_nums=False,
            pins=[("2","~",-7.62,0,-1,0),("3","~",7.62,0,1,0),
                  ("1","+",0,7.62,0,1),("4","-",0,-7.62,0,-1)],
            body=[(-5.08,-5.08,5.08,5.08)]),
 "LM317":dict(ref="U", desc="LM317 adj regulator (3=IN 2=OUT 1=ADJ)", hide_nums=False,
            pins=[("3","IN",-10.16,0,-1,0),("2","OUT",10.16,0,1,0),("1","ADJ",0,-10.16,0,-1)],
            body=[(-7.62,-5.08,7.62,5.08)]),
 "LM1875":dict(ref="U", desc="LM1875 power amp (1=+ 2=- 4=OUT 5=V+ 3=V-)", hide_nums=False,
            pins=[("1","IN+",-12.7,2.54,-1,0),("2","IN-",-12.7,-2.54,-1,0),
                  ("4","OUT",12.7,0,1,0),("5","V+",0,10.16,0,1),("3","V-",0,-10.16,0,-1)],
            body=[(-7.62,-7.62,7.62,7.62)]),
 "OPAMP8":dict(ref="U", desc="Dual op-amp (TL072 DIP-8 pinout)", hide_nums=False,
            pins=[("3","IN1+",-12.7,5.08,-1,0),("2","IN1-",-12.7,2.54,-1,0),
                  ("5","IN2+",-12.7,-2.54,-1,0),("6","IN2-",-12.7,-5.08,-1,0),
                  ("1","OUT1",12.7,5.08,1,0),("7","OUT2",12.7,-5.08,1,0),
                  ("8","V+",0,10.16,0,1),("4","V-",0,-10.16,0,-1)],
            body=[(-7.62,-7.62,7.62,7.62)]),
 "TP":  dict(ref="TP", desc="Test point (header pin / wire loop)", hide_nums=True,
            pins=[("1","1",0,-2.54,0,-1)],
            body=[(-1.27,0,1.27,2.54)]),
 "OPAMP14":dict(ref="U", desc="Quad op-amp (TL074 DIP-14 pinout)", hide_nums=False,
            pins=[("3","IN1+",-12.7,15.24,-1,0),("2","IN1-",-12.7,12.7,-1,0),
                  ("5","IN2+",-12.7,7.62,-1,0),("6","IN2-",-12.7,5.08,-1,0),
                  ("10","IN3+",-12.7,0,-1,0),("9","IN3-",-12.7,-2.54,-1,0),
                  ("12","IN4+",-12.7,-7.62,-1,0),("13","IN4-",-12.7,-10.16,-1,0),
                  ("1","OUT1",12.7,13.97,1,0),("7","OUT2",12.7,6.35,1,0),
                  ("8","OUT3",12.7,-1.27,1,0),("14","OUT4",12.7,-8.89,1,0),
                  ("4","V+",0,20.32,0,1),("11","V-",0,-15.24,0,-1)],
            body=[(-7.62,-12.7,7.62,17.78)]),
 "SW_SPST":dict(ref="SW", desc="SPST toggle switch (panel)", hide_nums=True,
            pins=[("1","1",-5.08,0,-1,0),("2","2",5.08,0,1,0)],
            body=[(-2.54,-1.27,2.54,1.27)]),
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

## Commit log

2026-06-14 Add reconstructed Parts 1-10, errata, BOM CSV, SPICE netlist, KiCad netlist notes
    Reconstructed from recovered conversation content; see docs/PROVENANCE.md.
    Recovered substantially verbatim: power-supply BOM, power-amp/tremolo/effects
    schematics, gain/bandwidth math, JLCPCB settings, troubleshooting tables,
    LM1875 SPICE netlist, errata issues 1-8, parts-to-reuse and verified-BOM tables.
    [bom.csv]
2026-06-14 Consistency pass, BOM cross-check, KiCad project, and dir build-out
    Resolve errata Issues 9-17 with a fresh cross-document consistency pass;
    cross-check and complete the BOM; re-author the KiCad project and custom
    libraries; and fill the previously empty directories with reference content.
    Errata (docs/errata.md): board-dimension decision point (9); LM317 17V set
    resistor correction R_reg2 3.0k->3.09k for 17.0-17.5V (10); missing HighCurrent
    net class (11); via-drill/trace-width reconciliation (12,13); reverb-pan and
    JFET-bias consistency confirmations (14,15); filter-cap and bypass wording
    (16,17). Folded #10 into Part 2.
    BOM (bom/bom.csv, bom/cross-check.md): add the missing preamp, reve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
    [bom.csv]
2026-06-14 Add validated ngspice block sims; validate KiCad files with kicad-cli
    Installed ngspice + kicad-cli and actually ran everything.
    KiCad: kicad-cli 7.0.11 parses/plots the custom symbol library and footprints
    cleanly (symbol lib re-saved in upgraded format); .kicad_pro is valid JSON.
    SPICE: added an ngspice-runnable companion set for five blocks (the LTspice
    power_amp_lm1875.cir is kept verbatim for provenance):
    - ac_power_amp_lm1875.cir -> gain 27.21 dB (23x); HF -3dB 6.83 kHz with the
    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
    [bom.csv]
2026-06-14 Generate wired hierarchical KiCad schematic (root + 8 sheets)
    Turn SCHEMATIC-BUILD.md from a build guide into actual generated, openable
    schematics. kicad/gen/gen_kicad.py emits a self-contained primitive symbol
    library (cr_primitives.kicad_sym) plus a root sheet and 8 hierarchical
    sub-sheets (power_supply, preamp, tone_stack, reverb, tremolo, mrb, power_amp,
    switching), wired with global labels (rails/cross-sheet) and local labels.
    Verified with kicad-cli 7.0.11: the hierarchy exports a netlist with
    94 components, 56 nets, 0 unconnected pins, no duplicate references; GND spans
    55 nodes and every inter-sheet signal resolves. All sheets render to PDF/SVG.
    References are descriptive (R_fb, C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
    [cambridge_reverb.kicad_sch, mrb.kicad_sch, power_amp.kicad_sch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]
2026-06-14 Schematic passes KiCad 8 ERC (0 violations); add op-amp mid-rail bias
    Installed KiCad 8.0.9 and ran a real Electrical Rules Check on the generated
    hierarchy. Drove it to 0 violations:
    - snapped every pin/wire endpoint to the 1.27 mm connection grid (was 338
    endpoint_off_grid violations)
    - gave the footswitch lines FS_REV/FS_TREM/FS_MRB a real second endpoint via
    100k control pulldowns on the reverb/tremolo/mrb sheets (was 3 dangling labels)
    Also made the single-supply TL072 stages electrically real: added a mid-rail
    VBIAS network (R_vb1/R_vb2 + C_vb on the Power Supply sheet) and referenced the
    reverb driver and tremolo LFO inputs/gain-returns to VBIAS instead of GND
    (design addition, f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
    [cambridge_reverb.kicad_sch, mrb.kicad_sch, power_amp.kicad_sch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]
2026-06-14 Generate auto-placed PCB (102 footprints, GND pour, board outline)
    Build cambridge_reverb.kicad_pcb from the schematic via kicad/gen/gen_pcb.py
    (KiCad 8 pcbnew API): assign a THT footprint to every component (standard libs
    for generics + the project footprints for VTL5C1 and the 1H toroid), place all
    102 footprints (off-board connectors on a bottom wiring-edge strip, toroid in a
    reserved spot), assign all 58 nets to pads, draw a 190x115 mm Edge.Cuts outline,
    and pour a bottom-layer GND plane. Footprint assignments also carry into the
    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
    [cambridge_reverb.kicad_pcb, cambridge_reverb.kicad_sch, mrb.kicad_sch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]
2026-06-14 Route power-section demo (DRC-clean) + chassis-fit density check
    Power-section routing demonstration (kicad/power_section_demo.kicad_pcb): a small
    isolated board that routes the supply's +33V5 rail at 2.5 mm (HighCurrent class)
    and +17V at 1.5 mm (Power class), plus the LM317 ADJ node, over a GND pour.
    kicad-cli pcb drc -> 0 violations. Each rail is routed as a trunk in clear space
    with short stubs from the pads (crossing-free). +27V and VRAW are left as a
    ratsnest on purpose: +27V must cross the +17V trunk, i.e. on a single free layer
    (bottom is the GND pour) it needs a via -- the exact decision full-board routing
    makes throughout.
    Chassis-fit reality check (you said to check it fits the c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
    [cambridge_reverb.kicad_pcb, power_section_demo.kicad_pcb]
2026-06-14 Address Copilot review: fix SPK_P/SPK_N netclass pattern + doc/script nits
    Real fix:
    - kicad/cambridge_reverb.kicad_pro: HighCurrent netclass patterns matched
    SPKR+/SPKR-, but the actual nets are SPK_P/SPK_N -> the speaker current path
    would have fallen back to the Default class (undersized tracks/vias). Patterns
    now match the real net names. Updated the SPKR± references in kicad/README.md
    and production/CHECKLIST.md to match.
    Robustness:
    - spice/run_all.sh: capture ngspice's exit status instead of piping straight to
    grep (which hid failures); the script now exits non-zero if any sim errors,
    while still tolerating "no grep matches".
    Doc accuracy:
    - docs/10-kicad-project.md, CH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
    [cambridge_reverb.kicad_sch, mrb.kicad_sch, power_amp.kicad_sch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]
2026-06-14 first open lol
    [cambridge_reverb.kicad_pcb, cambridge_reverb.kicad_sch, mrb.kicad_sch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]
2026-06-14 Audit pass: center schematic pages, PCB layout audit, SPICE audit
    Schematic: gen_kicad.py now defers draw-op emission, computes each sheet's
    content bounding box, and translates it to the page center (grid-snapped so pins
    stay on the 1.27mm grid). All 8 sheets are centered on the page instead of
    crammed top-left; ERC still 0 violations.
    PCB: full category-by-category audit in kicad/PCB-AUDIT.md (footprints,
    placement, net classes, copper/GND, routing) with prioritized fixes. Applied:
    - the 5 reused/off-board pots were modeled with a 16mm panel-pot footprint; they
    are panel-mounted (wired off-board), so they're now 3-pad wiring connectors --
    more correct and a big silk-overlap source rem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
    [cambridge_reverb.kicad_pcb, cambridge_reverb.kicad_sch, mrb.kicad_sch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]
2026-06-14 Component availability/sockets/current/noise audit; require IC sockets
    Add docs/component-availability-audit.md:
    - Availability tiers: jellybeans (TL072, LM317, diodes, bridge, passives);
    niche-but-stocked (LM1875 single-source, reverb tank, transformer, Fasel);
    WATCH list (small-signal JFETs going EOL industry-wide; VTL5C1 single-source
    Xvive). The two real single-points-of-failure are the JFETs and the LM1875 ->
    buy spares; alternatives noted for each.
    - Sockets: DIP op-amps (IC1/IC2 TL072) now REQUIRED on machined-pin sockets; the
    TO-220 power devices (LM1875, LM317) are heatsink-mounted, not socketed
    (LM1875 thermal path), with an optional LM317 socket line.
    - Current draw: p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
    [bom.csv]
2026-06-15 Keep LM317-input pre-filter (rename +27V->VREG_IN, 47R->100R) - corrected call
    On reflection my earlier "delete R_27V, feed LM317 from +33.5V" recommendation
    was wrong for a noise-conscious design: R_27V + C_filt1 is an RC pre-filter on
    the LM317 input AND decouples the preamp supply from the power amp's transient
    current draw on the +33.5V rail (the LM317's PSRR alone falls off with
    frequency). Deleting it would hurt noise.
    The real bug was the mislabeling: under the modern ~15 mA load the node sits at
    ~32 V, not 27 V, so the "27 V rail / 26-28 V" naming was a leftover misnomer.
    Done instead:
    - keep the element; bump 47R/2W -> 100R/1W (~6 dB more 120 Hz ripple rejection,
    ~1.5 V drop at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
    [bom.csv, cambridge_reverb.kicad_pcb, cambridge_reverb.kicad_sch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]
2026-06-16 Roast pass (2026-06-16): fix missing mains fuse, correct 18W->~12W spec, +more
    Adversarial review (docs/roast-2026-06-16.md), every finding verified by math or
    file. Fixes applied:
    R1 (SAFETY, was missing): added a MAINS PRIMARY fuse. The only fuse was a 1A on
    the secondary DC rail, which doesn't protect against a primary/transformer/
    bridge fault. Added T800mA/250V (120V; ~T400mA at 230V) to BOM + Part 1 safety
    + Part 3.
    R2 (spec error I propagated last pass): "18 W into 8 ohm" is physically
    unreachable on a 33.5 V single rail -- needs 17.0 V peak, only 16.75 V exists.
    Real ceiling ~12 W clean (17.5 W absolute). Corrected Part 1 sec.3, Part 5
    thermal, and the component-av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
    [bom.csv, cambridge_reverb.kicad_pcb, cambridge_reverb.kicad_sch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]
2026-06-16 Redesign effects chain: active reverb summer + output buffer + split bias
    Resolves roast R3 (broken passive mixer) and R6 (shared VBIAS bleed), using the
    two spare TL072 halves and verifying with a rail-aware SPICE model.
    - Reverb wet/dry mix is now an ACTIVE inverting summer on IC1-B (dry always on,
    wet via POT_REV, unity each, low-Z out about VBIAS_R). Removed the broken
    passive R_dry_tap/R_blend1/R_blend2 (1M dry series made it ~all-wet into an
    unbuffered 110k node).
    - IC2-B repurposed as the post-MRB OUTPUT BUFFER driving PA_IN (removed the
    unbuffered R_painput 1M and a dead C_trem_out/R_trem_pass branch).
    - VBIAS split into independent VBIAS_R (reverb) and VBIAS_T (tremolo) div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
    [bom.csv, cambridge_reverb.kicad_pcb, cambridge_reverb.kicad_sch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]
2026-06-16 Generate BOM from schematic (authoritative); complete missing schematic parts
    The BOM had drifted badly from the schematic (~20 parts in the schematic missing
    from the BOM, ~20 stale/renamed rows in the BOM). Root-caused two ways:
    1. Completed the SCHEMATIC -- added parts that were in Part 2 / the BOM but never
    actually placed: rectifier snubbers C101-C104, 2nd pre-filter C_filt2, and the
    tremolo SPEED/DEPTH pots (POT_SPD as a rheostat in the Wien series arm to vary
    frequency; POT_DPT scaling the LFO into the VTL1 LED for depth). 117 comps, ERC 0.
    2. Made the BOM GENERATED from the schematic: kicad/gen/gen_bom.py emits bom/bom.csv
    per-reference 1:1 with the netlist (verified: e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
    [bom-grouped.csv, bom.csv, cambridge_reverb.kicad_pcb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]
2026-06-16 Design + verify the tone stack (Vox treble-cut substitute)
    The tone sheet was a TBD placeholder (original 25-5274-2 values never recovered).
    Replaced with a working passive Vox-style control: Volume pot + a treble "cut"
    (C_cut 10nF + POT_TONE 100k to ground). Verified in spice/ac_tonestack.cir:
    flat at bright (-1.6 dB, just insertion loss), musical treble cut at the dark end
    (-9 dB @ 5 kHz, -14 dB @ 10 kHz). Clearly flagged as a designed substitute (the
    original panel may have had separate Treble/Bass) in the sheet note, cross-check
    #4, and spice/README.
    All 7 ngspice blocks now pass (added ac_tonestack.cir). ERC 0, demo DRC 0, BOM
    regenerated from the schematic (no TBD rows left).
    https:/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
    [bom-grouped.csv, bom.csv, cambridge_reverb.kicad_pcb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]
2026-06-16 Normalize BOM value strings; refresh stale top-level README
    - gen_kicad NV(): normalize value strings for a tidy/consolidated BOM (2K2->2.2k,
    4K7->4.7k, drop the " film" descriptor that the footprint already conveys).
    Cosmetic only; ERC 0, demo DRC 0, SPICE exit 0, BOM regenerated.
    - README rewritten to reflect the actual current state instead of the original
    reconstructed-docs snapshot: the generated + tool-verified KiCad/BOM/ngspice
    flow, the verified ~12 W power ceiling (not 18 W), the required mains fuse, the
    190x115 board + chassis-fit caveat, the active effects-chain/tone redesigns,
    and the provenance/honesty framing.
    https://claude.ai/code/session_01PkrfUi9tvZfLvudJ7h23qD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
    [bom-grouped.csv, bom.csv, cambridge_reverb.kicad_pcb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]
2026-06-17 Explore Class-A power amp (sim + design note) -- AC15-style
    Adds spice/tran_classa_output.cir (transistor-level, single +33.5V rail) and
    docs/classA-power-amp.md. Sim shows the case for Class A and the cost:
    - class AB (small idle ~0.11A): THD ~1.05% (crossover notch)
    - Class A (idle ~0.49A, >= peak load current): THD ~0.0025% (no crossover)
    - the tax: ~16W continuous heat for ~1W of pure Class A (then slides to AB to
    the ~12W ceiling) -- "Class A for the first watt, AB beyond", ideal for guitar.
    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
2026-06-17 Build Class-A power-amp variant (LM317 CCS-biased LM1875), alongside AB
    Per the scope choice (variant alongside AB, ~0.5A): kicad/gen/gen_classa.py emits
    a standalone, ERC-clean kicad/power_amp_classa.kicad_sch -- the same LM1875 stage
    plus U_ccs (LM317 as a constant-current sink, R_set 2.5R -> I=1.25/2.5=0.5A from
    PA_OUT to GND), so the LM1875 runs single-ended Class A up to ~1W into 8 ohm and
    reverts to push-pull AB above. The main board stays Class AB; this is a drop-in
    alternative.
    Variant adds vs AB: a 2nd LM317 (heatsinked, ~7.5W) + R_set 2.5R/2W + <=1.5 C/W
    sinks (the ~16W standing heat splits ~8W each across LM1875 + LM317). Documented
    in docs/classA-power-amp.md with the BOM delta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
    [power_amp_classa.kicad_sch]
2026-09-06 Datasheet footprints, floor-plan placement, headless autoroute (144/145, DRC 0)
    PCB-AUDIT s1 fixes with datasheet-derived project footprints:
    - TO-220-5_Vertical_P1.70mm_LM1875 (TI NDH0005D): 1.45 mm pads on the 1.1 mm
    drill -> 0.175 mm annular (was 0.0875, 5 DRC errors); pad-local 0.2 mm clearance
    - Bridge_KBP_P3.81mm (Diodes DS39310 KBP404G-KBP410G, pins + ~ ~ -); bridge
    symbol renumbered to the physical order; errata #3 updated (KBU needs a swap)
    - value-aware CP/R sizing (real can sizes for 4700/2200/1000 uF, 5 W / 1 W
    resistors, fat pads on the 0R speaker return); Part 4 wire pads for all
    off-board wiring (2.0 mm/1.2 mm signal, 3.0 mm/1.5 mm speaker + transformer)
    - VRAW/AC1/AC2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
    [bom-grouped.csv, bom.csv, cambridge_reverb.kicad_pcb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]
2026-09-06 Add 26 labelled bench test points (schematic + BOM + silk) and re-route
    Test points follow the Part 5 bring-up order: rails (VRAW, +33V5, VREG_IN,
    +17V), JFET drains Q1D/Q2D/QRD (the errata #15 bias trim), the VBIAS_R/VBIAS_T
    mid-rail refs, every inter-stage node (PREAMP_OUT, TONE_OUT, BLEND, TREM_OUT,
    MRB_OUT, PA_IN), tank drive/return, LFO, PA_BIAS/PA_OUT/SPK_P, and a GND pin
    per zone for the probe clip.
    - gen_kicad.py: one-pin TP symbol; TEST_POINTS table; add_test_points() puts
    them on their sheets so they are in the netlist and the BOM (one order line)
    - footprint TestPoint_THT_D2.0mm_Label: 2.0 mm pad / 1.0 mm drill for a header
    pin or wire loop; the footprint VALUE (= net alias)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
    [bom-grouped.csv, bom.csv, cambridge_reverb.kicad_pcb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]
2026-09-07 Mixed SMD/THT variant (kicad/smd, 155x90), JFET pin-number fix, THT fully routed
    Build profiles: gen_kicad.py / gen_pcb.py / gen_bom.py take --profile tht|smd.
    One schematic source; the smd profile remaps footprints and writes a self-
    contained KiCad project to kicad/smd/ (cambridge_reverb_smd.*, lib tables one
    level up), sized 155 x 90 mm for the Part 7 safe-bet chassis.
    SMD (70 parts): 0805 R (1206 for R_reg2), 1206 C <= 100 nF, 1210 for 120 nF /
    1 uF / C_zobel, SMA + SOD-123 diodes, SOT-23 JFETs fitted directly.
    Deliberately THT: power parts, all electrolytics (standing cans use less board
    than SMD cans), DIP-8 sockets for the TL072s, the three bench-trimmed JFET
    source resistors, LED, c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
    [bom-jlcpcb.csv, bom-smd-grouped.csv, bom-smd.csv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]
2026-09-07 Commit the datasheets (13 PDFs + manifest), check script, and ERC/DRC reports
    datasheets/: the manufacturer PDFs the footprints, pinouts and design numbers
    came from -- LM1875 (SNAS524A), LM317 (SLVS044Z), TL072 (SLOS080W), MMBF5457
    (onsemi Rev.1 2023), 2N5457 (onsemi Rev.6 2010), J111-J113 (onsemi Rev.2 2006),
    KBP404G-KBP410G (Diodes DS39310) + KBP005G-KBP10G (DS21203), 1N4001-1N4007 and
    1N4148 (Vishay), 1N4148W (Diodes DS30086), VTL5C1/5C2 (PerkinElmer/Vactec
    catalog page), AnTek AS-0524 test sheet. SOURCES.md is the manifest: source URL,
    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
2026-09-07 Track the ERC reports in kicad/reports (an ignore rule caught *.rpt)
    Claude-Session: https://claude.ai/code/session_01Vk8HkvCugxFpQsBPVnNT2H
2026-09-07 SPICE parameter sweeps with committed results; tremolo LFO fix (errata #19); re-route
    spice/: six ngspice sweeps next to the fixed-point checks, and run_all.sh now
    saves every result table to spice/results/ (committed evidence):
    - sweep_preamp_bias: Vd vs R_s for LO/TYP/HI JFET corners (datasheet Idss 1/3/5
    mA). The recovered 2.2k suits a HIGH-Idss part (8.8 V); a typical part wants
    ~1.0k (8.5 V); a 1 mA part cannot reach 8-9 V at any R_s -> errata #15 quantified
    - sweep_tonestack: response over the whole pot travel (1 kHz -1.6..-3.3 dB while
    10 kHz falls 14 dB)
    - sweep_lfo_speed_recovered: the recovered single-arm Wien LFO oscillates only for
    pot <= ~27k (5 % of travel) at 45-80 Hz,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
    [bom-grouped.csv, bom-jlcpcb.csv, bom-smd-grouped.csv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]
2026-09-07 Tone stack: Bass + Treble (passive James) with a switchable mid cut (errata #20)
    The panel has Bass and Treble pots, but the design carried a single treble-cut
    "Tone" substitute -- and the recovered preamp coupling was the 470 pF chime cap
    alone, a 1.3 kHz high-pass that passed no bass at all. Replace both:
    - C_cpl_out 1 uF full-band coupling from Q2's drain; C_treble 470 pF becomes a
    bright cap across the top of the volume pot.
    - Passive James (Thomas-Vox) Bass/Treble network -- the originals' topology,
    asymmetric, more cut than boost, kept over an active Baxandall so the amp
    keeps its character -- driven by a TL074 (IC3: input buffer, x2 make-up,
    gyrator, output buffer) on its own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
    [bom-grouped.csv, bom-jlcpcb.csv, bom-smd-grouped.csv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]
2026-09-07 Noise, hum, crosstalk and thermal models; three design fixes; JLCPCB rules and cost
    New models (docs/06c, spice/): a .noise run of the whole front end including the
    LM317's own rail noise, the rail-ripple paths to the speaker, a vactrol-level tremolo
    depth model, an electro-thermal LM1875 ladder, and a geometric crosstalk audit of the
    routed boards (kicad/gen/crosstalk_audit.py). They found three defects:
    - Errata #21 (hum + hiss): the LM1875 bias divider had no bypass (+4 dB ripple to
    speaker, 0.4 Vrms of 100 Hz at idle) and the LM317's 0.5 mV of noise reached the
    0 dB-PSRR JFET stages (23 dB above their floor, SNR 34 dB). Fixed with C_bref +
    R_bias3 on the power amp, C_adj on the re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
    [bom-grouped.csv, bom-jlcpcb.csv, bom-smd-grouped.csv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]
